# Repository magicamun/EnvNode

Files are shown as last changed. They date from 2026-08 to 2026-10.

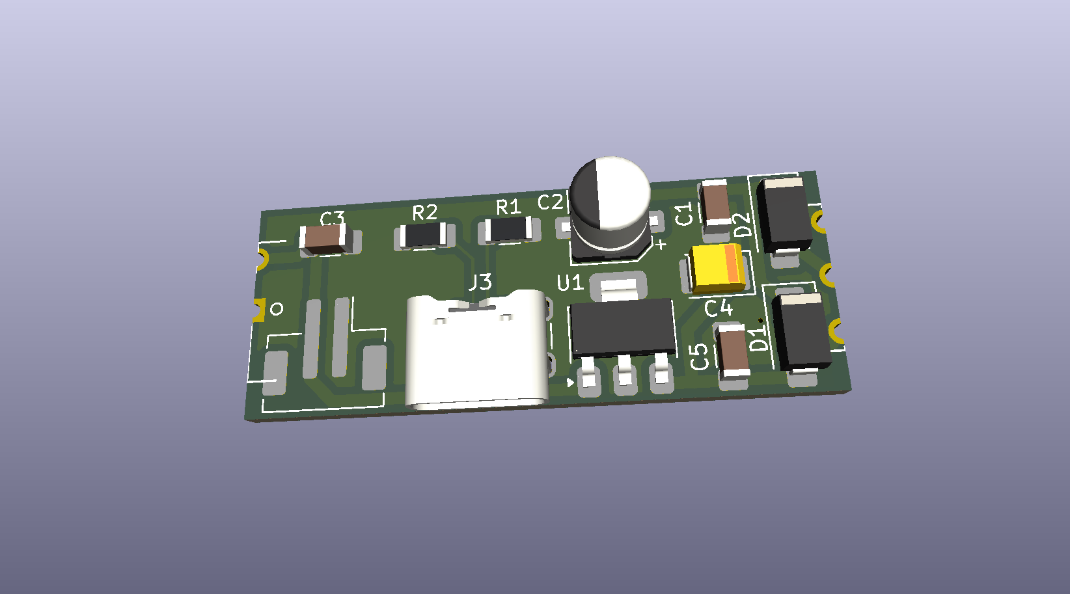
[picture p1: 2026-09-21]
hardware/kicad/DesignBlocks/ORing Power/Documentation/ORing_Power_3D.png

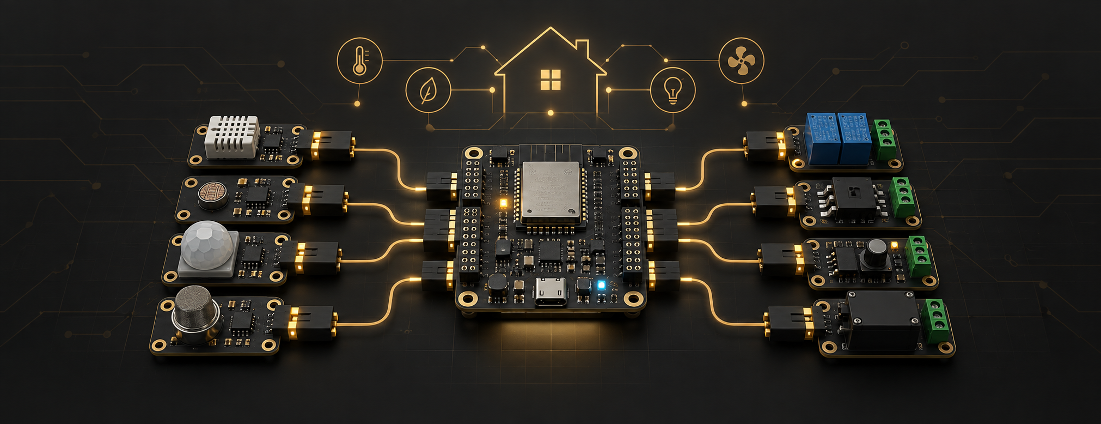
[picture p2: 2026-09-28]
images/branding/envnode-hero-modular-v1.png

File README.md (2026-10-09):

# EnvNode

EnvNode is an source-available ESP32-based embedded platform for reliable environmental measurements and seamless integration into modern home automation systems.

WeatherStation is the first reference application built on the reusable EnvNode platform.

The project intentionally separates **measurement** from **interpretation**.

The firmware is responsible for acquiring reliable physical Measurements and publishing them to external systems.

Higher-level concepts such as weather interpretation, historical aggregation, evapotranspiration (ETo), irrigation logic and visualization intentionally remain outside the firmware.

EnvNode is developed as a complete source-available product including:

- firmware
- hardware (KiCad)
- documentation
- development tooling

The goal is not to build another weather dashboard.

The goal is to build a reliable measurement platform.

---

# Vision

EnvNode provides an open, transparent and extensible weather sensor platform for Home Assistant and other home automation systems.

The ESP32 acts as a dedicated measurement node.

It acquires physical sensor data, performs only the hardware-related processing required to obtain reliable Measurements and publishes them via MQTT.

The firmware intentionally remains deterministic, maintainable and independent from weather-specific interpretation.

This allows higher software layers to evolve independently while keeping the embedded firmware simple and robust.

---

# Why another weather station?

The project originated from practical experience with an existing DIY weather station.

Although the hardware proved to be reliable, several software aspects became increasingly problematic:

- closed-source firmware
- undocumented algorithms
- incorrect sunshine duration calculation
- embedded rain aggregation
- limited extensibility
- unclear separation between measurement and interpretation

Rather than replacing individual algorithms, the firmware was redesigned from first principles around a small number of architectural rules.

---

# Core Philosophy

The EnvNode project follows one simple principle:

> Measure first.
>
> Interpret later.

The firmware exists to acquire reliable Measurements.

Interpretation belongs to external systems.

---

# Project Goals

- source-available firmware with a commercial exploitation reservation
- available hardware design sources (KiCad)
- MQTT-based integration
- browser-based configuration
- OTA firmware updates
- modular architecture
- high-quality Measurements
- deterministic firmware behaviour
- long-term maintainability
- simulation support
- comprehensive documentation
- hardware independence

---

# Design Principles

The project follows a small number of architectural principles.

### Measure, don't interpret

The firmware measures physical reality.

Interpretation belongs outside the Device.

---

### One technical responsibility per service

Each infrastructure service owns exactly one technical responsibility.

Examples include:

- Configuration
- WiFi
- Time
- MQTT

---

### Sensors produce Measurements

Sensors do not publish MQTT.

Sensors do not interpret weather.

Sensors produce Measurements.

### Controllers coordinate Actuators through capabilities

Controllers implement cooperative local behavior and address configured Actuators by `ActuatorId` and capability. They do not manipulate GPIO or use MQTT as an internal control path.

---

### Configuration has one authoritative owner

Configuration exists exactly once inside the runtime.

Every subsystem uses the same Configuration.

---

### Simulation is part of the architecture

Simulated and physical Sensors follow the same processing pipeline.

Replacing a simulated Sensor with a physical implementation must not require architectural changes.

---

### Observable behaviour

Whenever practical, internal decisions should be visible through:

- diagnostics
- logging
- MQTT status

The firmware should never behave like a black box.

---

### Deterministic firmware

The firmware intentionally avoids executing complex weather models.

Embedded software should remain predictable and responsive.

---

### Hardware independence

Application logic depends on abstract Sensor behaviour rather than concrete hardware implementations.

Replacing a Sensor should require only a new driver.

---

# Current Status

Implemented

- ESP32 PlatformIO project
- persistent configuration
- browser-based provisioning
- WiFi connectivity
- automatic WiFi reconnect
- setup access point
- configurable hostname
- SNTP time synchronization
- configurable timezone
- MQTT connectivity
- authenticated MQTT client
- factory reset and OTA firmware update
- typed Measurement pipeline and MQTT publication
- fixed Sensor slots, physical/simulated implementations and live runtime composition
- Sensor Home Assistant discovery
- EEPROM-backed Board Identity, boot-time profile resolution and development fallback
- Board Identity diagnostics and confirmed Web provisioning with readback verification
- independent Module Identity discovery for both slots, immutable module profiles and
  board/slot compatibility diagnostics without automatic driver activation
- fixed Actuator slots and unified hardware validation
- OnOff capability and GPIO On/Off Actuator
- Level capability and GPIO PWM Actuator
- live Actuator runtime rebuild
- Web and MQTT Actuator configuration/control
- fixed Controller slots and BlinkController
- ThresholdController with typed Measurement input, hysteresis and monotonic freshness
- cooperative Controller runtime and live rebuild
- Web and MQTT Controller configuration, status and Start/Stop
- persistent MQTT Blink/Threshold parameter commands and retained parameter state
- retained external Actuator and Controller descriptions
- exclusive enabled-Controller ownership of Actuator targets
- physically verified Sensor -> Measurement -> Controller -> Actuator operation

Current hardware-validation focus

- provision and boot from the Board Identity EEPROM on a physical Mainboard revision 0.3
- complete the Revision 0.3 article list and assembly data
- assemble and bring up the AnalogHydroPressure module, including its local 5 V to 24 V supply
- integrate and calibrate the ADS1115-based 4–20 mA pressure input on real hardware
- operate at least the Rain Detector heater path before releasing Revision 0.3 for production

Deliberately future

- additional Actuator capabilities beyond OnOff and Level, and additional typed Controller implementations
- multi-input, Boolean/contact and event-driven Controllers
- richer manual-versus-Controller arbitration
- Controller and generic Actuator Home Assistant discovery
- a dedicated provisioning station for preparing Mainboards, Modules, and other supported boards

---

# Documentation

Project documentation is intentionally separated by responsibility.

| Document | Purpose |
|---|---|
| README.md | Project overview |
| DomainModel.md | Functional domain concepts |
| TechnicalArchitecture.md | Technical architecture |
| ActuatorModel.md | Actuator capabilities and Controller interaction |
| MQTT.md | Current MQTT protocol boundaries and topics |
| Hardware.md | Hardware entry point, module templates, and implemented boards |
| ADRs | Architectural decisions |

---

# Non Goals

EnvNode intentionally does not:

- perform weather forecasting
- calculate evapotranspiration (ETo)
- calculate sunshine duration
- aggregate historical weather data
- store long-term measurements
- replace Home Assistant

These responsibilities belong to higher software layers.

---

# Project Status

The Sensor, Actuator and Controller architecture is implemented and physically verified. Current open work concerns further capabilities, Controller implementations and external self-description rather than replacing these runtime boundaries.

# License and permitted use

EnvNode-owned materials are provided under the [EnvNode Use and Redistribution
License, version 1.0](LICENSE). Private and internal business use, modifications,
free redistribution, and paid fabrication or maintenance for the user's own use
are permitted. Commercial product sales, licensing, rental, and standalone paid
software hosting require separate permission. Third-party materials retain their
respective licenses. This is a custom source-available license, not an
OSI-approved open-source license. The German license text is authoritative.

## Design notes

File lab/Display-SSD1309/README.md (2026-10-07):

# SSD1309 I2C Display Lab

Eigenständiger Hardwaretest für das vorhandene 2,42-Zoll-OLED (128 × 64,
Platinenaufdruck `2.42OLED-IIC VER:1.1`). Die gescannte 7-Bit-Adresse ist
`0x3C`. SSD1309 NONAME2 ist zunächst eine zu prüfende Controllerannahme.
Keine Abhängigkeit von der EnvNode-Firmware; keine NVS-Konfiguration.

## Anschluss

Lab-Vorgaben für einen klassischen ESP32 (`esp32dev`):

| Display | ESP32 | Kabelfarbe auf dem Foto |
| --- | --- | --- |
| GND | GND | Weiß |
| VDD | Versorgung gemäß Modul-Spezifikation | Gelb |
| SCL | GPIO 22 | Schwarz |
| SDA | GPIO 21 | Rot |

Pins, Adresse und Bustakt (100 kHz) stehen in `include/LabConfig.h`.
Die Versorgungsspannung ist durch das Foto nicht belegt. Am ESP32 müssen
SDA/SCL mit 3,3-V-Pegeln arbeiten; etwaige Modul-Pull-ups berücksichtigen.
Die Lab-Pins müssen auf dem Testaufbau frei sein.

## Testbild und Auswertung

Sechs feste Beispielzeilen, Font `u8g2_font_t0_11_tf`, Baselines bei
10, 20, 30, 40, 50 und 60 Pixeln. Datum und Messwerte sind Testtexte,
keine Uhr oder echten Messwerte. Rotation ist `U8G2_R0`.

Der Start prüft zunächst ein ACK an `0x3C`. Ohne ACK werden keine
Displaybefehle gesendet. Mit ACK wird die Seite einmal übertragen.
Ein ACK bestätigt lediglich einen Teilnehmer, nicht den Controllertyp oder
eine erfolgreiche Darstellung. U8g2 erhält die Adresse als `0x3C << 1`.
Im seriellen Monitor erscheinen die Pixelbreiten aller sechs Zeilen.

Prüfen: Sind alle sechs Zeilen vollständig, lesbar und richtig ausgerichtet?
Bleibt das Display trotz ACK leer oder zeigt es Müll, Controller/Variante
anhand Produktunterlagen prüfen. Ein erfolgreicher Build bestätigt die
Hardwareannahme nicht. Für 180° Rotation `U8G2_R0` durch `U8G2_R2` ersetzen.

## Build und Flash

PlatformIO: Espressif32 7.0.1, Arduino, U8g2 2.36.12.
Vom Repository-Root:

```sh
pio run -d lab/Display-SSD1309
pio device list
pio run -d lab/Display-SSD1309 -t upload --upload-port /dev/cu.usbserial-1
pio device monitor -p /dev/cu.usbserial-1 -b 115200 --filter direct
```

Falls nötig `~/.platformio/penv/bin/pio` verwenden und den Port ersetzen.
Flashen ersetzt die laufende Firmware des gewählten ESP32. Nach Öffnen des
Monitors ggf. Reset drücken. Der Nutzer hat den Lab-Test auf dem vorhandenen Modul erfolgreich geflasht und
die Darstellung bestätigt.

Referenz: [U8g2-Konstruktoren](https://github.com/olikraus/u8g2/wiki/u8g2setupcpp#ssd1309-128x64_noname2).

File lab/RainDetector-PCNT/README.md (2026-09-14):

# RainDetector PCNT Lab-Firmware

Eigenständiger PoC für den digitalen 3,3-V-Ausgang eines ICM7555.
Keine Abhängigkeit von `firmware/`, keine EnvNode-Sensorintegration, kein
MQTT, keine Wetterinterpretation, Kapazitätsberechnung oder Heater-Steuerung.

## Projekt und Toolchain

Die produktive PlatformIO-Konfiguration verwendet `esp32dev`, Arduino und eine
ungepinnte `espressif32`-Plattform. Dieses Lab-Projekt fixiert die bei der
Implementierung installierte Plattform auf **7.0.1**. Der geprüfte Build nutzt
Arduino-ESP32 **2.0.17** (Paket `3.20017.241212+sha.dcc1105b`) und dessen
ESP-IDF **4.4.7**. Es benötigt keine zusätzlichen Bibliotheken.

Verwendet wird die klassische API aus `driver/pcnt.h`, PCNT Unit 0 / Channel 0:
`pcnt_unit_config`, `pcnt_counter_clear`, `pcnt_counter_resume`,
`pcnt_counter_pause` und `pcnt_get_counter_value`.
Steigende Flanken inkrementieren; fallende Flanken werden ignoriert.
Filter und CPU-PCNT-Interrupts sind deaktiviert. Es gibt keine ISR,
kein `pulseIn()` und keine GPIO-Abfrageschleife.

Referenz: [Espressif PCNT API für ESP-IDF 4.4](https://docs.espressif.com/projects/esp-idf/en/v4.4/esp32/api-reference/peripherals/pcnt.html).

## Anschluss und Konfiguration

- ICM7555 `RAIN_FREQ` (digital, 3,3 V) an **GPIO 27** des klassischen ESP32.
- Gemeinsame Masse zwischen RainDetector und ESP32 herstellen.
- Keine 5-V-Signale einspeisen. GPIO 27 muss auf dem verwendeten Aufbau frei sein.
- Heater separat unbeschaltet bzw. hardwareseitig ausgeschaltet halten;
  diese Firmware initialisiert keinen Heater-Ausgang.
- GPIO, Messfenster und Baudrate stehen zentral in `include/LabConfig.h`.
  GPIO 27 ist eine Lab-Vorgabe, keine Zuordnung aus einem EnvNode-Boardprofil.
- Getestetes Build-Ziel ist `esp32dev`, nicht ESP32-C3/S3 oder andere Varianten.

## Messung und Grenzen

Der Zähler wird bei pausierter Messung gelöscht, dann gestartet und nach
nominell **250.000 µs** angehalten. Währenddessen gibt `delay(1)` CPU-Zeit frei;
PCNT zählt unabhängig weiter. Die Dauer wird über `esp_timer_get_time()` direkt
vor Resume und direkt nach Pause erfasst. Die Rechnung lautet:

`frequency_hz = pulse_count * 1000000.0 / (end_us - start_us)`

Das reale Fenster ist durch Task-Scheduling etwas länger als 250 ms und nicht
hardwaregenau getaktet. Die Zeitmessung umfasst zusätzlich den kleinen Aufwand
der Resume-/Pause-Aufrufe; sie ist eine Näherung der tatsächlichen Zählzeit.
Eine konkrete Dauer am Zielgerät wurde noch nicht gemessen. Drei Nachkommastellen
der Ausgabe sind keine Genauigkeitszusage: die Zählauflösung liegt bei etwa 4 Hz
pro Puls; hinzu kommen Gate-Timing- und ESP32-Taktfehler.

Serial-Ausgabe und Reset passieren zwischen den Fenstern. Es gibt daher eine
kurze Messpause; Zeitstempelabstände sind nicht gleich der Zählfensterdauer.
Die Firmware misst Fensterfrequenzen, keinen lückenlosen Gesamtpulszähler.

Der 16-Bit-PCNT setzt beim oberen Limit von 32767 Pulsen auf null zurück.
Um dann keine falsche niedrige Frequenz auszugeben, wird ausschließlich das
High-Limit-Ereignis aktiviert. Dessen gelatchtes Raw-Interrupt-Bit wird nach
Pause geprüft und vor jedem Fenster gelöscht (`PCNT.int_raw` / `PCNT.int_clr`,
klassische ESP32-Register). Dafür wird kein CPU-Interrupt aktiviert.
Ein Überlauf ergibt `nan` statt einer Frequenz; `pulse_count` ist dann nur der
Restzählerstand. Bei 250 ms liegt die Grenze ungefähr bei 131 kHz, bei längeren
Fenstern entsprechend niedriger. Für einige 10 kHz reicht der Zähler aus.

## Serial-Format

115200 Baud, 8N1. Einmalig nach Initialisierung:

```csv
timestamp_ms,pulse_count,frequency_hz
```

Danach eine Zeile je Fenster mit dezimalem Punkt und drei Nachkommastellen.
`timestamp_ms` bezeichnet das Fensterende in Millisekunden seit Boot.
Beispielwerte (keine reale Hardwaremessung):

```csv
1250,10000,40000.000
1505,0,0.000
1760,123,nan
```

Ohne Flanken ist das Ergebnis null; ein fehlendes Signal lässt sich daraus
nicht von einem stillstehenden Oszillator unterscheiden. Bei einem API-Fehler
erscheint `# error,<operation>,<ESP-Fehlername>` und die Messung stoppt bis Reset.
ESP32-ROM-Bootmeldungen können vor dem CSV-Header erscheinen. Für Auswertung
erst ab dem Header lesen und Fehlerzeilen bzw. `nan` behandeln.

## Build, Flash und Test

Vom Repository-Root aus (falls `pio` nicht im PATH liegt:
`~/.platformio/penv/bin/pio` verwenden):

```sh
pio run -d lab/RainDetector-PCNT
pio device list
pio run -d lab/RainDetector-PCNT -t upload --upload-port /dev/cu.usbserial-0001
pio device monitor -p /dev/cu.usbserial-0001 -b 115200 --filter direct
```

Den Beispielport durch den tatsächlichen ESP32-Port ersetzen. Flashen ersetzt
die aktuell auf diesem ESP32 laufende Firmware. Nach Öffnen des Monitors bei
Bedarf Reset drücken, um den CSV-Header zu erfassen.

Zunächst Signal und gemeinsame Masse verbinden, dann die Frequenz mit
Oszilloskop/Frequenzzähler vergleichen. Optional einen bekannten 3,3-V-Takt
einspeisen: 40 kHz sollten bei ungefähr 250 ms ungefähr 10000 Pulse ergeben,
unabhängig vom Tastverhältnis (innerhalb der PCNT-Eingangsgrenzen).
Mit auf GND gelegtem Eingang müssen null Pulse erscheinen. Optional mit
150 kHz testen: die Frequenz muss `nan` werden. Den ICM7555-Ausgang vor
Einspeisung eines externen Testtakts trennen.

Build und Quellcodeprüfung sind erfolgt; Flashen und Hardwaretests sind noch
nicht durchgeführt worden.

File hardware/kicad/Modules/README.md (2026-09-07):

# EnvNode Revision 0.3 Modules

This directory contains the current module templates and functional daughterboards for the EnvNode Revision 0.3 module interface. The electrical connector contract was introduced with Revision 0.2 and is retained by the current Revision 0.3 designs.

## Functional Modules

- [FullSize/AnalogHydroPressure](FullSize/AnalogHydroPressure/README.md): ADS1115-based 4–20 mA pressure input with a local 5 V to 24 V boost supply.
- [FullSize/DuoRelay](FullSize/DuoRelay/README.md): two independently controlled 5 V changeover relays.

## Starting Templates

| Size | Bottom-mounted connector |
| --- | --- |
| [FullSize/Empty-SMD](FullSize/Empty-SMD/README.md) | SMD |
| [FullSize/Empty-THT](FullSize/Empty-THT/README.md) | THT |
| [HalfSize/Empty-SMD](HalfSize/Empty-SMD/README.md) | SMD |
| [HalfSize/Empty-THT](HalfSize/Empty-THT/README.md) | THT |

New modules must follow the [module-interface hardware specification](../../../docs/EnvNode_Module_Interface_Hardware_Specification.md). Copy the appropriate template instead of modifying it in place, preserve the connector pin mapping and mechanical reference geometry, and rerun ERC and DRC after every functional or layout change.

## Release Status

Revision 0.3 is not yet released for production. Release requires a complete article list and assembly information, physical bring-up of the relevant boards, and successful operation of at least the Rain Detector heater path. A later provisioning station is intended to prepare Mainboards, Modules, and other supported boards with their identities and required initial data.

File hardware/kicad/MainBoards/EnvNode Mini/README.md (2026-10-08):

# EnvNode Mini

`EnvNode Mini` is the compact EnvNode mainboard with two module slots, ESP32 processing, dual I²C access, configurable I²C pull-ups, and two direct ADC/GPIO inputs. This directory contains the KiCad design for hardware Revision 0.8.

## Project Files

- `EnvNode Mini.kicad_pro`
- `EnvNode Mini.kicad_sch`
- `EnvNode Mini.kicad_pcb`
- `SlotA.kicad_sch`
- `SlotB.kicad_sch`
- `ESP32Core.kicad_sch`
- `PCB.kicad_sch`
- `Power.kicad_sch`
- `ADC.kicad_sch`
- `Documentation/EnvNode_Mini_Bestueckungs_und_Bringup_Rev0.8.pdf`

KiCad lock and local preference files are working files and must not be committed.

## Revision 0.8

Revision 0.8 adds two top-entry 4-pin JST-PH connectors. Connector `ADC1` exposes GPIO34 / ADC1_CH6 and connector `ADC2` exposes GPIO35 / ADC1_CH7. Their shared pin order is GND, `+5V`, signal, `+3V3_SYS`.

GPIO34 and GPIO35 are input-only ESP32 pins without internal pull-up or pull-down resistors. They are not 5 V tolerant. The `+5V` connector pin is available only as sensor power; any signal returned to connector pin 3 must remain inside the ESP32 3.3 V input range. Firmware must not configure these resources as outputs.

Final checks on 2026-09-29: ERC has zero findings. PCB DRC with zone refill has no active violations or unconnected pads, and schematic/PCB parity is clean. The report contains 18 documented exclusions for known courtyard and silkscreen interactions; none concerns copper clearance, connectivity, or the new ADC nets.

## Revision 0.7

Revision 0.7 corrects I2C0 on both module slots to pin 5 SDA and pin 6 SCL, matching the module-interface specification and daughterboards. The corrected MainBoard connector design block is incorporated. Connector and mounting-hole positions are unchanged. AUX_GPIO1 remains GPIO33 in Slot A and GPIO32 in Slot B.

Final checks on 2026-09-28: ERC has zero findings; PCB DRC with zone refill has no unconnected pads or schematic/PCB parity issues. Two active silkscreen-over-solder-mask warnings remain at U2 pads 3 and 5; sixteen other findings are excluded in the project. This is not a zero-warning manufacturing release.

## Revision 0.6

Revision 0.6 restructures the mainboard around reusable hierarchical design blocks. The 5 V input protection, regulator, and 3.3 V source ORing are provided by the castellated `ORing Power` module (`U2`) instead of being assembled directly on the mainboard. The ESP32 core contains the `24LC32` mainboard-identity EEPROM (`U1`) on `I2C0` at address `0x50` on the `+3V3_SYS` supply. C1 (100 nF) is connected between `+5V` and GND and decouples the 5 V supply. The identity EEPROM has no separate local decoupling capacitor; this arrangement is identical on EnvNode Mini and EnvNode Weather.

The two module slots continue to implement the shared EnvNode module interface. Net ties set Slot A `EEPROM_A0` to GND and Slot B `EEPROM_A0` to `+3V3_SYS`, assigning the optional module EEPROM addresses `0x52` and `0x53`. Each I²C bus is available on two top-entry, four-pin JST-SH connectors. Individually configurable 4.7 kΩ pull-ups remain normally disconnected through solder jumpers.

The mainboard itself no longer carries a USB or raw 5 V input connector. Power is connected to the fitted ORing Power module; its assembly and input-source rules apply to the complete unit. The module's `+3V3_EXT` interface pin is intentionally not connected on this mainboard revision.

## Module GPIO assignment

| Slot | Pin 9 / AUX_GPIO1 | Pin 10 / AUX_GPIO2 | Pin 14 / SPI_CS |
| --- | --- | --- | --- |
| A | GPIO33 (ADC1_CH5) | GPIO13 | GPIO5 |
| B | GPIO32 (ADC1_CH4) | GPIO14 | GPIO27 |

AUX_GPIO1 supports digital input, digital output/PWM, or analog input while Wi-Fi is active. AUX_GPIO2 supports digital input and output/PWM; its ADC2 function is not available during Wi-Fi operation. GPIO4 and GPIO16 are now unconnected. Firmware slot mappings must follow this assignment.

Revision 0.7 slot wiring is I2C0 SDA on pin 5 and SCL on pin 6, matching AnalogHydroPressure and SX1262-Remote.

## Validation

Run schematic ERC and PCB DRC after every schematic, footprint, routing, zone, or rule change. Revision 0.8 still requires physical bring-up and production validation; the KiCad consistency checks do not replace electrical, thermal, EMC, ESD, or manufacturing tests. The current assembly and bring-up procedure is in `Documentation/EnvNode_Mini_Bestueckungs_und_Bringup_Rev0.8.pdf`.

See the [hardware overview](../../../../docs/Hardware.md), [module-interface specification](../../../../docs/EnvNode_Module_Interface_Hardware_Specification.md), and [board identity record](../../../../docs/BoardIdentityRecord.md).

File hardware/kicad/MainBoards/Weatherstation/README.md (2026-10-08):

# EnvNode Weather

`EnvNode Weather` is the EnvNode mainboard for a fixed weather-station installation. It combines an ESP32-DevKitC, one EnvNode module slot, two externally accessible I2C buses, and dedicated GPIO/ADC sensor connectors. This directory contains the KiCad design for hardware Revision 0.2.

## Project Files

- `Weatherstation.kicad_pro`
- `Weatherstation.kicad_sch`
- `ESP32.kicad_sch`
- `gpio.kicad_sch`
- `PCB.kicad_sch`
- `Power.kicad_sch`
- `qwiic.kicad_sch`
- `SlotA.kicad_sch`
- `Documentation/EnvNode_Weather_Bestueckungs_und_Bringup_Rev0.2.pdf` - current assembly and bring-up guide

KiCad lock, backup, autosave, and local preference files are working files and must not be committed.

## Revision 0.2

Revision 0.2 corrects module-slot I2C0 to pin 5 SDA and pin 6 SCL in both schematic and PCB. This matches the module-interface specification, Mini Revision 0.7, AnalogHydroPressure, and SX1262-Remote. Component positions and rotations, including the module connector and mounting holes, are unchanged.

Final checks on 2026-09-28: schematic ERC has zero findings. PCB DRC with zone refill has zero unconnected pads, zero schematic/PCB parity issues, and no non-excluded violations. Three existing exclusions remain: two courtyard overlaps beneath the DevKit and one silkscreen-over-solder-mask warning at the power module.

## Revision 0.1

Revision 0.1 uses reusable hierarchical design blocks for the board geometry, ESP32 core, power carrier, and module slot. The 5 V input protection, regulator, and 3.3 V source ORing are provided by the castellated `ORing Power` module (`U1`). The ESP32 core contains the `24LC32` mainboard-identity EEPROM (`U2`) on `I2C0` at address `0x50`. C1 (100 nF) is connected between `+5V` and GND and decouples the 5 V supply. The identity EEPROM is supplied from `+3V3_SYS` and has no separate local decoupling capacitor; this arrangement is identical on EnvNode Mini and EnvNode Weather.

The module connector `J1` implements the shared EnvNode module interface. Connector pin 3 is tied to GND, assigning an optional module EEPROM in Slot A to address `0x52`.

Each I2C bus is available on four top-entry, four-pin JST-SH connectors. Individually configurable 4.7 kOhm pull-ups are normally disconnected through solder jumpers. Ten top-entry JST-PH connectors expose `ADC1` through `ADC4` and `GPIO14`, `GPIO16`, `GPIO17`, `GPIO27`, `GPIO32`, and `GPIO4`. Their common pin order is GND, `+5V`, signal, `+3V3_SYS`.

The board itself does not carry a USB or raw 5 V input connector. Power is connected to the fitted ORing Power module; its assembly and input-source rules apply to the complete unit. The module's `+3V3_EXT` interface pin is intentionally not connected on this mainboard revision.

The PCB outline and enclosure holes use the `BOX4U-5U310700` geometry. H1 and H2 are M2.5 module-support holes; H3 through H6 are the 4.5 mm enclosure mounting holes.

## Module GPIO assignment

Slot A uses GPIO33 (ADC1_CH5) on pin 9 / AUX_GPIO1 and GPIO13 on pin 10 / AUX_GPIO2. AUX_GPIO1 supports digital input, digital output/PWM, or analog input with Wi-Fi active. GPIO4 replaces GPIO33 on the separate JST-PH connector. GPIO32 remains on its separate connector; ADC1 through ADC4 remain GPIO34, GPIO35, GPIO36, and GPIO39. Firmware mappings must reflect the swap.

Revision 0.2 connects I2C0 SDA to pin 5 and SCL to pin 6. The earlier reversed assignment is corrected.

## Validation

Run schematic ERC, PCB DRC, and schematic-PCB parity checks after every schematic, footprint, routing, zone, or rule change. Revision 0.2 still requires physical bring-up and production validation; the KiCad consistency checks do not replace electrical, thermal, EMC, environmental, or manufacturing tests. The current procedure is in `Documentation/EnvNode_Weather_Bestueckungs_und_Bringup_Rev0.2.pdf` (5 October 2026). It includes the corrected I2C0 and GPIO assignments, passive continuity checks, the corrected C1 description, and SHA-256 fingerprints of the KiCad sources. The recorded ERC/DRC results are the historical checks of 28 September 2026, not a new validation run. The Revision 0.1 PDF remains as a historical reference.

See the [hardware overview](../../../../docs/Hardware.md), [module-interface specification](../../../../docs/EnvNode_Module_Interface_Hardware_Specification.md), [ORing Power documentation](../../DesignBlocks/ORing%20Power/README.md), and [board identity record](../../../../docs/BoardIdentityRecord.md).

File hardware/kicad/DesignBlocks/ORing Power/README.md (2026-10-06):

# ORing Power Module

The ORing Power module is a 39 mm x 15 mm castellated daughterboard for EnvNode mainboards. It combines the external 5 V input, the 3.3 V regulator, and the diode ORing between the regulator output and the ESP32 DevKit 3.3 V rail. Mainboards use the matching carrier footprint and no longer need to reproduce this circuit locally.

## Project and Library Items

- Editable KiCad project: `hardware/kicad/DesignBlocks/ORing Power/`
- Published design block: `hardware/kicad/Libraries/EnvNodeDesignBlocks.kicad_blocks/ORing Power.kicad_block/`
- Mainboard symbol: `EnvNode-Symbols:ORingPower_Module`
- Module footprint: `EnvNode-Footprints:ORingPower_Module_Castellated`
- Mainboard carrier footprint: `EnvNode-Footprints:ORingPower_Carrier`
- Assembly and bring-up guide: `Documentation/ORing_Power_Bestueckungs_und_Bringup_Rev0.1.pdf`

The symbol defaults to the carrier footprint. The ORing Power PCB itself overrides that assignment with the module-side castellated footprint.

## Electrical Function

The module accepts 5 V through either the two-pin JST-PH connector or the USB-C connector. These two 5 V inputs share the same `+5V` net and are not isolated from one another. Do not connect independent supplies to both connectors unless they are explicitly suitable for direct parallel operation.

The LM3940 generates `+3V3_EXT` from `+5V`. Two SS14 Schottky diodes combine `+3V3_EXT` and the mainboard-provided `+3V3_DEVKIT` rail into `+3V3_SYS`. The topology prevents either 3.3 V source from feeding back into the other through the ORing path.

The USB-C connector is the six-contact, power-only GCT `USB4125-GF-A-0190`. `CC1` and `CC2` each have their own 5.1 kΩ pull-down resistor to GND. The connector does not expose USB data signals and does not implement USB Power Delivery negotiation; it requests the standard USB-C 5 V source mode only.

## Castellated Interface

| Pin | Net | Module direction | Function |
| ---: | --- | --- | --- |
| 1 | `GND` | Common | Ground |
| 2 | `+5V` | Output to mainboard | Shared 5 V input rail |
| 3 | `+3V3_EXT` | Output to mainboard | LM3940 regulator output before ORing diode |
| 4 | `+3V3_DEVKIT` | Input from mainboard | ESP32 DevKit 3.3 V source before ORing diode |
| 5 | `+3V3_SYS` | Output to mainboard | ORed system 3.3 V rail |

Pin numbers, net names, pad positions, and module orientation are contractual. A carrier PCB must use the matching carrier footprint without moving individual pads.

## Mechanical Integration

The module is soldered directly onto the mainboard using the five castellated edge pads. The carrier footprint reserves the 39 mm x 15 mm module outline and provides matching mainboard pads. Before releasing a mainboard, verify:

- the module outline and nearby component courtyards do not overlap;
- the USB-C opening is reachable at the intended enclosure edge;
- sufficient solder fillet is accessible at every castellated pad;
- no mainboard copper, vias, or components occupy the reserved module area; and
- the assembly process supports castellated-hole soldering on the selected PCB finish and thickness.

The castellated-hole geometry must be confirmed with the PCB manufacturer before the first production order. Fabrication outputs must identify the edge-plated half holes correctly; ordinary routed holes without edge plating are not an equivalent substitute.

## Component Notes

| Reference | Function | Important assignment |
| --- | --- | --- |
| J3 | USB-C 5 V input | GCT `USB4125-GF-A-0190`; KiCad six-pin power-only footprint |
| R1, R2 | USB-C Rd | 5.1 kΩ each, one resistor per CC pin |
| J1 | Alternate 5 V input | JST `B2B-PH-SM4-TB`, two-pin, vertical SMD; KiCad footprint `JST_PH_B2B-PH-SM4-TB_1x02-1MP_P2.00mm_Vertical` |
| U1 | 3.3 V regulator | `LM3940IMP-3.3/NOPB`, SOT-223 |
| D1, D2 | 3.3 V source ORing | SS14, SMA |
| C1, C5 | Local bypass | 100 nF, 1206 |
| C2 | Regulator output capacitor | 10 µF electrolytic, `CP_Elec_5x5.4`; polarity required |
| C3 | 5 V input capacitor | 10 µF ceramic, 1206 |
| C4 | System rail bulk capacitor | 47 µF tantalum, EIA-3528-21; polarity required |

## Mainboard Use

1. Place `EnvNode-Symbols:ORingPower_Module` in the mainboard schematic.
2. Keep its default `EnvNode-Footprints:ORingPower_Carrier` footprint.
3. Connect all five named rails according to the interface table.
4. Update the PCB from the schematic and place the complete carrier footprint at the intended board edge.
5. Remove the former discrete ORing-power circuit and verify that no duplicate regulator, diode, USB-C, or input components remain.
6. Run ERC, PCB/schematic parity, DRC, and a visual 3D/mechanical review on the completed mainboard.

Do not place the module-side castellated footprint on the mainboard. Do not use the carrier footprint as the outline of a separately fabricated ORing Power PCB.

## Validation Status

Checked with KiCad 10 on 2026-09-21:

- schematic ERC: 0 errors, 0 warnings;
- PCB DRC: 0 violations and 0 unconnected items;
- all seven electrical nets have zero unrouted connections;
- USB VBUS, GND, shield, CC1, and CC2 map to the expected footprint pads;
- the GCT USB4125 footprint is aligned with the PCB edge; and
- the editable source and published library block are synchronized.

This validation covers design consistency, not physical manufacture. The first fabricated module still requires continuity, polarity, 5 V input, 3.3 V regulation, source handover, reverse-current, thermal, USB-C insertion, and castellated-solder-joint tests.

## Documentation verification — 2026-10-05

The Revision 0.1 assembly guide now carries current PCB, schematic, and parts-workbook hashes. The PCB has no formal title-block revision; 0.1 is the existing documentation designation. Compared with the previously documented PCB, only plot settings, an empty settings block, and serialization order changed; board geometry and circuitry are unchanged. The existing 3D reference view remains valid.

The guide previously swapped the diode references in its functional description and tests: D1 connects `+3V3_EXT` to `+3V3_SYS`, while D2 connects `+3V3_DEVKIT` to `+3V3_SYS`. These references are corrected. PCB pad nets were checked against an exported schematic netlist and matched. This documentation check did not repeat full ERC/DRC or physical testing.

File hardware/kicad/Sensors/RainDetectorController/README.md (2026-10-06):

# EnvNode RainDetector Controller — Revision 0.3

ICM7555 frequency measurement front end at 3.3 V and AO3400A low-side heater
switch. Timing resistors are 10 kohms and 100 kohms; C1 is the 100 nF supply
bypass. The 5 V heater path uses 0.8 mm tracks and must supply approximately
417 mA for RainDetectorHead revision 0.1, in addition to other system loads.

J1/J2 2x2 sockets are on B.Cu, facing the head; controller components are on F.Cu
for access from the enclosure interior. The board is 62.12 x 44.12 mm.
See `../RainDetectorHead/README.md` for the complete mating table.

J3: 1 GND, 2 +5V, 3 HEATER_EN, 4 +3V3.
J4: 1 GND, 2 +5V, 3 RAIN_FREQ, 4 +3V3.
The supply pins are shared. J3/J4 are currently marked DNP in the schematic
and generated BOM; retain or change this deliberately for the intended
connector/assembly option. Concrete connector part numbers and mating height
still need selection and verification.

`RainDetectorController.csv` is generated from the current schematic:

```sh
kicad-cli sch export bom --group-by Value,Footprint -o RainDetectorController.csv RainDetectorController.kicad_sch
```

Current assembly guide: `Documentation/RainDetectorController_Bestueckungs_und_Bringup_Rev0.3.pdf` (document date 2026-10-05).

Historical reference/bring-up PDFs remain in `../Raindetector/Documentation/`.
They are NOT revision 0.3 assembly guides. The old `../Raindetector/` project
remains as the previous prototype; local copied PDFs need not be duplicated
in version control.

## Validation

For each of the two projects, run from its directory:

```sh
kicad-cli sch erc -o /tmp/rain-erc.txt PROJECT.kicad_sch
kicad-cli pcb drc --schematic-parity --refill-zones -o /tmp/rain-drc.txt PROJECT.kicad_pcb
```

Replace PROJECT with RainDetectorController or RainDetectorHead. Checked with
KiCad 10.0.5. Standard project-disabled checks (such as missing courtyards)
remain as configured; these commands do not constitute fabrication approval.
The lab firmware in `lab/RainDetector-PCNT/` measures rising edges via ESP32
PCNT and reports raw frequency over Serial. No heater automation is included.

Final checks on 2026-09-14: both projects passed ERC and DRC with zero
errors/warnings, zero unconnected items and zero schematic parity issues.
The Head GND power flag and C1-only 0.10 mm clearance rule are included.

## Documentation verification — 2026-10-05

The current PCB outline is 62.12 x 44.12 mm and J1/J2 use 2x2 sockets. The BOM was regenerated to replace stale 1x4 entries. PCB pad nets and the exported schematic netlist match. On both current projects J2.1 is SENSE and J2.4 is HEATER-; verify mechanical contact alignment and mating height separately.

The historical 2026-09-14 ERC/DRC results predate the connector/outline changes committed on 2026-09-15 (0d3a50b). This documentation update does not repeat full ERC/DRC or physical testing. The PDF includes current source hashes, assembly orientation, connector tables, separate frequency/heater bring-up, and a measurement record.

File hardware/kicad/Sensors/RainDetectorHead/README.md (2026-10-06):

# EnvNode RainDetector Head — Revision 0.1

Passive capacitive sensor head with two soldermask-covered interdigitated
F.Cu electrodes and twenty 15-ohm 1206 heater resistors on B.Cu.
The five parallel strings of four resistors give 12 ohms, approximately
417 mA and 2.08 W at 5 V (0.104 W per resistor). Select resistors rated at
least 0.25 W and check their temperature derating.

The controller and head are separate fabrication projects with independent
revisions. This head is paired with RainDetectorController revision 0.3.
The old `../Raindetector/` project is the earlier Stall.biz adapter prototype.

## Interface

| Head contact | Function | Controller contact, nominal assembly |
|---|---|---|
| J1.1 | HEATER+ | J1.1 |
| J1.4 | GND / electrode 2 | J1.4 |
| J2.1 | SENSE / electrode 1 | J2.1 |
| J2.4 | HEATER- | J2.4 |
| J1/J2 pins 2 and 3 | Unconnected, mechanical support | Unconnected |

Both boards face B.Cu toward each other. The SMD header contact axes, not
its alternating solder-pad centers, determine the mating positions.
The current connectors are 2x2 SMD headers. The table lists electrical
assignments from the current PCB, not a mechanical mating qualification.
Verify contact alignment and orientation with the selected sockets before assembly.
Confirm the actual header/socket mating height from the selected parts.

## Sensor and fabrication

C1 represents manufactured copper, not a component to purchase or solder.
The project-local footprint table resolves the sensor footprint from
`../../Libraries/EnvNode-Footprints.pretty`.
The custom design rule permits 0.10 mm clearance only between objects of C1;
other copper keeps its normal clearance requirements.

The sensor pads have no F.Mask or F.Paste openings. The current two vias
are front-plugged and front-tented (Type IV-a intent), NOT filled and capped:
`capping` and `filling` are disabled. Confirm the plugging process and
water exclusion with the fabricator; mask tenting alone is not a seal guarantee.
Any change to Type VII needs explicit fabrication settings and ordering notes.
The nominal 37.25 mm sensor height excludes the connection lobes; including
those, the copper height is about 40.27 mm.

Four 3.2 mm non-plated mounting holes are provided. Confirm screw/washer
clearance, mounting insulation and assembled spacing before manufacture.

## Validation

See `../RainDetectorController/README.md` for the shared validation commands.
ERC/DRC are design checks, not hardware or environmental qualification.
The assembled coated head has not yet been manufactured or tested.

Documentation correction, 2026-10-05: J2.1 is SENSE and J2.4 is HEATER- in the current PCB; the previous table described the earlier connector arrangement. The current outline is 62.12 x 44.12 mm. Historical 2026-09-14 checks predate the connector/outline changes committed on 2026-09-15.

## Assembly guide — 2026-10-06

`Documentation/RainDetectorHead_Bestueckungs_und_Bringup_Rev0.1.pdf` documents the current 62.12 x 44.12 mm board, 2x2 SMD headers, heater assembly, controller contact mapping, fabrication requirements, and separate heater/sensor checks. It includes current source hashes and PCB views using the common ORing camera angles.

The exported schematic netlist and PCB pad nets match. The heater was verified as five parallel strings of four 15-ohm resistors (R1-R4, R5-R8, R9-R12, R13-R16, R17-R20). No new full ERC/DRC or physical testing was performed for this documentation update.

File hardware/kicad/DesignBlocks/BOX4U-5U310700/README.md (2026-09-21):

# BOX4U 5U310700 PCB template

KiCad board template for mounting a PCB in the base of the BOX4U 5U310700 enclosure.

The design block contains both the schematic representation and the PCB geometry. `H1` through `H4` are non-electrical mounting-hole symbols, excluded from BOM and position files, and linked to the matching project footprint.

## Geometry

- Board outline: 113 mm x 93 mm, corner radius 3 mm
- Mounting-hole pattern: 98 mm x 83.4 mm, centered on the board
- Mounting holes: four NPTH holes, diameter 4.5 mm
- Intended fastener: self-tapping screw into the enclosure's plastic bosses, not a metric through-bolt
- Keepout/courtyard: diameter 9 mm around every mounting hole
- Origin/reference center: board center at X=100 mm, Y=100 mm

The solid `Edge.Cuts` geometry defines the PCB. Dashed `Dwgs.User` geometry documents the enclosure reference outline and lid screw bosses from the manufacturer drawing; it is not part of the routed PCB outline.

Source drawing: `hardware/housings/5U310700.pdf` (BOX4U drawing 5U310700, ABS 310700 5U enclosure).

The 113 mm x 93 mm outline and the 98 mm x 83.4 mm mounting pattern agree with the initial EnvNode Weatherstation Rev. 0.1 layout. Before ordering PCBs, verify the outline, hole pattern, screw-head clearance, connector access, and assembly fit against a physical enclosure.

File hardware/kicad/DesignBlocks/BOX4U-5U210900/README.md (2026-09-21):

# BOX4U 5U210900 PCB template

KiCad board template for mounting a PCB in the base of the BOX4U 5U210900 enclosure.

The design block contains both the schematic representation and the PCB geometry. `H1` through `H4` are non-electrical mounting-hole symbols, excluded from BOM and position files, and linked to the matching project footprint.

## Geometry

- Board outline: 130 mm x 68 mm, corner radius 3 mm
- Mounting-hole pattern: 121.5 mm x 58 mm, centered on the board
- Mounting holes: four NPTH holes, diameter 4.5 mm
- Intended fastener: 4 mm self-tapping screw into the plastic bosses (not M4)
- Keepout/courtyard: diameter 9 mm around every mounting hole
- Origin/reference center: board center at X=100 mm, Y=100 mm

The solid `Edge.Cuts` geometry defines the PCB. Dashed `Dwgs.User` geometry documents the enclosure's inner wall and unused outer screw bosses from the manufacturer drawing; it is not part of the routed PCB outline.

Source drawing: `hardware/housings/5U210900.pdf` (BOX4U drawing 5U210900, PC 210900 5U enclosure).

Before ordering PCBs, verify the outline, hole pattern, screw-head clearance, and assembly fit against a physical enclosure.

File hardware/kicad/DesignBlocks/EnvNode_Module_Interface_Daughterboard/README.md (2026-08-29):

# Legacy EnvNode Daughterboard Module Interface Design Block

> **Obsolete Revision 0.1 reference:** This directory describes the former two-connector 2 x 4 interface, including a 24 V rail. It must not be used for new Revision 0.2 modules.
>
> Current module projects must use `EnvNode_Module_Connector_Daughterboard_SMD` or `EnvNode_Module_Connector_Daughterboard_THT` and the 2 x 7 pin assignment in `docs/EnvNode_Module_Interface_Hardware_Specification.md`.

## Purpose

`EnvNode_Module_Interface_Daughterboard` is the reference KiCad design block for the module side of the EnvNode expansion interface. It provides two electrically parallel 2 x 4 connectors for daughterboards that plug onto an EnvNode mainboard.

The design block defines the electrical pin assignment, connector geometry, bottom-mounted connector footprints, and the routed interconnect between both connectors. Module-specific circuitry is added outside this block.

## Source and Published Library Block

- Editable source project: `hardware/kicad/DesignBlocks/EnvNode_Module_Interface_Daughterboard/`
- Published design block: `hardware/kicad/Libraries/EnvNodeDesignBlocks.kicad_blocks/EnvNode_Module_Interface_Daughterboard.kicad_block/`
- Library identifier: `EnvNodeDesignBlocks:EnvNode_Module_Interface_Daughterboard`

The schematic and PCB portions are updated separately in KiCad. Changes to the source schematic must be saved to the linked design block from the Schematic Editor. Layout changes must be saved separately from the PCB Editor.

## Connector Assignment

J1 and J2 use the same pin assignment and are connected in parallel:

| Pin | Net | Function |
| ---: | --- | --- |
| 1 | `GND` | Common ground reference |
| 2 | `24V` | 24 V power rail |
| 3 | `3V3` | 3.3 V power rail |
| 4 | `5V` | 5 V power rail |
| 5 | `SDA` | System I2C data |
| 6 | `SCL` | System I2C clock |
| 7 | `GPIO1` | General-purpose signal |
| 8 | `GPIO2` | General-purpose signal |

Unused pins may remain unconnected in module-specific circuitry, but their assigned function must not be changed.

## Mechanical Definition

Both connectors use the custom footprint:

`EnvNode-Footprints:PinSocket_2x04_P2.54mm_Vertical_Bottom`

This footprint is intended for receptacles mounted on the bottom side of the daughterboard and preserves the standardized pin numbering in the assembled stack.

The connector reference positions in the published block are:

| Connector | X | Y | Rotation |
| --- | ---: | ---: | ---: |
| J1 | 150.57 mm | 62.17 mm | 180 degrees |
| J2 | 125.17 mm | 62.17 mm | 180 degrees |

The absolute coordinates are an implementation detail. The normative relationship is:

- horizontal spacing: 25.40 mm;
- vertical offset: 0.00 mm; and
- identical orientation.

Moving or rotating the complete design block is permitted. Changing the relative connector geometry is not.

## Routing Baseline

The published PCB block uses the following track widths:

| Nets | Track width |
| --- | ---: |
| `24V`, `5V`, `3V3` | 0.40 mm |
| `SDA`, `SCL`, `GPIO1`, `GPIO2` | 0.20 mm |

`GND` is intended to be connected by a copper zone on the completed module PCB. The track widths describe the reusable connector interconnect and are not a declaration of the permitted interface current. Current limits remain dependent on connector ratings, copper thickness, thermal conditions, and the completed module design.

## Use in a Module

1. Place the schematic portion of the design block in the module schematic.
2. Update the PCB from the schematic with symbol grouping enabled where appropriate.
3. Apply or place the linked PCB layout once.
4. Add the module outline, GND zone, mounting features, and module-specific circuitry.
5. Do not place a second overlapping copy of the PCB block. Exact same-net overlaps may not be reported by DRC.
6. Run ERC and DRC on the completed module project.

## Validated Library State

The published library block was checked on 2026-08-26 with KiCad 10:

- both schematic symbols use the Bottom footprint assignment;
- J1 and J2 have identical pin-to-net mappings;
- connector spacing is 25.40 mm with no vertical offset;
- all 30 routed segments are unique;
- power and signal routing uses the widths listed above; and
- schematic ERC reports no errors or warnings.

Validation of a complete module remains mandatory because the library PCB fragment does not include the module outline, module-specific circuitry, or the final copper zones.

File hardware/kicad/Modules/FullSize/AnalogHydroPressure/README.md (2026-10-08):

# EnvNode AnalogHydroPressure

`AnalogHydroPressure` is a FullSize daughterboard for a two-wire 4–20 mA hydrostatic pressure probe. The current hardware is Revision 0.5, succeeding the legacy `AnalogInput` module.

## Project Files

- `AnalogHydroPressure.kicad_pro`
- `AnalogHydroPressure.kicad_sch`
- `AnalogHydroPressure.kicad_pcb`
- `Analog.kicad_sch` — analog input and ADS1115
- `24VBoost.kicad_sch` — local probe-supply generation
- `Documentation/AnalogHydroPressure_Bestueckungs_und_Bringup_Rev0.5.pdf` — assembly, configuration, and bring-up guide

## Functional Structure

The module has two hierarchical circuit sections:

- The analog section converts the probe loop current across a 150 ohm, 0.1% burden resistor, filters and clamps the signal, and digitizes it with an `ADS1115IDGS` on the I2C bus selected by JP5 (SDA) and JP6 (SCL).
- The boost section uses an `LT8330S6` to generate the local 24 V probe rail from the module interface's `+5V` supply.

The ADS1115 address is selected with one of four solder jumpers for addresses `0x48` through `0x4B`. Exactly one address jumper must be closed before operation.

JP5 (SDA) and JP6 (SCL) select the ADS1115 bus. Bridge pins 1-2 on both for I2C0, or pins 2-3 on both for I2C1. Both jumpers must select the same bus. Without both bridges the ADS1115 is disconnected from the bus. Never bridge all three pins or mix the bus selections. These jumpers do not select the 5 V supply. The optional identity EEPROM remains on I2C0.

## Local Libraries

The LT8330 symbol is stored in:

`hardware/kicad/Libraries/EnvNode-Symbols.kicad_sym`

The C&K switch footprint is stored in:

`hardware/kicad/Libraries/EnvNode-Footprints.pretty/SW_Slide_CK_OS202011MS2QS1.kicad_mod`

The project-level `sym-lib-table` maps the symbol library. The footprint library name must resolve as `EnvNode-Footprints` in KiCad.

## Bring-up Priorities

1. Populate and inspect the 5 V input and LT8330 boost section.
2. Power it from a current-limited 5 V supply before connecting a probe.
3. Verify startup, switching waveform, output voltage, ripple, and component temperature under the intended load.
4. Verify that exactly one ADS1115 address jumper is closed and that the ADC is detected on the I2C bus selected by JP5 (SDA) and JP6 (SCL).
5. Apply known loop currents and verify approximately 0.6 V at 4 mA and 3.0 V at 20 mA across the nominal 150 ohm burden.
6. Calibrate the complete measurement path with the intended pressure probe.

## Validation and Release Status

Revision 0.4 uses the B260S1F-7 boost diode, selectable ADS1115 address jumpers, and an optional DNP measurement header for GND, `+24V`, `LOOP_RETURN`, and `AIN0`. The bottom-side identification EEPROM and its decoupling capacitor remain DNP in the current kit.

At the historical design checkpoint on 2026-09-28, schematic ERC and PCB DRC completed without errors or violations, schematic/PCB parity was clean, and the layout received a visual plausibility review. These checks do not replace physical power-supply bring-up, thermal and EMC verification, probe calibration, or production testing.

The Revision 0.5 assembly/bring-up guide documents AUX_GPIO2 / connector pin 10 for boost enable, including continuity checks, startup sequencing, updated PCB views, and source hashes. Revision 0.4 remains available as a historical guide; its article list predates the enable reassignment. Physical boost-converter validation, thermal and EMC verification, probe calibration, and production testing remain required before production release.

## Connector review — 2026-09-28

The module uses J1 pin 5 for I2C0 SDA and pin 6 for I2C0 SCL. Mini Revision 0.7 and WeatherStation Revision 0.2 both match this assignment in schematic and PCB; the earlier mainboard I2C0 mismatch is resolved for these revisions. I2C1 uses pin 7 SDA and pin 8 SCL and can be selected for the ADS1115 through JP5/JP6.

Revision 0.5 moves LT8330 EN/UVLO and its R7 pull-down to J1 pin 10 / AUX_GPIO2 in both schematic and PCB. J1 pin 9 / AUX_GPIO1 is now unused and available for a future conditioned SCT013 analog signal; no SCT013 circuit is implemented yet. Firmware must use AUX_GPIO2 for boost enable: GPIO13 on Mini Slot A and WeatherStation Slot A, GPIO14 on Mini Slot B. Firmware was not modified as part of this hardware revision.

The Revision 0.5 review on 2026-09-28, with zone refill, found no PCB DRC violations, unconnected pads, or schematic/PCB parity issues. Schematic ERC reports zero errors and ten warnings (unused labelled signals and duplicate local/global label names). The separate connector comparison confirms the corrected I2C0 assignment on Mini Revision 0.7 and WeatherStation Revision 0.2.

## Documentation verification — 2026-10-05

The Revision 0.5 guide was checked against an exported schematic netlist and PCB pad nets. J1.10, U4.4 (EN/UVLO), and R7.1 share AUX_GPIO2; J1.9 remains separate. The PCB views use the common ORing camera angles with preserved proportions. No new full ERC/DRC run or physical validation was performed during this documentation update.

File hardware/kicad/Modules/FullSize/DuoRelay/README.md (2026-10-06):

# EnvNode DuoRelay

`DuoRelay` is a FullSize THT daughterboard for the EnvNode Revision 0.3 module interface. It provides two independently controlled 5 V electromechanical changeover relays.

## Project Files

- `DuoRelay.kicad_pro`
- `DuoRelay.kicad_sch`
- `DuoRelay.kicad_pcb`
- `Documentation/DuoRelay_Bestueckungs_und_Bringup_Rev0.3.pdf` — current assembly and bring-up guide; Revision 0.2 remains historical.

## Interface Use

| Connector pin | Net | DuoRelay use |
| ---: | --- | --- |
| 1 | `GND` | Control-side ground |
| 2 | `+3V3_SYS` | Identification EEPROM supply and fixed `A1` level |
| 3 | `EEPROM_A0` | Slot-defined identification EEPROM address bit |
| 4 | `+5V` | Relay-coil supply |
| 5–6 | `I2C0` | Optional identification EEPROM |
| 7–8 | `I2C1` | Not used |
| 9 | `AUX_GPIO1` | Relay channel 1 control |
| 10 | `AUX_GPIO2` | Relay channel 2 control |
| 11–14 | SPI | Not used |

Each channel uses a BC817 low-side driver with a 1 kΩ base resistor, a 100 kΩ pull-down for a defined off state, and a 1N4148W flyback diode. An LED with a 1.5 kΩ series resistor is connected from `+5V` to each transistor collector and lights while the corresponding relay is driven. The indication confirms the electrical drive state, not the mechanical position of the relay contacts. The relays are Finder `34.51.7.005.0010` parts with 5 V coils.

## Module Identification

The board provides an optional `24LC32` (U2, SOIC-8; kit part ENP-00102 / `24LC32A-I/SN`) module-identification EEPROM and a local 100 nF decoupling capacitor on the bottom side. The EEPROM follows the EnvNode discovery convention:

- SDA and SCL use `I2C0`;
- `A1` is tied to `+3V3_SYS`;
- `A0` uses connector pin 3 / `EEPROM_A0`;
- Slot A therefore selects `0x52`; and
- Slot B selects `0x53`.

The EEPROM is not required for the relay hardware to operate, but fitting and provisioning it is good practice. Firmware discovers the reserved module EEPROM addresses independently for both slots, resolves supported records through the module-profile registry, and reports board/slot compatibility diagnostically. Discovery does not yet create a DuoRelay-specific driver or UI controls automatically. Without a valid identity, firmware treats the relay GPIOs as ordinary configurable `AUX_GPIO` ports and must not automatically start a DuoRelay-specific driver.

## Mechanical Geometry

- PCB: 38.00 mm × 64.00 mm
- Connector: bottom-mounted 2 × 7 THT header
- Connector axis: centered across the board and 6.35 mm from the top edge
- Support holes: 2.7 mm for M2.5 hardware, on the centerline at 27.00 mm and 59.00 mm from the top edge

## Relay Contact Region

The relay-contact nets are routed on F.Cu with 1.0 mm tracks. The design keeps at least 8 mm between the 250 VAC contact region and all SELV copper on both layers, including GND zones, vias, pads, and traces.

The spacing and relay ratings do not by themselves certify the finished product for mains use. Terminal ratings, enclosure, touch protection, fusing, load type, pollution degree, material group, overvoltage category, manufacturing tolerances, and the applicable product standard must be assessed for the final application.

## Validation

Revision 0.3 aligns the bottom-side identification EEPROM, its decoupling capacitor, vias, and connector routing with the FullSize THT module template.

At the time of the Revision 0.2 port:

- schematic ERC reports no errors; its nine warnings comprise six intentionally unused connector nets and three same-name local/global label warnings for `+3V3_SYS`, `I2C0_SDA`, and `I2C0_SCL`;
- PCB DRC reports no violations, unconnected pads, or footprint errors; and
- connector placement, board outline, support-hole positions, power routing, relay drivers, status LEDs, and contact separation were checked against the source design.

ERC and DRC must be repeated after every schematic, footprint, routing, zone, or rule change.

## Documentation verification — 2026-10-05

The Revision 0.3 guide updates the former U1 / SOT-23-6 EEPROM to U2 / SOIC-8 and retains the schematic DNP status for U2 and C1. All common component-pin nets in the exported schematic netlist and PCB were compared and matched, including relay contacts and EEPROM address wiring. Current PCB renders use the common ORing viewing angles. No new full ERC/DRC run or physical validation was performed; the historical Revision 0.2 validation above is not a release check for Revision 0.3.

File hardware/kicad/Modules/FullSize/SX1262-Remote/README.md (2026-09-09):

# EnvNode FullSize SX1262 Remote Radio Module

This KiCad 10 project implements a Revision 0.3 EnvNode FullSize radio daughterboard using the complete EBYTE E22-900M22S module. The E22 contains a Semtech SX1262 transceiver and supports the 868 MHz and 915 MHz ISM bands. The regional frequency and radio parameters are selected in firmware.

The board uses the 38 mm × 64 mm FullSize outline, bottom-mounted 2 × 7 THT module connector, two M2.5 support holes and the standard module-identification EEPROM circuit.

## Host interface

The E22 is connected to the EnvNode host as follows:

| E22 signal | EnvNode signal | Function |
| --- | --- | --- |
| MOSI | SPI_MOSI | SPI data from host |
| MISO | SPI_MISO | SPI data to host |
| SCK | SPI_SCK | SPI clock |
| NSS | SPI_CS | Active-low SPI chip select |
| DIO1 | AUX_GPIO1 | Configurable radio interrupt |
| BUSY | AUX_GPIO2 | Radio busy indication |
| NRST | PCA9536 IO0 | Active-low hardware reset |

The PCA9536 GPIO expander is connected to I2C0. I2C1 remains unused by the radio circuitry. NRST and SPI_CS each have an external 10 kΩ pull-up to +3V3_SYS.

## RF-switch control

E22 DIO2 is connected directly to TXEN and must be enabled as the SX1262 RF-switch control output in firmware (`SetDIO2AsRfSwitchCtrl`). A BC847 NPN inverter generates the complementary RXEN signal:

- DIO2/TXEN high: TXEN high, RXEN low, transmit path enabled.
- DIO2/TXEN low: TXEN low, RXEN high, receive path enabled.

The inverter uses a 1 kΩ base resistor and a 10 kΩ RXEN pull-up. This hardware interlock avoids timing-dependent RF-switch control through an I2C GPIO expander.

## Power supply

The E22 and PCA9536 operate from +3V3_SYS. Place the 100 nF ceramic bypass capacitors close to their supply pins. The E22 additionally uses a local 22 µF ceramic bulk capacitor to support its approximately 120–140 mA transmit-current peaks.

## Antenna options

Use exactly one antenna connection:

1. Connect a suitable 868/915 MHz antenna or coaxial pigtail to the IPEX/U.FL-compatible socket on the E22. In this configuration E22 pin 21 (ANT) remains deliberately unconnected.
2. Connect a quarter-wave wire monopole to E22 pin 21. For 868 MHz, start with approximately 86 mm of straight insulated wire measured from the feed point. The carrier ground plane acts as the counterpoise. Keep the wire away from the PCB, batteries, cables and metal parts, and do not use the E22 IPEX socket simultaneously.

A wire antenna is installation-dependent and should be verified in the final enclosure. For production hardware, RF impedance and radiated performance should be measured and the antenna length or matching adjusted as required.

## Design notes

- Supply and logic levels are 3.3 V; do not apply 5 V to the E22.
- Connect every E22 GND pad to a low-impedance ground plane.
- Keep the radio and antenna away from switching regulators, fast clocks and high-current traces.
- Keep SPI traces short and route any connection from ANT pin 21 as a controlled 50 Ω RF path.
- Run KiCad ERC after schematic changes and DRC after PCB changes.

See the [module-interface hardware specification](../../../../../docs/EnvNode_Module_Interface_Hardware_Specification.md) for the authoritative EnvNode connector and mechanical requirements.

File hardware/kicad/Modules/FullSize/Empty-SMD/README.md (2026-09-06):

# EnvNode FullSize SMD Module Template

This KiCad project is the 38 mm × 64 mm starting point for a Revision 0.3 FullSize daughterboard with a bottom-mounted SMD module connector.

Copy the complete directory when starting a module. Do not add application circuitry to the template itself. Preserve the 2 × 7 connector mapping, connector axis 6.35 mm from the top edge, 2.7 mm M2.5 support holes at 27 mm and 59 mm, and the reference module-identification EEPROM circuit.

See the [module-interface hardware specification](../../../../../docs/EnvNode_Module_Interface_Hardware_Specification.md) and rerun ERC and DRC on every derived board.

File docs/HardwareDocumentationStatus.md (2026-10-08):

# Hardware documentation status

Audit completed 6 October 2026. This inventory covers assembly, bring-up and
jumper PDFs for implemented boards. Library copies, connector/design blocks,
mechanical templates and Empty module templates are not separate missing
assembly manuals. Archived Revision-0.1 boards remain historical designs.

## Current guides

| Board | Current PCB revision | PDF status |
| --- | --- | --- |
| EnvNode Mini | 0.8 | Rev. 0.8 available; palette and PCB views checked |
| Weatherstation | 0.2 | New Rev. 0.2 guide; connector mappings and C1 supply corrected |
| AnalogHydroPressure | 0.5 | New Rev. 0.5 guide; AUX_GPIO2 boost enable and startup checks |
| DuoRelay | 0.3 | New Rev. 0.3 guide; U2 / SOIC-8 EEPROM and assembly details |
| ORing Power | No formal PCB title-block revision | Existing Rev. 0.1 documentation refreshed; current source hashes and corrected D1/D2 assignment |
| I2C Carrier HalfSize | 0.1 | Rev. 0.1 jumper guide available; palette and PCB view checked; no source hash in guide |
| RainDetectorController | 0.3 | New Rev. 0.3 guide; current 2x2 sockets, dimensions, interfaces and bring-up |
| RainDetectorHead | 0.1 | New Rev. 0.1 guide; heater network, 2x2 headers, fabrication and test requirements |
| Legacy Raindetector | 0.2 | Matching Rev. 0.2 guide available; separate from the Controller/Head projects |

New guides are in each board's `Documentation/` directory. Older PDFs remain
historical and retain their own source revisions. The new guides contain source
hashes; ORing retains its reference rendering because the source differences do
not change geometry or circuitry. See [visual style](HardwareDocumentationStyle.md)
for the palette and camera settings.

## Missing guides

| Board | PCB title-block revision | Remaining work before/documented in a new PDF |
| --- | --- | --- |
| SCT013Head | 0.1 | Create guide from current sources; reconcile R1 BOM mismatch and ADC/ADC1 reference findings in REVIEW.md |
| SX1262-Remote | 0.1 | Create guide; clarify whether README's Revision 0.3 names the interface or board revision |
| SolarRadiation | 0.1 | Create guide from an agreed hardware snapshot; local PCB/project edits are outside this documentation commit |
| RemoteNode | Not specified | Establish revision and documented scope, then create guide |

No PDF is generated for these boards without selecting it with the user.

## Verification limits and outstanding hardware work

- PDF pages were rendered and visually inspected. Recent guides were checked
  against exported schematic netlists and PCB pad nets; that is not a full
  schematic/PCB parity or design-rule check.
- No new complete ERC/DRC or physical hardware testing was performed for this
  documentation work. Historical check dates are labeled as such.
- RainDetector's 14 September ERC/DRC results predate the 15 September connector
  and outline changes. Revalidate both projects before manufacture.
- RainDetector connector mating height, real heater behavior, coating and via
  water exclusion still need qualification. The Controller CSV was regenerated
  because it still listed the previous 1x4 sockets.
- On both EnvNode Mini and Weatherstation, C1 (100 nF) decouples +5V to GND.
  The identity EEPROM is supplied from +3V3_SYS without a separate local
  decoupling capacitor. This is the same arrangement on both mainboards.
- SCT013Head REVIEW.md lists an R1 article-list mismatch and reference/DRC
  findings; inspect the current sources before carrying any historical finding
  into a new guide.
- Assembly-guide availability does not imply production approval.

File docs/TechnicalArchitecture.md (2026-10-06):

# Technical Architecture

## Purpose

This document defines the technical architecture of EnvNode.

It describes how the EnvNode domain model is realized on the embedded platform and how the different technical layers interact.

The domain model itself is defined separately in `DomainModel.md`.

This document intentionally focuses on technical responsibilities such as:

- runtime
- hardware abstraction
- connectivity
- communication
- persistence
- time synchronization
- configuration
- web access
- firmware updates
- diagnostics

The goal is to keep the technical architecture modular, maintainable and largely independent from individual sensor implementations.

Hardware may evolve over time without requiring architectural changes to higher software layers.

The EnvNode firmware intentionally limits itself to acquiring and publishing measurements.

Interpretation of weather data belongs to external systems such as Home Assistant or other automation platforms.

Examples include:

- daily rainfall
- sunshine duration
- evapotranspiration
- historical statistics
- weather interpretation

The fundamental architectural principle therefore remains:

> Measure, don't interpret.

---

# Architectural Layers

EnvNode is divided into four technical layers:

1. Application Layer
2. Communication Layer
3. Connectivity and Infrastructure Layer
4. Hardware Layer

Conceptually:

    +--------------------------------------------------+
    |                Application Layer                 |
    |--------------------------------------------------|
    | Device orchestration                             |
    | Sensor coordination                              |
    | Measurement coordination                         |
    | Configuration usage                              |
    | Diagnostics                                      |
    | Local hardware control                           |
    +-------------------------+------------------------+
                              |
                              v
    +--------------------------------------------------+
    |              Communication Layer                 |
    |--------------------------------------------------|
    | MQTT                                             |
    | HTTP / Web Interface                             |
    | OTA                                              |
    +-------------------------+------------------------+
                              |
                              v
    +--------------------------------------------------+
    |       Connectivity and Infrastructure Layer      |
    |--------------------------------------------------|
    | Configuration                                    |
    | WiFi                                             |
    | Time / NTP                                       |
    | Logging                                          |
    | Persistent Storage                               |
    +-------------------------+------------------------+
                              |
                              v
    +--------------------------------------------------+
    |                  Hardware Layer                  |
    |--------------------------------------------------|
    | GPIO                                             |
    | I2C                                              |
    | ADC                                              |
    | OneWire                                          |
    | PWM                                              |
    | ESP32 hardware                                   |
    +--------------------------------------------------+

Dependencies always point downward.

Higher layers may depend on lower layers.

Lower layers must never depend on application-specific logic.

Each layer owns one clearly defined technical responsibility.

Communication protocols use infrastructure.

Application logic uses services.

Services use hardware abstractions.

Hardware remains unaware of application behaviour.

---

# Application Layer

The Application Layer coordinates the EnvNode as a whole.

It connects the domain model to the technical infrastructure services.

Typical responsibilities include:

- initializing the device
- loading configuration
- initializing infrastructure services
- coordinating sensors
- coordinating actuators
- coordinating Measurements
- exposing diagnostics
- coordinating communication services
- managing lifecycle state

The Application Layer intentionally contains very little implementation logic.

Its primary responsibility is orchestration.

Concrete implementations remain inside dedicated services.

Examples include:

- ConfigurationService
- WiFiService
- TimeService
- MqttService
- WebService

Future examples include:

- SensorManager
- MeasurementPublisher

Compiled Sensor capabilities are described by `SensorImplementationRegistry`. Persistent
`SensorSlotConfiguration` objects define the desired runtime composition, including stable
Slot identity, enablement, name, implementation, schedule and typed hardware assignment.
`ConfigurationService` owns their defaults, validation and NVS persistence.

At boot, `SensorFactory` constructs enabled, non-None runtime Sensors from the validated
Slot configuration using statically bounded placement storage. Disabled and None Slots
remain configurable but create no runtime Sensor. `BoardCapabilities` validates approved
GPIO resources, and enabled physical GPIO Slots may not share one exclusive GPIO.

The active typed `BoardProfile` is the single immutable description of physical board
resources. `BoardCapabilities` derives its lookup and compatibility validation from that
profile; it does not own a second pin map. The profile is selected once during boot by the
`BoardIdentityResolver` and remains frozen for that boot. A valid, supported EEPROM identity
selects the matching profile. If the identity record is absent, unreadable, blank, malformed,
or fails its integrity check, an explicitly configured build-time development fallback may
be used. A valid but unsupported identity does not fall back and prevents normal runtime
operation. Firmware Build Identity and physical Board Identity remain separate models.

The current `EnvNode Mainboard` profile is hardware revision 0.3. It exposes I2C0 on
SDA GPIO21 / SCL GPIO22 and I2C1 on SDA GPIO25 / SCL GPIO26. Generic digital resources are
GPIO4, GPIO13, GPIO14, GPIO15, GPIO16, GPIO17, GPIO18, GPIO19, GPIO23, GPIO32 and GPIO33.
GPIO32 and GPIO33 additionally support analog input; GPIO34, GPIO35, GPIO36 and GPIO39 are
analog-input-only EnvNode resources. I²C pins are described only by the bus definitions and
are therefore never offered as generic GPIO resources.

Future EnvNode 868 and EnvNode Nano builds can provide different immutable profiles without
changing hardware consumers, regardless of whether a profile originates from EEPROM identity
or the explicit development fallback. Module identification scans the two reserved `I2C0`
addresses independently. A registry resolves valid identity records to declarative module
profiles, and compatibility validation compares their connector-resource requirements with
the selected board profile's slot mapping. This stage is diagnostic only: driver creation,
live profile replacement, and SPI module definitions remain outside the current architecture.

`I2CBusManager` owns initialization and access to the physical `TwoWire` instances described
by the active profile. Its diagnostic scan probes only normal usable 7-bit addresses
for acknowledgement on already-initialized buses. Startup scans all board buses once after
bus initialization and module discovery, before sensor runtime starts. Scan failures are
reported without stopping startup. The manager caches the latest result per bus in RAM.
The Web Diagnostics page displays these results and SDA/SCL metadata from `BoardProfile`;
opening or reloading the page does not initiate another scan. A manual scan refreshes all
board buses. Known EEPROM addresses are annotated using the resolved board identity and
module discovery results. The cache is non-persistent and scanning does not rebuild or
pause Sensor runtime composition. Sensor servicing and
Web request handling are serialized by the cooperative application loop, so their I²C
transactions cannot overlap in the current execution model.

Sensor administration is available through the Web Sensors page. A successful edit stores
the desired Slot configuration and requests `RestartSensorManager`; it does not activate the
change automatically. The explicit **Apply Sensor Changes** action asks RuntimeManager to
rebuild the complete composition while WiFi, MQTT, time and Web services remain active.

SensorRuntime stages the desired composition in a second statically bounded SensorFactory.
After successful construction it clears SensorManager, registers and begins the new Sensors,
then destroys the previous instances. If registration fails, the still-alive previous
composition is restored. RuntimeManager clears `RestartSensorManager` only after a successful
rebuild and never downgrades a stronger pending action. The Device is not rebooted.

The Application Layer must not contain:

- hardware driver logic
- MQTT protocol implementation
- HTTP implementation
- NTP implementation
- persistent storage implementation
- ESP32-specific API calls

Application logic therefore remains largely independent from hardware details and communication protocols.

This separation keeps the firmware modular while allowing infrastructure components to evolve independently.

## Domain runtime compositions

EnvNode deliberately has three separate runtime models. They share slot, registry, factory and lifecycle patterns, but not domain behavior.

```mermaid
flowchart LR
    SC[SensorSlotConfiguration] --> SR[SensorRuntime]
    SR --> SM[SensorManager]
    SM --> IS[ISensor]
    IS --> M[Measurement]
    M --> MP[MeasurementPublisher]

    AC[ActuatorSlotConfiguration] --> AR[ActuatorRuntime]
    AR --> IO[IOnOffActuator]
    IO --> GA[GpioOnOffActuator]
    GA --> GPIO[GPIO]

    CC[ControllerSlotConfiguration] --> CR[ControllerRuntime]
    CR --> BC[BlinkController]
    CR --> TC[ThresholdController]
    SM --> MSC[MeasurementSnapshotCache]
    MSC --> MR[IMeasurementResolver]
    MR --> TC
    BC --> RES[IOnOffActuatorResolver]
    TC --> RES
    RES --> AR
```

### Sensor runtime

`SensorImplementationRegistry` describes compiled Sensor implementations, supported Measurements, scheduling defaults and hardware requirements. Persistent fixed `SensorSlotConfiguration`s select reusable implementations, names, schedules and hardware assignments.

`SensorFactory` constructs enabled instances. `SensorRuntime` manages composition replacement, while `SensorManager` owns acquisition scheduling, Measurement acceptance and delivery to `MeasurementSnapshotCache` and `MeasurementPublisher`. Sensor configuration can be applied through the implemented Sensor rebuild path without restarting the ESP32.

### Actuator runtime

`ActuatorImplementationRegistry` describes reusable implementations, capabilities and required hardware capabilities. Persistent fixed `ActuatorSlotConfiguration`s provide stable `ActuatorId`, enablement, name, implementation and the sole hardware assignment.

`ActuatorFactory` constructs deterministic in-place instances. `ActuatorRuntime` owns their
lifecycle and exposes capability lookup by `ActuatorId`. `gpio_on_off` exposes
`IOnOffActuator`; `gpio_pwm` exposes `ILevelActuator` and implements normalized 0–100 Level
using ESP32 LEDC. Level centrally satisfies OnOff with Off=0 and On=100. Callers never
manipulate GPIO, LEDC channels or PWM duty directly.

Live rebuild stages a new composition, safely shuts down the previous outputs Off where possible, and replaces the active instances without a Device restart.

### Controller runtime

`ControllerImplementationRegistry` describes reusable Controller implementations and required Actuator capabilities. Fixed `ControllerSlotConfiguration`s provide stable `ControllerId`, enablement, name, implementation and typed implementation configuration.

`ControllerFactory` constructs `IController` instances. `ControllerRuntime` owns composition, cooperative servicing, diagnostics and transient Start/Stop operations. Enabled Controllers start automatically when a composition is initialized or rebuilt; manually stopped state is not persisted across rebuild.

Blink uses `ActuatorId` and `IOnOffActuatorResolver` to obtain the current capability from `ActuatorRuntime`. It never retains a concrete Actuator pointer across an Actuator rebuild. It uses monotonic, non-blocking timing and has no Web, MQTT, GPIO, wall-clock or NTP dependency.

Threshold identifies exactly one input stream with `MeasurementSourceReference` (`SensorId + MeasurementType`). It obtains copied `MeasurementSnapshot`s from `IMeasurementResolver` and retains no Sensor or cache pointer. Its compatible inputs are metadata-classified `FloatingPoint` + `State` Measurements. `acceptedMonotonicMs` supplies freshness and `revision` supplies accepted-change identity; wall-clock Measurement timestamp remains diagnostic/external time.

Threshold begins with decision `Unknown`. Values at or above `onThreshold` decide On, values at or below `offThreshold` decide Off, and in-band values retain the previous decision. First input in-band remains Unknown. Missing, invalid or stale input makes no new decision and does not force Off. Good, Estimated and Degraded quality labels do not independently reject otherwise usable input.

Controller validation checks configured references, enablement and advertised types/capabilities. An enabled Threshold source Sensor must advertise the selected compatible Measurement; Blink and Threshold targets must advertise `OnOff`. Reverse validation prevents referenced Sensors or Actuators becoming incompatible. One configured enabled Controller may claim each target across all implementations. Runtime STOP does not release this configured ownership. Runtime availability remains separate and may temporarily fail despite valid configuration.

### Hardware occupancy

Sensors and Actuators share one authoritative hardware occupancy validation pass across enabled slots. Board capability validation remains a separate concern.

- exclusive GPIO collisions are rejected across Sensor/Sensor, Sensor/Actuator and Actuator/Actuator assignments
- identical I2C bus/address claims conflict where applicable
- different addresses may share an I2C bus
- disabled slots do not claim hardware
- Controllers own no `HardwareResourceAssignment`

Web option filtering assists the user but does not replace ConfigurationService validation.

### Runtime apply effects

Configuration changes request the narrowest implemented lifecycle action:

```text
Sensor change     -> RestartSensorManager     -> Sensor runtime rebuild
Actuator change   -> RestartActuatorRuntime   -> ActuatorRuntime rebuild
Controller change -> RestartControllerRuntime -> ControllerRuntime rebuild
```

These apply paths keep WiFi, MQTT, Web and unrelated domain runtimes operating. They do not promise a generic hot-swap mechanism for arbitrary subsystems.

---

# Communication Layer

The Communication Layer exposes EnvNode functionality to external systems.

Communication protocols remain independent from the transport mechanisms underneath them.

The initial communication mechanisms are:

- MQTT
- HTTP
- OTA

Communication components never own configuration or measurements.

Instead, they consume domain objects and infrastructure services.

The Communication Layer therefore remains responsible for representation and transport rather than business logic.

---

## MQTT

MQTT is the primary integration protocol.

MQTT operates on top of network connectivity provided by the Connectivity Layer.

Conceptually:

    Canonical Measurement
        |
        v
    MeasurementPublisher
        |
        | presentation conversion
        | serialization
        v
    MQTT representation
        |
        v
    MqttService
        |
        v
    WiFi
        |
        v
    Network

MQTT is responsible for:

- publishing Measurements
- publishing device state
- publishing diagnostics
- publishing availability
- receiving explicitly supported configuration commands

MQTT is not responsible for:

- acquiring Measurements
- interpreting weather data
- converting hardware representations
- converting physical units
- maintaining WiFi connectivity
- synchronizing system time
- storing persistent configuration
- storing long-term data

MqttService owns broker connectivity and transport only.

Inbound protocol adapters share the single MqttService callback through `MqttMessageRouter`. The router only multiplexes transport messages; it is not a domain command bus or event bus.

Translation of domain Measurements into MQTT topics and payloads belongs to MeasurementPublisher.

The initial MeasurementPublisher publishes every accepted Measurement without buffering, suppression or aggregation.

### Measurement Snapshot Diagnostics

`MeasurementSnapshotCache` is a passive observer at SensorManager's accepted-Measurement
boundary. It uses fixed bounded storage and retains only the latest completed canonical
Measurement, monotonic acceptance time and revision for each SensorId and MeasurementType.
`IMeasurementResolver` is the narrow read-only Controller-facing boundary and returns copied
snapshots. Web diagnostics also receive read-only access and apply Presentation Unit conversion
only while rendering.

The cache does not publish MQTT, own Sensor runtime, aggregate values, persist data or
influence Measurement acceptance and delivery. It is not history storage or an event bus. It
is cleared with the active Sensor runtime composition, so Controllers cannot continue using
pre-rebuild snapshots and a replacement Sensor must emit a new Measurement. A ControllerRuntime
rebuild is not inherently required when the same SensorId continues providing the referenced
MeasurementType. MeasurementPublisher remains the authoritative Measurement publisher and the
only downstream publishing sink.

Topics use:

    envnode/<deviceName>/sensor/<sensorId>/<measurementType>

with deterministic topic-safe device-name normalization, decimal SensorId serialization and stable lowercase MeasurementType names. Sensor names and implementation types are metadata and never form part of the external address.

Payloads use JSON with the Measurement timestamp formatted from its assigned epoch as local ISO-8601 including the UTC offset.

MeasurementPublisher is responsible for making the externally presented unit of every numeric Measurement unambiguous.

According to ADR-0005, canonical domain values may be converted into the configured Presentation Unit before serialization.

Examples include:

    canonical Temperature in °C
            |
            v
    configured Presentation Unit
            |
            +----> °C
            +----> °F

and:

    canonical AtmosphericPressure in Pa
            |
            v
    configured Presentation Unit
            |
            +----> Pa
            +----> hPa
            +----> kPa
            +----> inHg

Unit conversion changes representation only.

It never changes the physical meaning, timestamp, validity, quality, source or provenance of a Measurement.

Boolean Measurements and value-free event Measurements do not acquire artificial units.

Invalid Measurements never fabricate a value.

This separation intentionally decouples:

- measurement acquisition
- canonical domain representation
- presentation
- transport

Loss of MQTT connectivity must never stop:

- sensor acquisition
- local hardware control
- web administration
- diagnostics

MQTT shall continue reconnecting in the background while WiFi connectivity is available.

MQTT connectivity may become available before valid system time exists.

However, publication of timestamped Measurements should only begin after TimeService reports successful synchronization.

### Actuator and Controller MQTT adapters

Actuator runtime commands resolve `ActuatorId` through `ActuatorRuntime` and use `IOnOffActuator`. `ActuatorStatePublisher` observes actual state independently of whether the latest command came from Web, MQTT or a Controller.

Controller MQTT topics use the normalized root and Device name:

```text
envnode/<device>/controller/<slot>/status
envnode/<device>/controller/<slot>/cmd
envnode/<device>/controller/<slot>/parameter/<parameter>
envnode/<device>/controller/<slot>/cmd/parameter/<parameter>
```

Their semantics are deliberately distinct:

- `status` is retained implementation-specific runtime truth.
- `cmd` accepts transient `START` or `STOP`; these do not change persistent `enabled`.
- `parameter/<parameter>` is authoritative retained persisted parameter state published by EnvNode.
- `cmd/parameter/<parameter>` is an external request to mutate persistent configuration.

Blink status fields are `running`, `phase`, `target_available` and `last_result`. Threshold status fields are `running`, `source_available`, `measurement_valid`, `stale`, `decision`, `target_available`, `output_pending` and `last_result`. Threshold decision strings are `unknown`, `on` and `off`. Latest Measurement value is intentionally not duplicated; Sensor MQTT remains authoritative Measurement telemetry.

Blink parameters are `on_duration_ms` and `off_duration_ms`. Threshold parameters are `on_threshold`, `off_threshold` and `max_measurement_age_ms`. Parameter commands follow:

```text
MQTT cmd/parameter
 -> ControllerMqttAdapter
 -> candidate ControllerSlotConfiguration
 -> IConfigurationService validation and persistence
 -> RestartControllerRuntime
 -> ControllerRuntime rebuild
 -> retained parameter state publication
```

An unchanged requested value is a no-op and does not persist or rebuild. EnvNode never subscribes to authoritative `parameter/...` state topics. State and command topics are separated specifically to prevent retained publications from feeding back into configuration mutation.

The same persisted Controller configuration is rendered by WebService. Conversely, Web-originated parameter changes are observed and published by `ControllerStatePublisher`.

Threshold source identity is intentionally not split into scalar MQTT mutation parameters. `MeasurementSourceReference` remains an atomic structural configuration selected through the complete configuration/Web path.

Controller and generic Actuator Home Assistant discovery are not implemented. Existing Home Assistant discovery describes Sensors only.

`MqttDescriptionPublisher` exposes retained schema-1 Actuator and Controller descriptions through a
separate configured-truth path:

```text
Configuration + implementation registries
 -> pure ExternalDescriptionBuilder
 -> MqttDescriptionPublisher
 -> retained per-slot description topic
```

It fingerprints description-relevant persisted fields, publishes changes without waiting for a
runtime rebuild, clears `None` slots and forces complete fixed-slot reconciliation after reconnect.
It has no Actuator, Controller or Sensor runtime dependency. Runtime-only state continues to use
the existing status publishers and cannot trigger description publication.

### Home Assistant MQTT Discovery

`HomeAssistantDiscoveryPublisher` is a representation-only component separate from Sensors,
MeasurementPublisher and MqttService. It publishes one retained MQTT Device Discovery document
to:

    homeassistant/device/<stable-device-id>/config

The stable Device identifier is derived from the ESP32 eFuse MAC and is independent from the
editable Device name. Entity unique IDs combine that Device identifier, SensorId and
MeasurementType, preserving identity across Sensor renames and implementation replacement.

Discovery inspects active SensorManager metadata and points entities directly at the existing
ADR-0010 state topics. Numeric payloads use `value_json.value`. Units are derived from the same
Presentation configuration and UnitConverter symbols used by MeasurementPublisher. Discovery
is republished only after MQTT connection, active composition changes, Device-name changes or
Presentation Unit changes. The retained discovery policy is independent from Measurements,
which remain non-retained.

RainGaugeTip is adapted to an MQTT Event entity through a constant event JSON value template;
the physical Measurement payload remains unchanged and non-retained. RainfallIncrement is
exposed conservatively as a generic millimetre sensor without cumulative precipitation device
or state classes because each message represents one increment rather than a total. No rainfall
aggregation is performed. Per-Sensor availability and Home Assistant birth subscriptions are
deferred because no corresponding authoritative runtime model is currently present.

---

## HTTP / Web Interface

HTTP provides local device administration and diagnostics.

The web interface is primarily intended for:

- initial device provisioning
- device configuration
- WiFi configuration
- MQTT configuration
- time and NTP configuration
- device status
- diagnostics
- calibration parameters
- restart
- factory reset
- firmware update

The web interface is intentionally **not** a weather dashboard.

Historical visualization, charting and weather interpretation belong to external systems.

HTTP operates on top of the existing WiFi connectivity.

The Web Interface does not own configuration.

Instead it retrieves and modifies configuration exclusively through ConfigurationService.

This ensures that ConfigurationService remains the single owner of persistent configuration.

WebService also exposes runtime operations through domain runtime boundaries:

```text
Web Actuator command -> ActuatorId -> ActuatorRuntime -> IOnOffActuator
Web Controller command -> ControllerId -> ControllerRuntime Start/Stop
Web Controller edit -> IConfigurationService -> runtime effect -> ControllerRuntime rebuild
```

Controller Slot editing exposes common enabled, name and implementation fields. Blink adds target OnOff Actuator and On/Off durations. Threshold adds source Sensor, Measurement, target OnOff Actuator, On/Off thresholds and maximum Measurement age. Threshold Measurement choices come only from the selected configured Sensor implementation and are filtered to `FloatingPoint` + `State`; targets are filtered by `OnOff` capability and claims by other enabled Controllers. These filters improve presentation, while ConfigurationService remains authoritative.

WebService does not construct Actuators or Controllers, manipulate GPIO, or call concrete `BlinkController`, `ThresholdController` or `GpioOnOffActuator` objects.

---

## Configuration Changes

Configuration changes are submitted through HTTP POST requests.

The expected lifecycle is:

    Browser
       |
       v
    Web Interface
       |
       v
    ConfigurationService
       |
       +--> Validate
       |
       +--> Persist
       |
       +--> Update Runtime Configuration
       |
       v
    Restart if required

Validation always occurs before persistence.

Runtime configuration is updated only after successful persistence.

---

## Password Handling

Passwords are treated as sensitive configuration.

Therefore:

- passwords are never rendered back into the Web Interface
- passwords are never written to normal log output
- browser autofill must not silently overwrite stored credentials
- password changes require explicit user interaction

These rules apply equally to:

- WiFi credentials
- MQTT credentials

---

## Factory Reset

The Web Interface provides an explicit reset-to-defaults function.

Reset clears the complete EnvNode configuration namespace in persistent storage.

Conceptually:

    Reset Request
         |
         v
    Clear Preferences Namespace
         |
         v
    Restart
         |
         v
    Default Configuration
         |
         v
    Setup Access Point

The complete namespace is removed rather than individual keys.

This automatically includes future configuration parameters without requiring changes to the reset implementation.

---

# OTA Firmware Updates

Firmware updates are implemented as a staged lifecycle.

OTA is treated as a communication capability, but firmware activation remains a runtime lifecycle decision owned by RuntimeManager.

The OTA architecture intentionally separates:

- firmware transfer
- firmware validation
- firmware activation
- device restart

The OTA process therefore follows:

    Browser
       |
       v
    WebService
       |
       v
    OTAService
       |
       v
    Firmware staging
       |
       v
    RuntimeManager
       |
       v
    Explicit restart
       |
       v
    New firmware activation

## OTAService

OTAService owns firmware update handling.

Responsibilities include:

- receiving firmware upload data
- writing firmware data to the OTA partition
- tracking upload progress
- validating update completion
- reporting OTA state
- requesting device restart after successful staging

OTAService does not own:

- device restart execution
- configuration
- MQTT
- sensor acquisition
- firmware lifecycle decisions

OTAService must never directly call:

    ESP.restart()

The single device restart boundary remains inside RuntimeManager.

---

## OTA Lifecycle

A firmware update follows these states:

    Idle

      |
      v

    Uploading

      |
      v

    Verifying

      |
      v

    Firmware Staged

      |
      v

    Restart Required

      |
      v

    Running New Firmware

A successful upload does not immediately restart the device.

After successful staging:

    OTAService
        |
        v
    RuntimeManager.request(RestartDevice)

The restart remains pending until explicitly activated.

This prevents:

- unexpected device restarts
- interrupted configuration workflows
- loss of diagnostic information
- hidden lifecycle side effects

---

## Explicit Activation

Firmware activation requires an explicit restart action.

The restart flow is:

    User Request
          |
          v
    RuntimeManager
          |
          v
    performPendingRestart()
          |
          v
    ESP.restart()

There is exactly one executable restart boundary in the firmware.

All components requiring a device restart request the action through RuntimeManager.

No communication service, configuration service or Web handler may directly restart the device.

---

## Failed Updates

The currently running firmware remains active if:

- upload is interrupted
- the firmware image is invalid
- flash writing fails
- OTA finalization fails

Failed updates do not trigger a restart.

The device continues normal operation using the previously installed firmware.

---

## Web Interface Integration

The Firmware page provides:

- current firmware version
- OTA state
- upload functionality
- restart-required status

The Web Interface acts only as an adapter between the user interface and OTAService.

It does not contain firmware update logic.

After a successful upload the user receives:

    Firmware uploaded successfully.

    Firmware is staged.

    Device restart is required to activate the update.

The user may then explicitly activate the update.

---

## Runtime Integration

OTA integrates with the existing runtime lifecycle model.

The relationship is:

    Configuration Changes
              |
              v
        RuntimeManager

    OTA Update
              |
              v
        RuntimeManager

    Factory Reset
              |
              v
        RuntimeManager

RuntimeManager remains the single owner of lifecycle actions.

OTA therefore does not introduce a separate restart mechanism.

---

## Memory and Reliability

Firmware upload data is processed incrementally.

The complete firmware image is never loaded into RAM.

This ensures:

- bounded memory usage
- predictable runtime behaviour
- continued operation on memory-constrained hardware

OTA upload is isolated from sensor acquisition and measurement processing as far as technically possible.

A failed OTA operation must not compromise the running application.

---

## Development Workflow

The development workflow is:

Build firmware:

    PlatformIO Build

Generated firmware:

    .pio/build/<environment>/firmware.bin

The generated binary can be uploaded through the EnvNode Web Interface.

The OTA process then performs:

    firmware.bin
          |
          v
    Upload
          |
          v
    Stage
          |
          v
    Restart Required
          |
          v
    Activate

OTA updates are therefore independent from USB flashing.

USB flashing remains the recovery mechanism.

---

## Design Rules

The OTA implementation follows these rules:

- OTA transfers firmware; it does not own lifecycle decisions.
- Successful uploads do not automatically restart the device.
- RuntimeManager owns restart decisions.
- There is exactly one executable ESP.restart() boundary.
- Failed updates leave the running firmware untouched.
- OTA must not introduce dependencies into Sensors, Measurements or MQTT.

---

# Connectivity and Infrastructure Layer

The Connectivity and Infrastructure Layer provides reusable technical services required by both the Application Layer and the Communication Layer.

Infrastructure services currently include:

- Configuration
- WiFi
- Time synchronization
- Logging
- Persistent Storage

Current implementations include:

- ConfigurationService
- WiFiService
- TimeService

Future infrastructure services may include:

- OTAService
- BoardService

Each infrastructure service owns exactly one technical responsibility.

Infrastructure services intentionally avoid application-specific behaviour.

This allows application logic to evolve independently from platform implementation details.

---

# WiFi

WiFi provides network transport.

WiFi is not an application protocol.

It provides connectivity for:

- MQTT
- HTTP
- OTA
- NTP

Conceptually:

    MQTT -----+
              |
    HTTP -----+----> WiFi ----> Network
              |
    OTA ------+
              |
    NTP ------+

WiFi is responsible for:

- connecting to the configured network
- monitoring connection state
- reconnecting after temporary connection loss
- exposing network diagnostics
- providing initial provisioning through a setup access point
- providing the configured hostname

WiFi is not responsible for:

- MQTT
- HTTP
- persistent configuration
- time synchronization
- application logic

Configuration is obtained from ConfigurationService.

WiFiService never owns configuration itself.

---

# WiFi Provisioning

The setup access point is a provisioning and startup recovery mechanism.

It is intentionally **not** a fallback mode for temporary infrastructure failures.

Startup behaviour is:

    Boot
      |
      v
    Load Configuration
      |
      +---- missing / invalid ------> Setup Access Point
      |
      +---- valid
              |
              v
         Connect to WiFi
              |
              +---- success -------> Normal Operation
              |
              +---- startup timeout -> Setup Access Point

Once the device has successfully entered normal operation, temporary WiFi outages must never activate the setup access point.

Normal runtime behaviour is therefore:

    WiFi lost
        |
        v
    Continue local operation
        |
        v
    Retry WiFi connection
        |
        +---- success ------> Connected
        |
        +---- failure ------> Retry indefinitely

There is intentionally no transition from:

    Reconnecting

to

    Setup Access Point

Likewise, MQTT availability has no influence on provisioning behaviour.

An unavailable MQTT broker causes only MQTT reconnect attempts.

The setup access point therefore remains exclusively a provisioning and startup recovery mechanism.

---

# Persistent Storage

Persistent storage is used exclusively for device configuration and long-lived device settings.

The initial implementation uses the ESP32 Preferences API backed by the ESP32 Non-Volatile Storage (NVS).

Persistent configuration includes or is expected to include:

- device identity
- WiFi configuration
- MQTT configuration
- time configuration
- calibration values
- sensor settings
- actuator settings
- simulation settings
- Presentation Unit configuration

Presentation Unit configuration is stored globally per MeasurementType.

Examples include:

    Temperature -> Celsius

    AtmosphericPressure -> hectopascal

Presentation configuration contains typed unit selections rather than arbitrary unit strings.

Sensor Slot persistence uses stable implementation identifiers and raw typed resource values,
never user-facing implementation labels. Factory reset clears the same authoritative
ConfigurationService namespace and therefore restores the development Slot defaults:
three simulated Sensors and the AM2302 on GPIO27.

It affects external representation only.

It does not modify canonical Measurement values or Sensor behaviour.

Persistent storage is intentionally **not** used for:

- historical weather Measurements
- event history
- daily rainfall
- sunshine duration
- long-term logging
- time-series data

Historical data belongs outside the embedded device.

The EnvNode firmware is designed to measure and publish data, not to archive it.

---
# Configuration Ownership

Configuration has exactly one authoritative runtime representation.

ConfigurationService owns this representation.

All technical components obtain configuration through ConfigurationService.

Conceptually:

    Persistent Storage
           |
           v
    ConfigurationService
           |
           v
      Configuration
           |
       +---+---+--------+--------+-----------+----------------------+
       |       |        |        |           |                      |
       v       v        v        v           v                      v
     WiFi    MQTT     Time    Sensors       Web          MeasurementPublisher

No other subsystem owns persistent configuration.

Configuration changes are always performed through strongly typed ConfigurationService methods.

Examples include:

    setDeviceName(...)
    setWifiSSID(...)
    setWifiPassword(...)
    setMqttServer(...)
    setMqttPort(...)
    setMqttUsername(...)
    setMqttPassword(...)
    setTimezone(...)
    setPresentationUnit(...)

The exact typed API for Presentation Units is defined by the implementation, but arbitrary free-form unit strings are not used.

A generic key/value configuration interface is intentionally avoided.

This provides:

- compile-time safety
- explicit validation
- self-documenting interfaces
- controlled configuration evolution

Presentation Unit configuration is global per MeasurementType.

MeasurementPublisher consumes this configuration but never owns or persists it.

Changing a Presentation Unit affects future external representation only.

It does not require Sensor reinitialization and does not modify canonical Measurements.

---

# Configuration Lifecycle

The expected configuration lifecycle is:

    Boot
      |
      v
    Initialize Defaults
      |
      v
    Load Persistent Values
      |
      v
    Validate Configuration
      |
      v
    Create Runtime Configuration
      |
      v
    Start Infrastructure Services

Missing configuration values are considered normal.

Defaults remain active whenever no persisted value exists.

Configuration changes follow the sequence:

    Configuration Request
           |
           v
       Validate
           |
           v
       Persist
           |
           v
    Update Runtime Configuration

Runtime configuration is updated only after successful persistence.

This prevents divergence between runtime configuration and persistent storage.

---

## Reset to Defaults

Factory reset clears the complete EnvNode Preferences namespace.

Conceptually:

    Reset
       |
       v
    Clear Namespace
       |
       v
    Restart
       |
       v
    Default Configuration

The implementation intentionally removes the complete namespace rather than individual keys.

Future configuration fields therefore become part of the reset process automatically.

---

# Time

Time synchronization is provided by TimeService.

The current implementation uses SNTP (Network Time Protocol).

TimeService configures SNTP through the thread-safe ESP-IDF SNTP APIs. The configured POSIX timezone is applied separately to the system time library.

Time is considered infrastructure.

Application logic should never directly configure or manipulate the system clock.

Possible future synchronization sources include:

- RTC
- GPS
- DCF77

without changing higher application layers.

---

## Internal Time Representation

The authoritative runtime representation is Unix Epoch (`time_t`).

Using epoch time provides:

- unambiguous timestamps
- simple comparisons
- compact storage
- independence from local timezones

Internal timing for hardware behaviour continues to use monotonic timers rather than wall-clock time.

This avoids problems caused by:

- daylight-saving transitions
- NTP corrections
- manual clock changes
- leap adjustments

---

## Published Time Representation

Human-facing and externally published timestamps use local ISO-8601 representation including the UTC offset.

Example:

    2026-08-07T05:34:50+02:00

UTC representation remains available when required.

Example:

    2026-08-07T03:34:50Z

Local timestamps without timezone information must not be published.

The configured timezone automatically handles daylight-saving transitions.

---

## Time Synchronization

Time synchronization starts after WiFi connectivity becomes available.

Conceptually:

    WiFi Connected
          |
          v
    Start SNTP
          |
          v
    Synchronization
          |
          +---- success ------> Synchronized
          |
          +---- timeout ------> Retry Later

Synchronization is non-blocking.

The firmware continues operating while synchronization is pending.

SNTP is initialized once after WiFi becomes available. Subsequent request retries are handled by the SNTP subsystem without periodically reinitializing it.

MQTT connectivity may already exist before synchronization has completed.

Measurement publication, however, should begin only after valid synchronized time is available.

---
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

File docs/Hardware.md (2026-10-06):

# EnvNode Hardware Documentation

This page is the entry point for the EnvNode hardware documentation and KiCad reference designs.

## Specifications and Guidelines

- [EnvNode Module Interface – Hardware Specification](EnvNode_Module_Interface_Hardware_Specification.md) defines the shared electrical and mechanical expansion-module interface.
- [Hardware Design Guidelines](hardware_guidelines.md) contains general design rules used across EnvNode hardware.

## KiCad Reference Designs

- `hardware/kicad/DesignBlocks/EnvNode_Module_Connector_MainBoard/` contains the mainboard-side 2 x 7 connector block.
- `hardware/kicad/DesignBlocks/EnvNode_Module_Connector_Daughterboard_SMD/` contains the bottom-mounted SMD module connector block.
- `hardware/kicad/DesignBlocks/EnvNode_Module_Connector_Daughterboard_THT/` contains the bottom-mounted THT module connector block.
- [`hardware/kicad/DesignBlocks/ORing Power/`](../hardware/kicad/DesignBlocks/ORing%20Power/README.md) contains the castellated 5 V input, 3.3 V regulator, and dual-source 3.3 V ORing module together with its mainboard integration contract.

## Mainboard Implementation

[`hardware/kicad/MainBoards/EnvNode Mini/`](../hardware/kicad/MainBoards/EnvNode%20Mini/README.md) is at Revision 0.8 and implements two module slots. It exposes two top-entry 4-pin JST-SH connectors for each of `I2C0` and `I2C1`, using the pin order GND, `+3V3_SYS`, SDA, SCL. Each bus has one 4.7 kΩ pull-up pair that can be connected to `+3V3_SYS` through individual, normally open solder jumpers. Two additional top-entry JST-PH connectors expose the input-only GPIO34 / ADC1_CH6 and GPIO35 / ADC1_CH7 signals together with GND, `+5V`, and `+3V3_SYS`. The mainboard identity is stored in a `24LC32` EEPROM on `I2C0` at address `0x50`. Input protection, 5 V conversion, and 3.3 V source ORing are supplied by the castellated [`ORing Power`](../hardware/kicad/DesignBlocks/ORing%20Power/README.md) module.
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

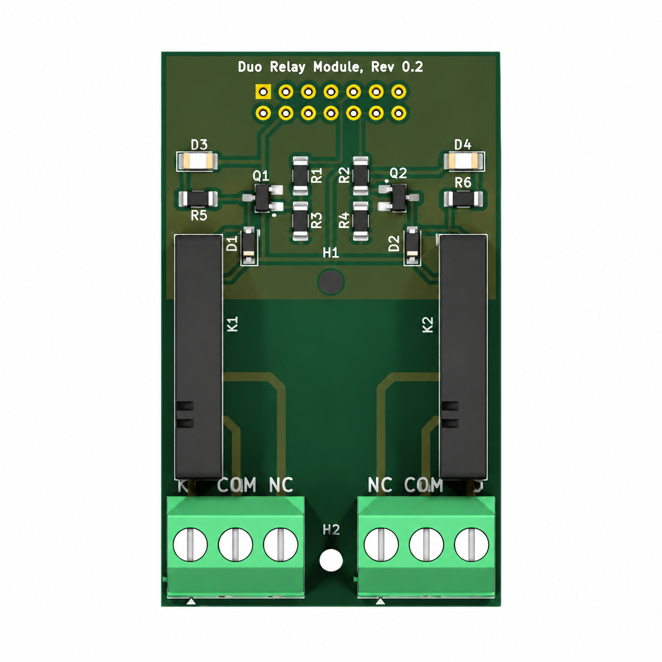
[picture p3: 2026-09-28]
images/branding/duorelay-product-render-provisional-v1.png

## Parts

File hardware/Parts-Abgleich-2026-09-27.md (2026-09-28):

# Bauteilabgleich und Verbrauch – 27.09.2026

Auftrag vom 22.09.2026, am 27.09.2026 abgeschlossen. Verbrauch anhand der vor der Umstellung gespeicherten Kits gebucht. Zwei EnvNode Mini Rev. 0.3 (ein funktionaler Aufbau, ein Ausschuss), jeweils ohne USB-C-Buchse, mit EEPROM und 5,1-kΩ-Widerständen; ein DuoRelay mit EEPROM, dessen 100-nF-Kondensator und Schraubklemmen; ein zusätzlicher zerstörter EEPROM; ein alter RainDetector. Mechanische Gehäuseanschlüsse wurden durch „bestückt“ nicht als verbraucht interpretiert.

## Verbrauchsbuchung

Negative Werte sind ausdrücklich genehmigte Bestandsdifferenzen. Keine nicht belegten Wareneingänge oder Umbuchungen auf Ersatzartikel vorgenommen. Bereits bestellte Mengen bleiben unverändert.

| Part | Bauteil | Vorher | Verbrauch | Danach |
|---|---|---:|---:|---:|
| ENP-00006 | 100 nF Keramik SMD | 50 | 10 | 40 |
| ENP-00007 | 10 uF Keramik SMD | 10 | 2 | 8 |
| ENP-00008 | 47 uF 10V Tantal | 14 | 2 | 12 |
| ENP-00056 | Elektrolytkondensator 10 µF SMD | 10 | 2 | 8 |
| ENP-00055 | Schottky-Diode SS14, SMA | 20 | 4 | 16 |
| ENP-00012 | JST - Stiftleiste, gerade, 1x2-polig - PH | 6 | 2 | 4 |
| ENP-00054 | Buchsenleiste 2x7, 2,54 mm, vertikal | 0 | 4 | -4 |
| ENP-00026 | JST-SH Stiftleiste, 4-polig, horizontal | 0 | 4 | -4 |
| ENP-00005 | 4.7 kOhm 1% SMD 1206 | 62 | 8 | 54 |
| ENP-00010 | ESP32-DevKitC | 3 | 2 | 1 |
| ENP-00102 | I²C-EEPROM 32 Kbit, SOIC-8 | 10 | 4 | 6 |
| ENP-00009 | LDO 3.3V SOT-223 | 3 | 2 | 1 |
| ENP-00103 | EnvNode Mini PCB Rev 0.3 | 0 | 2 | -2 |
| ENP-00090 | SMD-Widerstand 5,1 kOhm, 5 %, 1206 | 0 | 4 | -4 |
| ENP-00033 | Schnelle Schaltdiode 1N4148W | 50 | 2 | 48 |
| ENP-00064 | LED SMD 1206, rot | 20 | 2 | 18 |
| ENP-00059 | Stiftleiste 2x7, 2,54 mm, vertikal, Bottom-Mount | 8 | 1 | 7 |
| ENP-00034 | Schraubklemme 1x3, horizontal | 0 | 2 | -2 |
| ENP-00023 | Steck-Printrelais, 1 CO, 6 A, 5 V DC sensitiv | 4 | 2 | 2 |
| ENP-00035 | NPN-Transistor BC817 | 50 | 2 | 48 |
| ENP-00036 | Widerstand 1 kΩ SMD | 20 | 2 | 18 |
| ENP-00016 | SMD-Widerstand, 1206, 100 kOhm, 250 mW, 0,1% | 14 | 4 | 10 |
| ENP-00065 | Widerstand 1,5 kΩ SMD | 0 | 2 | -2 |
| ENP-00104 | DuoRelay FullSize PCB Rev 0.3 | 0 | 1 | -1 |
| ENP-00019 | Stiftleiste, 8-polig, Raster 2,54mm | 0 | 2 | -2 |
| ENP-00003 | PinSocket 1x4, 2.54 mm | 4 | 2 | 2 |
| ENP-00013 | MOSFET, N-Ch 30V 5,7A 0,018R, SOT-23 | 5 | 1 | 4 |
| ENP-00017 | SMD-Widerstand, 1206, 100 Ohm, 250 mW, 5% | 50 | 1 | 49 |
| ENP-00018 | SMD-Widerstand, 1206, 10 kOhm, 250 mW, 0,1% | 9 | 1 | 8 |
| ENP-00020 | Timer-IC, Typ 555, SO-8 | 3 | 1 | 2 |
| ENP-00053 | RainDetector PCB | 5 | 1 | 4 |

## Planung

| Kit | Revision | Menge |
|---|---|---:|
| EnvNode Mini | 0.6 | 2 |
| Weatherstation | 0.1 | 2 |
| ORing Power | 0.1 | 5 insgesamt |
| RainDetectorHead | 0.1 | 3 |
| RainDetectorController | 0.3 | 2 |
| AnalogHydroPressure | 0.4 | 2 |

Die fünf ORing-Module enthalten vier Module für die Mainboards und ein Reservemodul. Unterbaugruppen stehen in der BOM, werden aber ausschließlich über ihr eigenes Kit in der Bestellliste gezählt. AnalogHydroPressure wird erst nach Eingang der Rev.-0.4-PCBs aufgebaut. Seine bisherigen DNP-Positionen bleiben DNP.

Die sechs angekündigten PCB-Fertigungslose zu jeweils fünf Stück wurden nicht zusätzlich als Wareneingang oder Bestellung gebucht. Vorhandene PCB-Einträge bleiben erhalten. ENP-00121 (Weatherstation) enthält noch kopierte Mini-Daten bei Revision, Footprint/Pfad, MPN und Notizen; diese sind beim eigenen PCB-Nachtrag zu korrigieren. PCB-Zeilen werden als „PCB-Nachtrag“ gekennzeichnet und nicht erneut als Kaufvorschlag ausgegeben.

## Bauteile und Quellen

- Vertikaler JST-SH: ENP-00122, JST BM04B-SRSS-TB, DigiKey 455-BM04B-SRSS-TBCT-ND. Vier pro Mini und acht pro Weatherstation, insgesamt 24. Horizontaler ENP-00026 bleibt ein separater Artikel. [JST-Datenblatt](https://www.jst.com/wp-content/uploads/2021/01/eSH.pdf), [DigiKey](https://www.digikey.de/de/products/detail/jst-sales-america-inc/BM04B-SRSS-TB/926696).
- USB-C ORing: ENP-00117, GCT USB4125-GF-A-0190. Mouser-Artikelnummer korrigiert auf 640-USB4125-GF-A-190. Fünf benötigt. [Mouser](https://www.mouser.de/de/ProductDetail/GCT/USB4125-GF-A-0190), [GCT-Zeichnung](https://gct.co/files/drawings/usb4125.pdf).
- ORing JST-PH SMD: ENP-00119. Herstellerbezeichnung B2B-PH-SM4-TBT, Reichelt-Artikel JST PH2P SM4. KiCad-Footprintname bleibt B2B-PH-SM4-TB. [JST](https://jst.de/produkt/3424/692450-00), [Reichelt](https://www.reichelt.de/de/de/shop/produkt/jst_-_stiftleiste_rm_2_mm_1x2_polig_gerade_-_ph-190546).
- Lieferantendaten wurden am 22.09.2026 recherchiert. Preise sind keine aktuellen Angebote. Offene Preise bleiben leer und werden in der Bestellliste ausgewiesen.

## Vorläufige Fehlteile

Berechnet mit erfasstem Bestand, unveränderten offenen Bestellungen und bereits freigegebenen Alternativen. Negative Bestandsdifferenzen erhöhen den Vorschlag; tatsächliche Wareneingänge und verbaute Ersatzartikel vor Kauf klären. Manuelle Bestellmengen wurden erhalten und keine Bestellung ausgelöst.

| Part | Bauteil | Lieferant | Artikelnummer | Bedarf | Bestellvorschlag |
|---|---|---|---|---:|---:|
| ENP-00009 | LDO 3.3V SOT-223 | Reichelt | LM 3940 IMP-3 | 5 | 6 |
| ENP-00010 | ESP32-DevKitC | Noch festlegen | offen | 4 | 3 |
| ENP-00027 | 16-Bit ADC mit I²C | DigiKey | 296-24934-1-ND | 2 | 2 |
| ENP-00054 | Buchsenleiste 2x7, 2,54 mm, vertikal | Reichelt | MPE 094-2-014 | 6 | 8 |
| ENP-00106 | Schottky-Diode B260S1F-7 | Reichelt | B260S1F-7 | 2 | 2 |
| ENP-00080 | WEIPU SP13 Gehäusebuchse, 2-polig | Noch festlegen | offen | 2 | 2 |
| ENP-00081 | WEIPU SP13 Kabelstecker, 2-polig | Noch festlegen | offen | 2 | 2 |
| ENP-00084 | WEIPU SP13 Gehäusebuchse, 4-polig | Noch festlegen | offen | 2 | 2 |
| ENP-00085 | WEIPU SP13 Kabelstecker, 4-polig | Noch festlegen | offen | 2 | 2 |
| ENP-00111 | SMD-Stiftleiste 2x10, Zuschnitt auf 2x2 | Reichelt | SL 2X10G SMD2,54 | 3 | 3 |
| ENP-00115 | SMD-Heizwiderstand 15 Ohm, 1 %, 1206 | Reichelt | WAL WR12X15R0FTL | 60 | 60 |
| ENP-00116 | Buchsenleiste 2x2, 2,54 mm, THT | Reichelt | BKL 10120957 | 4 | 4 |
| ENP-00117 | USB-C-Buchse, 6-polig, Power-only, Top-Mount | Mouser | 640-USB4125-GF-A-190 | 5 | 5 |
| ENP-00119 | JST-PH Stiftleiste, 2-polig, vertikal, SMD | Reichelt | JST PH2P SM4 | 5 | 5 |
| ENP-00122 | JST-SH Stiftleiste, 4-polig, vertikal | DigiKey | 455-BM04B-SRSS-TBCT-ND | 24 | 24 |
| ENP-00110 | SMD-Widerstand 5,1 kOhm, 1 %, 1206 | DigiKey | 541-5.10KFCT-ND | 10 | 8 |
| ENP-00025 | JST-PH Stiftleiste, 4-polig, vertikal | Reichelt | JST PH4P ST | 20 | 20 |

## Prüfung

BOMs von Mini und Weatherstation mit aktuellen KiCad-Exporten abgeglichen. Bedarf unabhängig aus BOM-Mengen und Planstückzahlen nachgerechnet. EEPROM-Verbrauch sowie JST-SH-, USB-C-, Regler- und Heizwiderstandsbedarf geprüft. Formeln und exportierte Datei auf Fehler geprüft.

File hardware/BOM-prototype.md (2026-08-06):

# Prototype BOM

## Ordered

- ESP32 DevKit

## To order

- ADS1115 Breakout
- BMP390 Breakout
- SHT41 Breakout
- DS18B20 Probe

## Pending decision

- Solar Cell
- Shunt

## Later (PCB)

- AO3400A
- BMP390 IC
- ADS1115 IC
- passive components

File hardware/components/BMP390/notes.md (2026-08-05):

# BMP390

## Purpose

Digital barometric pressure and temperature sensor.

Used to measure:

- atmospheric pressure
- sensor temperature

Communication:

- I²C

SPI support is intentionally not used.

---

# Documents

Datasheet

BMP390 Datasheet Revision x.x

Reference Design

Bosch Typical Application Circuit

Breakout

<Hersteller>

---

# Electrical Connections

## Power

VDD

3.3 V

VDDIO

3.3 V

Both supply pins require local decoupling capacitors.

### Decoupling

100 nF

between VDD and GND

100 nF

between VDDIO and GND

---

# Interface

Interface

I²C

SPI intentionally disabled.

---

## SDA

Connected to common I²C bus.

---

## SCL

Connected to common I²C bus.

---

## CSB

Connected permanently to 3.3 V.

Reason:

Only I²C operation is required.

No runtime interface switching is needed.

---

## SDO

Connected to GND.

Resulting I²C address:

0x76

Only one BMP390 is expected on the bus.

Address selection jumper not required.

---

## INT

Not connected.

Reason:

Polling is sufficient for the intended measurement interval.

A test pad may optionally be provided.

---

# Shared Components

The following components are intentionally shared by the complete I²C bus.

Not per sensor.

- SDA pull-up
- SCL pull-up

Reason:

There shall only be one pull-up pair on the complete bus.

---

# Components required on PCB

BMP390

2 × 100 nF

---

# Components intentionally omitted

No voltage regulator

No level shifter

No address jumper

No SPI header

No interrupt header

---

# KiCad Status

Not yet implemented.

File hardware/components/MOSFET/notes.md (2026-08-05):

# AO3400A

Purpose

Logic level N-channel MOSFET.

Used for

- Rain heater

Package

SOT-23

Reasons for selection

- fully enhanced at 3.3 V gate drive
- very low RDS(on)
- inexpensive
- widely available
- easy to solder

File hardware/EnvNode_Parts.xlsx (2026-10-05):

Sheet: Parts
Part_ID | Category | Description | Value_Rating | Package_Footprint | Manufacturer | MPN | Found_In | KiCad_References | Source | Review_Status | Notes | Duplicate_Check_Key
ENP-00001 | Kabelsatz | Set, SET JST-PH 4-polig 2.00mm vertikaler PCB-Stecker, Buchse THT | JST-PH, 4-polig, Set, Kabellänge 4cm |  | JST |  | EnvNode | GPIO's | BOM_Mainboard.xlsx | OK | GPIO-Anschlüsse; exakte Herstellerartikelnummer vor Bestellung gegen Footprint und Orientierung prüfen Set-Inhalt gegenüber dem separat aus KiCad abgeleiteten PCB-Header prüfen. | SET, SET JST-PH 4-POLIG 2.00MM VERTIKALER PCB-STECKER, BUCHSE THT| | SET, SET JST-PH 4-POLIG 2.00MM VERTIKALER PCB-STECKER, BUCHSE THT
ENP-00002 | Kabelsatz | Qwiic/JST-SH, 4-poliges Pigtail JST | JST-SH/Qwiic, 4-polig |  | JST |  | EnvNode | I2CA0 1-3 I2C1 1-3 | BOM_Mainboard.xlsx | OK | Qwiic-Konvention: GND=schwarz, 3V3=rot, SDA=blau, SCL=gelb; Kabelbelegung vor Anschluss prüfen Pigtail ist ein Beschaffungsartikel und nicht der PCB-Steckverbinder. | QWIIC/JST-SH, 4-POLIGES PIGTAIL JST| | QWIIC/JST-SH, 4-POLIGES PIGTAIL JST
ENP-00003 | Steckverbinder | PinSocket 1x4, 2.54 mm | 1x4, 2,54 mm | PinSocket_1x04_P2.54mm_Vertical | BKL | 10120946 | EnvNode; RainDetector | EnvNode I2C0_4,I2C1_4; RainDetector J3,J4 | BOM_Mainboard.xlsx | OK | Für interne Qwiic-Breakouts; Bauhöhe und Ausführung passend zur Mechanik wählen | 10120946 | 10120946
ENP-00004 | Steckverbinder | PinSocket 1x20, 2.54mm, cut to 19 Pins | 1x20, 2,54 mm, trennbar |  | fischer Elektronik | BL1.20 G | EnvNode | ESP32 | BOM_Mainboard.xlsx | OK | Für ESP32-DevKitC mit 38 Pins; alternativ eine geeignete 38-Pin-ESP32-Fassung verwenden | BL1.20 G | BL1.20 G
ENP-00005 | Widerstand | 4.7 kOhm 1% SMD 1206 | 4,7 kΩ, 1 %, 250 mW | Resistor_SMD:R_1206_3216Metric_Pad1.30x1.75mm_HandSolder | Vishay | CRCW12064K70FKEA | EnvNode; EnvNodeMini Rev 0.2; AnalogInput Rev 0.1; AnalogHydroPressure; Aktuell 29.09.2026: EnvNode Mini Bausatz Rev 0.8; EnvNode Weatherstation Bausatz Rev 0.2 | ENK-00001 R1,R2,R3,R4; ENK-00008 R1,R2,R3,R4 | BOM_Mainboard.xlsx | OK | I2C-Pull-ups für die beiden I2C-Busse | CRCW12064K70FKEA | CRCW12064K70FKEA
ENP-00006 | Kondensator | 100 nF Keramik SMD | 100 nF, 10 %, X7R, 100 V | Capacitor_SMD:C_1206_3216Metric_Pad1.33x1.80mm_HandSolder | KEMET | C1206F104K1RACTU | EnvNode; EnvNodeMini Rev 0.2; AnalogHydroPressure; RainDetector; SolarRadiation; Empty FullSize/HalfSize SMD/THT; DuoRelay Rev 0.2; RainDetectorController Rev 0.3; ORing Power Rev 0.1; Aktuell 29.09.2026: EnvNode Mini Bausatz Rev 0.8; DuoRelay FullSize Bausatz Rev 0.3; RainDetectorController Rev 0.3; ORing Power Modul Rev 0.1; EnvNode Weatherstation Bausatz Rev 0.2; SolarRadiation Rev 0.1 | ENK-00001 C1; ENK-00002 C1 (DNP); ENK-00006 C1; ENK-00007 C1,C5; ENK-00008 C1; ENK-00009 C2 | BOM_Mainboard.xlsx | OK | Spannungsfestigkeit, Dielektrikum und Bauform vor Bestellung gegen Schaltplan und Footprint prüfen; C1 ist in allen vier aktuellen Empty-Schemata derzeit DNP; C1 ist im aktuellen DuoRelay-Schema derzeit DNP | C1206F104K1RACTU | C1206F104K1RACTU
ENP-00007 | Kondensator | 10 uF Keramik SMD | 10 µF, 25 V, X7R | Capacitor_SMD:C_1206_3216Metric_Pad1.33x1.80mm_HandSolder | Kyocera AVX | 12063C106KAT2A | EnvNode; EnvNodeMini Rev 0.2; ORing Power Rev 0.1; Aktuell 29.09.2026: ORing Power Modul Rev 0.1; SCT013Head Rev 0.1 | ENK-00007 C3; ENK-00010 C2 | BOM_Mainboard.xlsx | OK | Spannungsfestigkeit, Dielektrikum und Bauform vor Bestellung gegen Schaltplan und Footprint prüfen | 12063C106KAT2A | 12063C106KAT2A
ENP-00008 | Kondensator | 47 uF 10V Tantal | 47 µF, 10 V | Capacitor_Tantalum_SMD:CP_EIA-3528-21_Kemet-B | Kyocera AVX | TAJB476K010RNJ | EnvNode; EnvNodeMini Rev 0.2; ORing Power Rev 0.1; Aktuell 29.09.2026: ORing Power Modul Rev 0.1 | ENK-00007 C4 | BOM_Mainboard.xlsx | OK | Polarisiert; Bauform B | TAJB476K010RNJ | TAJB476K010RNJ
ENP-00009 | Spannungsregler | LDO 3.3V SOT-223 | 3,3 V, 1 A | Package_TO_SOT_SMD:SOT-223-3_TabPin2 | Texas Instruments | LM3940IMP-3.3/NOPB | EnvNode; EnvNodeMini Rev 0.2; ORing Power Rev 0.1; Aktuell 29.09.2026: ORing Power Modul Rev 0.1 | ENK-00007 U1 | BOM_Mainboard.xlsx | OK | Footprint und thermische Auslegung vor Bestückung prüfen | LM3940IMP-3.3/NOPB | LM3940IMP-3.3/NOPB
ENP-00010 | Entwicklungsmodul | ESP32-DevKitC | 38 Pin | PCM_Espressif:ESP32-DevKitC | Espressif Systems |  | EnvNode; EnvNodeMini Rev 0.2; Aktuell 29.09.2026: EnvNode Mini Bausatz Rev 0.8; EnvNode Weatherstation Bausatz Rev 0.2 | ENK-00001 U3; ENK-00008 U3 | BOM_Mainboard.xlsx | OK | Exakte Modulvariante und Pinout vor Bestückung prüfen Hersteller/MPN aus verschobenen Altdaten korrigiert; genaue DevKitC-Variante fehlt. Nutzer 29.09.2026: ESP32-Variante ausdrücklich offen lassen. Lieferant/MPN nicht freigegeben. | ESP32-DEVKITC|PCM_ESPRESSIF:ESP32-DEVKITC | ESP32-DEVKITC|PCM_ESPRESSIF:ESP32-DEVKITC
ENP-00011 | PCB | EnvNode Mainboard Rev 0.1 | Revision 0.1 |  | JLCPCB |  | EnvNode |  | BOM_Mainboard.xlsx | OK | Unbestückte Leiterplatte; SMD-Lötjumper sind PCB-Strukturen und keine Kaufteile Historische PCB-Revision; aktueller KiCad-Stand ist Revision 0.2. | ENVNODE MAINBOARD REV 0.1| | ENVNODE MAINBOARD REV 0.1
ENP-00012 | Steckverbinder | JST - Stiftleiste, gerade, 1x2-polig - PH | JST-PH, 2-polig, 2,00 mm | Connector_JST:JST_PH_B2B-PH-K_1x02_P2.00mm_Vertical | JST | B2B-PH-K-S | EnvNode; Mini bis Rev 0.3; AnalogHydroPressure Rev 0.4 | Legacy Mini J1; AnalogHydroPressure J3 | BOM_Mainboard.xlsx | OK |  | B2B-PH-K-S | B2B-PH-K-S
ENP-00013 | MOSFET | MOSFET, N-Ch 30V 5,7A 0,018R, SOT-23 | N-Kanal, 30 V, 5,7 A | Package_TO_SOT_SMD:SOT-23 | Alpha&Omega Semiconductor | AO3400A | RainDetector; RainDetectorController Rev 0.3; Aktuell 29.09.2026: RainDetectorController Rev 0.3 | ENK-00006 Q1 | BOM_Mainboard.xlsx | OK |  | AO3400A | AO3400A
ENP-00014 | Sensormodul | Arduino - Temperatur- & Feuchtigkeitssensor, SHTC3 | SHTC3 Breakout |  | Soldered | 333032 | Sensor |  | BOM_Mainboard.xlsx | OK |  | 333032 | 333032
ENP-00015 | Entwicklungsmodul | Entwicklerboards - ADC, 4 Kanal, 16-Bit, ADS1115 | ADS1115 Breakout, 4 Kanal, 16 Bit |  | Soldered | 333095 | A/D Wandler |  | BOM_Mainboard.xlsx | OK |  | 333095 | 333095
ENP-00016 | Widerstand | SMD-Widerstand, 1206, 100 kOhm, 250 mW, 0,1% | 100 kΩ, 0,1 %, 250 mW | Resistor_SMD:R_1206_3216Metric_Pad1.30x1.75mm_HandSolder | Panasonic | ERA8AEB104V | RainDetector; DuoRelay; AnalogHydroPressure; RainDetectorController Rev 0.3; Aktuell 29.09.2026: DuoRelay FullSize Bausatz Rev 0.3; RainDetectorController Rev 0.3 | ENK-00002 R3,R4; ENK-00006 R2,R4 | BOM_Mainboard.xlsx | OK | Lieferanten-Bestellnummer in der Altdatei enthält vermischte Angaben. | ERA8AEB104V | ERA8AEB104V
ENP-00017 | Widerstand | SMD-Widerstand, 1206, 100 Ohm, 250 mW, 5% | 100 Ω, 5 %, 250 mW | Resistor_SMD:R_1206_3216Metric_Pad1.30x1.75mm_HandSolder | YAGEO | RC1206JR-07100RL | RainDetector; SolarRadiation; RainDetectorController Rev 0.3; Aktuell 29.09.2026: RainDetectorController Rev 0.3; SolarRadiation Rev 0.1 | ENK-00006 R1; ENK-00009 R2 | BOM_Mainboard.xlsx | OK |  | RC1206JR-07100RL | RC1206JR-07100RL
ENP-00018 | Widerstand | SMD-Widerstand, 1206, 10 kOhm, 250 mW, 0,1% | 10 kΩ, 0,1 %, 250 mW | Resistor_SMD:R_1206_3216Metric_Pad1.30x1.75mm_HandSolder | Panasonic | ERA8AEB103V | RainDetector; RainDetectorController Rev 0.3; Aktuell 29.09.2026: RainDetectorController Rev 0.3; SCT013Head Rev 0.1 | ENK-00006 R3; ENK-00010 R2,R3 | BOM_Mainboard.xlsx | OK | Offensichtlich zusammengesetzte MPN aus Altdaten normalisiert. | ERA8AEB103V | ERA8AEB103V
ENP-00019 | Steckverbinder | Stiftleiste, 8-polig, Raster 2,54mm | 1x8, 2,54 mm | Connector_PinHeader_2.54mm:PinHeader_1x08_P2.54mm_Vertical | BKL Electronic | 10120505 | RainDetector | J1,J2 | BOM_Mainboard.xlsx | OK |  | 10120505 | 10120505
ENP-00020 | IC | Timer-IC, Typ 555, SO-8 | CMOS 555 | Package_SO:SOIC-8_3.9x4.9mm_P1.27mm | Renesas | ICM7555IBAZ | RainDetector; RainDetectorController Rev 0.3; Aktuell 29.09.2026: RainDetectorController Rev 0.3 | ENK-00006 U1 | BOM_Mainboard.xlsx | OK |  | ICM7555IBAZ | ICM7555IBAZ
ENP-00021 | Steckverbinder | PinSocket 1x8, 2,54mm SMD | 1x8, 2,54 mm, SMD |  | fischer Elektronik | BL 3 8 G | Stall.biz/Weatherman-Detektorplatine | Mechanischer Gegenstecker zu RainDetector J1/J2; nicht im RainDetector-KiCad geführt | BOM_Mainboard.xlsx; Nutzerklärung 2026-09-01 | OK | 1×8-SMD-Buchsenleiste sitzt physisch auf der Stall.biz/Weatherman-Detektorplatine. Auf der RainDetector-Platine werden für J1/J2 die 1×8-THT-Stiftleisten ENP-00019 bestückt. | BL 3 8 G | BL 3 8 G
ENP-00022 | Widerstand | SMD-Widerstand, 1206, 47 Ohm, 250 mW, 5% (https://www.reichelt.de/de/de/shop/produkt/smd-widerstand_1206_47_ohm_250_mw_5_-250359) | 47 Ω | Resistor_SMD:R_1206_3216Metric_Pad1.30x1.75mm_HandSolder | RND components | RND 1551206S4J0470T5E | Detector |  | BOM_Mainboard.xlsx | OK |  | RND 1551206S4J0470T5E | RND 1551206S4J0470T5E
ENP-00023 | Relais | Steck-Printrelais, 1 CO, 6 A, 5 V DC sensitiv | 5 V, 1 Wechsler, 6 A | Relay_THT:Relay_SPDT_Finder_34.51_Vertical | finder | 34.51.7.005.0010 | DuoRelay; Aktuell 29.09.2026: DuoRelay FullSize Bausatz Rev 0.3 | ENK-00002 K1,K2 | BOM_Mainboard.xlsx | OK |  | 34.51.7.005.0010 | 34.51.7.005.0010
ENP-00024 | IC | I²C-EEPROM 2 Kbit mit vorprogrammierter EUI-64 und zwei Adresspins | 2 Kbit, I²C, EUI-64, A0/A1, 1,7–5,5 V | Package_TO_SOT_SMD:SOT-23-6 | Microchip Technology | 24AA025E64T-I/OT | EnvNode; EnvNodeMini Rev 0.2; Empty FullSize/HalfSize SMD/THT; DuoRelay; AnalogHydroPressure | EnvNode U3; EnvNodeMini Rev 0.2 U2; Empty-Boards U1; DuoRelay U1; AnalogHydroPressure U1 | KiCad; Microchip datasheet DS20002124G; DigiKey Produktseite, abgerufen 2026-09-02 | OK | Gemeinsamer Identifikations-EEPROM für alle Boards. Frühere Lieferantendaten gehörten zur falschen SPI-Version 25AA02E64T-I/OT und wurden entfernt; Bezugsquelle, Bestellnummer und Preis neu ergänzen. Auf Modulboards derzeit DNP.; In allen vier aktuellen Empty-Schemata derzeit DNP; A1 liegt an +3V3_SYS, A0 wird über J1 herausgeführt; U1 ist in den aktuellen DuoRelay- und AnalogHydroPressure-Schemata derzeit DNP Bezug als Cut Tape bei DigiKey; keine parametrischen Ersatztypen ohne vorprogrammierte EUI-64 verwenden. | 24AA025E64T-I/OT | 24AA025E64T-I/OT
ENP-00025 | Steckverbinder | JST-PH Stiftleiste, 4-polig, vertikal | 4-polig, 2,00 mm | Connector_JST:JST_PH_B4B-PH-K_1x04_P2.00mm_Vertical | JST | B4B-PH-K-S | EnvNode; Weatherstation Rev 0.1; Aktuell 29.09.2026: EnvNode Mini Bausatz Rev 0.8; EnvNode Weatherstation Bausatz Rev 0.2 | ENK-00001 ADC1,ADC2; ENK-00008 ADC1,ADC2,ADC3,ADC4,GPIO4,GPIO14,GPIO16,GPIO17,GPIO27,GPIO32 | KiCad | OK | Mögliche Überschneidung mit dem vorhandenen JST-PH-Set prüfen. | B4B-PH-K-S | B4B-PH-K-S
ENP-00026 | Steckverbinder | JST-SH Stiftleiste, 4-polig, horizontal | 4-polig, 1,00 mm | Connector_JST:JST_SH_SM04B-SRSS-TB_1x04-1MP_P1.00mm_Horizontal | JST | SM04B-SRSS-TB | EnvNode; EnvNodeMini Rev 0.2; SolarRadiation; Aktuell 29.09.2026: SolarRadiation Rev 0.1 | ENK-00009 I2C1 | KiCad; DigiKey Produktseite, abgerufen 2026-09-08 | OK | Exakter JST-SH-Header SM04B-SRSS-TB für den vorhandenen 4-poligen 1,00-mm-SMD-Rechtwinkel-Footprint; als DigiKey-Gurtabschnitt beschaffbar. Nicht mit dem Qwiic-Pigtail zusammenführen. | SM04B-SRSS-TB | SM04B-SRSS-TB
ENP-00027 | IC | 16-Bit ADC mit I²C | ADS1115IDGS | Package_SO:TSSOP-10_3x3mm_P0.5mm | Texas Instruments | ADS1115IDGS | AnalogInput; SolarRadiation; AnalogHydroPressure; Aktuell 29.09.2026: SolarRadiation Rev 0.1 | ENK-00009 U1 | KiCad | OK | Nicht mit dem vorhandenen ADS1115-Entwicklungsboard zusammenführen. | ADS1115IDGS | ADS1115IDGS
ENP-00028 | Kondensator | Keramikkondensator 1 µF SMD | 1 µF | Capacitor_SMD:C_1206_3216Metric_Pad1.33x1.80mm_HandSolder | Kyocera | 12065C105JAT2A | AnalogInput; AnalogHydroPressure | C1; AnalogHydroPressure C4,C7 | KiCad | OK |  | 12065C105JAT2A | 12065C105JAT2A
ENP-00029 | Diode | Dual-Schottky-Diode BAT54S | BAT54S | Package_TO_SOT_SMD:SOT-23 | Diotec | BAT54S | AnalogInput; AnalogHydroPressure | D1; AnalogHydroPressure D1 | KiCad | OK | Aktuelles AnalogHydroPressure verwendet SOT-23 und stimmt damit mit dem Artikel-Footprint überein; Gehäuse der bestellten Variante dennoch prüfen. | BAT54S | BAT54S
ENP-00030 | Steckverbinder | Buchsenleiste 2x4, vertikal | 2x4, 2,54 mm | PinSocket_2x04_P2.54mm_Vertical / EnvNode Bottom-Variante |  |  | Legacy Rev 0.1: EnvNodeMini; AnalogInput; DuoRelay | AnalogInput J1,J2; DuoRelay J1,J2; EnvNodeMini J1,J2,J4,J5 | KiCad | Prüfen | Legacy-Artikel für die Modulsteckverbindung Rev 0.1; nicht für die aktuellen 2x7-Steckplätze verwenden. Legacy: eindeutige Ausführung fehlt; keine spekulative Hersteller- oder Lieferantenzuordnung. | BUCHSENLEISTE 2X4, VERTIKAL|PINSOCKET_2X04_P2.54MM_VERTICAL / ENVNODE BOTTOM-VARIANTE | BUCHSENLEISTE 2X4, VERTIKAL|PINSOCKET_2X04_P2.54MM_VERTICAL / ENVNODE BOTTOM-VARIANTE
ENP-00031 | Steckverbinder | Buchsenleiste 1x2, vertikal | 1x2, 2,54 mm | Connector_PinSocket_2.54mm:PinSocket_1x02_P2.54mm_Vertical |  |  | AnalogInput; AnalogHydroPressure | J3; AnalogHydroPressure J3 | KiCad | Legacy |  | BUCHSENLEISTE 1X2, VERTIKAL|CONNECTOR_PINSOCKET_2.54MM:PINSOCKET_1X02_P2.54MM_VERTICAL | BUCHSENLEISTE 1X2, VERTIKAL|CONNECTOR_PINSOCKET_2.54MM:PINSOCKET_1X02_P2.54MM_VERTICAL
ENP-00032 | Widerstand | Widerstand, Metallschicht, 150 Ohm, 0207, 250 mW, 0,1% | 150 Ω, 0,1 %, ≤25 ppm/K, >0,125 W | Resistor_THT:R_Axial_DIN0207_L6.3mm_D2.5mm_P7.62mm_Horizontal | TE Connectivity Passive Product | YR1B150RCC | AnalogInput; AnalogHydroPressure | R1; AnalogHydroPressure R3 | KiCad; DigiKey, abgerufen 2026-09-07 | OK | 150 Ω, ±0,1 %, 0,25 W, Metallfilm, axial; Gehäuselänge 6,3 mm und vorhandener PCB-Lochabstand 7,62 mm bestätigt passend. | YR1B150RCC | YR1B150RCC
ENP-00033 | Diode | Schnelle Schaltdiode 1N4148W | 1N4148W | Diode_SMD:D_SOD-123 | Diotec | 1N4148W | DuoRelay; Aktuell 29.09.2026: DuoRelay FullSize Bausatz Rev 0.3 | ENK-00002 D1,D2 | KiCad | OK |  | 1N4148W | 1N4148W
ENP-00034 | Steckverbinder | Schraubklemme 1x3, horizontal | 3-polig, 5,08 mm | TerminalBlock_Phoenix:TerminalBlock_Phoenix_MKDS-3-3-5.08_1x03_P5.08mm_Horizontal | Metz Connect | 31101103 | DuoRelay; Aktuell 29.09.2026: DuoRelay FullSize Bausatz Rev 0.3 | ENK-00002 J3,J4 | KiCad | OK | Exakte Hersteller-MPN ergänzen. | Anschlussklemme, 3-pol, Ø 2 mm, RM 5,08 | 31101103
ENP-00035 | Transistor | NPN-Transistor BC817 | BC817 | Package_TO_SOT_SMD:SOT-23_Handsoldering | Diotec | BC817 | DuoRelay; Aktuell 29.09.2026: DuoRelay FullSize Bausatz Rev 0.3 | ENK-00002 Q1,Q2 | KiCad | OK |  | BC817 | BC817
ENP-00036 | Widerstand | Widerstand 1 kΩ SMD | 1 kΩ | Resistor_SMD:R_1206_3216Metric_Pad1.30x1.75mm_HandSolder | Vishay | CRCW12061K00FKEA | DuoRelay; Aktuell 29.09.2026: DuoRelay FullSize Bausatz Rev 0.3; SCT013Head Rev 0.1 | ENK-00002 R1,R2; ENK-00010 R1 | KiCad | OK |  | CRCW12061K00FKEA | CRCW12061K00FKEA
ENP-00037 | Kondensator | Elektrolytkondensator 47 µF radial | 47 µF, 50 V | Capacitor_SMD:CP_Elec_6.3x7.7 | Europe ChemiCon | HHXC500ARA470MHA0G | EnvNodeMini Rev 0.1 | EnvNodeMini Rev 0.1 C1 | KiCad | OK |  | HHXC500ARA470MHA0G | HHXC500ARA470MHA0G
ENP-00038 | Diode | Schottky-Diode STPS3L60S | B360B-13-F | Diode_SMD:D_SMB_Handsoldering | Diodes | STPS3L60S | EnvNodeMini Rev 0.1 | EnvNodeMini Rev 0.1 D1 | KiCad | OK |  | STPS3L60S | STPS3L60S
ENP-00039 | Schutzdiode | TVS-Diode SMBJ24A | 24 V | Diode_SMD:D_SMB_Handsoldering | Littelfuse | SMBJ24A | EnvNodeMini Rev 0.1 | EnvNodeMini Rev 0.1 D2 | KiCad | OK |  | SMBJ24A | SMBJ24A
ENP-00040 | Sicherung | Sicherung 2 A | 2 A | Fuse:Fuse_Littelfuse-NANO2-451_453 | Littelfuse |  | EnvNodeMini Rev 0.1 | EnvNodeMini Rev 0.1 F1 | KiCad | Legacy | Exakte Serie/MPN und Auslösecharakteristik ergänzen. Legacy: eindeutige Ausführung fehlt; keine spekulative Hersteller- oder Lieferantenzuordnung. | SICHERUNG 2 A|FUSE:FUSE_LITTELFUSE-NANO2-451_453 | SICHERUNG 2 A|FUSE:FUSE_LITTELFUSE-NANO2-451_453
ENP-00041 | Steckverbinder | Schraubklemme 1x2, horizontal | 2-polig, 5,00 mm | TerminalBlock_RND:TerminalBlock_RND_205-00001_1x02_P5.00mm_Horizontal | RND | 205-00001 | EnvNodeMini Rev 0.1 | EnvNodeMini Rev 0.1 J3 | KiCad | Legacy |  | 205-00001 | 205-00001
ENP-00042 | DC/DC-Wandler | Schaltreglermodul 5 V | TSR 1-2450 | Converter_DCDC:Converter_DCDC_TRACO_TSR-1_THT | Traco Power | TSR 1-2450 | EnvNodeMini Rev 0.1 | EnvNodeMini Rev 0.1 U3 | KiCad | OK |  | TSR 1-2450 | TSR 1-2450
ENP-00043 | DC/DC-Wandler | Schaltreglermodul 3,3 V | TSR 1-2433 | Converter_DCDC:Converter_DCDC_TRACO_TSR-1_THT | Traco Power | TSR 1-2433 | EnvNodeMini Rev 0.1 | EnvNodeMini Rev 0.1 U4 | KiCad | OK | KiCad-Library-ID basiert auf TSR_1-2450; Wert und tatsächliches Teil prüfen. | TSR 1-2433 | TSR 1-2433
ENP-00044 | Kondensator | Keramikkondensator 10 nF SMD | 10 nF | Capacitor_SMD:C_1206_3216Metric_Pad1.33x1.80mm_HandSolder | Kyocera | 12061C103JAT2A | SolarRadiation; Aktuell 29.09.2026: SolarRadiation Rev 0.1; SCT013Head Rev 0.1 | ENK-00009 C1; ENK-00010 C1 | KiCad | OK |  | 12061C103JAT2A | 12061C103JAT2A
ENP-00045 | Widerstand | Widerstand, Metallschicht, 2 Ohm, 0207, 600 mW, 1 % | 2 Ω, 1 %, 600 mW | Resistor_THT:R_Axial_DIN0207_L6.3mm_D2.5mm_P7.62mm_Horizontal | Yageo | MF0207FTE52-2R | SolarRadiation; Aktuell 29.09.2026: SolarRadiation Rev 0.1 | ENK-00009 R1 | KiCad | OK | Toleranz auf 1 % korrigiert: vorhandene MPN MF0207FTE52-2R und Reichelt METALL 2,00. Frühere Angabe 0,1 % war widersprüchlich. | MF0207FTE52-2R | MF0207FTE52-2R
ENP-00046 | Solarzelle | Solarzelle KXOB25-14X1TF-TR | KXOB25-14X1TF-TR | EnvNode-Footprints:KXOB25-14X1F | ANYSOLAR Ltd | KXOB25-14X1TF-TR | SolarRadiation; Aktuell 29.09.2026: SolarRadiation Rev 0.1 | ENK-00009 SC1 | KiCad; ANYSOLAR; DigiKey-Bestellung 101459961, 2026-09-07 | OK | Dünne 1,2-mm-Variante; elektrisch und hinsichtlich Kontaktflächen kompatibel zur zuvor vorgesehenen KXOB25-14X1F-TB. | KXOB25-14X1TF-TR | KXOB25-14X1TF-TR
ENP-00047 | Sensor-IC | Temperatursensor TMP100 | TMP100 | Package_TO_SOT_SMD:SOT-23-6 | Texas Instruments | TMP100NA/3K | SolarRadiation; Aktuell 29.09.2026: SolarRadiation Rev 0.1 | ENK-00009 U2 | KiCad | OK | Bestellbare SOT-23-6-Variante: DigiKey Gurtabschnitt 296-26833-1-ND. | TMP100NA/3K | TMP100NA/3K
ENP-00048 | PCB | EnvNode Mainboard PCB | Revision 0.2 | PCB: EnvNode.kicad_pcb | JLCPCB |  | EnvNode |  | KiCad | Legacy | Aktueller KiCad-Stand; Fertiger und konkrete Fertigungsvariante festlegen. | ENVNODE MAINBOARD PCB|PCB: ENVNODE.KICAD_PCB | ENVNODE MAINBOARD PCB|PCB: ENVNODE.KICAD_PCB
ENP-00049 | PCB | EnvNode Mini PCB | Revision 0.1 | PCB: EnvNodeMini.kicad_pcb | JLCPCB |  | EnvNodeMini Rev 0.1 |  | KiCad | Legacy | Legacy-Leiterplatte Revision 0.1; für Revision 0.2 existiert ein eigener Artikel. | ENVNODE MINI PCB|PCB: ENVNODEMINI.KICAD_PCB | ENVNODE MINI PCB|PCB: ENVNODEMINI.KICAD_PCB
ENP-00050 | PCB | AnalogInput HalfSize PCB | Revision 0.1 | PCB: AnalogInput.kicad_pcb | JLCPCB |  | AnalogInput |  | KiCad | Legacy | Fertiger und konkrete Fertigungsvariante festlegen. | ANALOGINPUT HALFSIZE PCB|PCB: ANALOGINPUT.KICAD_PCB | ANALOGINPUT HALFSIZE PCB|PCB: ANALOGINPUT.KICAD_PCB
ENP-00051 | PCB | DuoRelay FullSize PCB Rev 0.1 | Revision 0.1 | PCB: DuoRelay.kicad_pcb | JLCPCB |  | DuoRelay Rev 0.1 |  | KiCad | Legacy | Legacy-Leiterplatte Revision 0.1; der aktuelle KiCad-Stand ist Revision 0.2 und besitzt einen eigenen Artikel. | DUORELAY FULLSIZE PCB REV 0.1|PCB: DUORELAY.KICAD_PCB | DUORELAY FULLSIZE PCB REV 0.1|PCB: DUORELAY.KICAD_PCB
ENP-00052 | PCB | SolarRadiation PCB | Revision 0.1 | PCB: Sensors/SolarRadiation/SolarRadiation.kicad_pcb | JLCPCB |  | SolarRadiation; Aktuell 29.09.2026: SolarRadiation Rev 0.1 | ENK-00009 PCB | KiCad | OK | Fertiger gemäß EnvNode-PCB-Praxis JLCPCB vorgesehen. Angebot, Auftragsnummer und Stückpreis offen. | SOLARRADIATION PCB|PCB: SOLARRADIATION.KICAD_PCB | SOLARRADIATION PCB|PCB: SENSORS/SOLARRADIATION/SOLARRADIATION.KICAD_PCB
ENP-00053 | PCB | RainDetector PCB | Revision 1.0 | PCB: Raindetector.kicad_pcb | JLCPCB |  | RainDetector |  | KiCad | OK | Fertiger und konkrete Fertigungsvariante festlegen. | RAINDETECTOR PCB|PCB: RAINDETECTOR.KICAD_PCB | RAINDETECTOR PCB|PCB: RAINDETECTOR.KICAD_PCB
ENP-00054 | Steckverbinder | Buchsenleiste 2x7, 2,54 mm, vertikal | 2x7, 2,54 mm, THT, vertikal, vergoldet, Bauhöhe 8,5 mm | Connector_PinSocket_2.54mm:PinSocket_2x07_P2.54mm_Vertical | BINDER MPE GMBH | 094-2-014-0-NFX-YS0 | EnvNodeMini Rev 0.2; Aktuell 29.09.2026: EnvNode Mini Bausatz Rev 0.8; EnvNode Weatherstation Bausatz Rev 0.2 | ENK-00001 J1,J2; ENK-00008 J1 | KiCad; Reichelt Produktseite, abgerufen 2026-09-08 | OK | Reichelt MPE 094-2-014: Dual-Buchsenleiste, 14 Kontakte, 2,54 mm, THT, gerade, 3 A/250 V und 8,5 mm Bauhöhe. Footprint-kompatible Beschaffungsalternative zur Würth 61301421821 mit 8,4 mm Bauhöhe. | 094-2-014-0-NFX-YS0
ENP-00055 | Diode | Schottky-Diode SS14, SMA | SS14, 1 A, 40 V, UF max. 0,5 V, IFSM 40 A | Diode_SMD:D_SMA | Vishay | SS14-E3/61T | EnvNodeMini Rev 0.2; ORing Power Rev 0.1; Aktuell 29.09.2026: ORing Power Modul Rev 0.1 | ENK-00007 D1,D2 | KiCad; Vishay; Reichelt, abgerufen 2026-09-01 | OK | Vishay Schottky-Gleichrichter im DO-214AC-/SMA-Gehäuse, 40 V Sperrspannung, 1 A Dauerstrom, 40 A Stoßstrom und Temperaturbereich −65 bis +150 °C. D1 entkoppelt +3V3_EXT, D2 entkoppelt +3V3_DEVKIT; beide speisen mit der Kathode +3V3_SYS. Zwei Stück je EnvNode Mini Rev 0.2. | SS14-E3/61T
ENP-00056 | Kondensator | Elektrolytkondensator 10 µF SMD | 10 µF, ±20 %, 25 V, 85 °C, 2000 h | Capacitor_SMD:CP_Elec_5x5.4 | Panasonic | EEE1EA100SR | EnvNodeMini Rev 0.2; ORing Power Rev 0.1; Aktuell 29.09.2026: ORing Power Modul Rev 0.1 | ENK-00007 C2 | KiCad; Panasonic; Reichelt, abgerufen 2026-09-01 | OK | Panasonic SMD-Aluminium-Elektrolytkondensator, 10 µF ±20 %, 25 V, 85 °C, 2000 h. Abmessungen Ø 5,0 × 5,4 mm passen exakt zum zugewiesenen KiCad-Footprint. C6 liegt zwischen +3V3_SYS und GND; 25 V bieten deutliche Spannungsreserve. Polarität beachten. | EEE1EA100SR
ENP-00057 | PCB | EnvNode Mini PCB Rev 0.2 | Revision 0.2 | PCB: MainBoards/EnvNode Mini/EnvNode Mini.kicad_pcb | JLCPCB |  | EnvNodeMini Rev 0.2 |  | KiCad | OK | Aktueller KiCad-Stand; Fertiger und konkrete Fertigungsvariante festlegen. | ENVNODE MINI PCB REV 0.2|PCB: MAINBOARDS/ENVNODE MINI/ENVNODE MINI.KICAD_PCB
ENP-00058 | Steckverbinder | Stiftleiste 2x7, 2,54 mm, SMD | 2x7, 2,54 mm, SMD, vertikal, vergoldet, 6,0 mm Stecklänge | EnvNode-Footprints:J_Wurth_WR-PHD_61031421121 | Würth Elektronik | 61031421121 | Empty FullSize/HalfSize SMD | J1 | KiCad; Würth Datenblatt; DigiKey, abgerufen 2026-09-01 | OK | Würth WR-PHD SMD-Stiftleiste, 14 Kontakte, 2,54 mm, vergoldet, 3 A/250 V. Exakter Artikel für den Projekt-Footprint J_Wurth_WR-PHD_61031421121. Einzelpreis Gurtabschnitt, Stand 2026-09-01; Preis und Verfügbarkeit vor Bestellung prüfen. | 61031421121
ENP-00059 | Steckverbinder | Stiftleiste 2x7, 2,54 mm, vertikal, Bottom-Mount | 2x7, 2,54 mm, THT, vertikal, vergoldet, 6,1 mm Stecklänge, 3,0 mm Lötstift | EnvNode-Footprints:PinHeader_2x07_P2.54mm_Vertical_Bottom | ECON Connect | SL14G2 | Empty FullSize/HalfSize THT; DuoRelay Rev 0.2; AnalogHydroPressure; Aktuell 29.09.2026: DuoRelay FullSize Bausatz Rev 0.3 | ENK-00002 J1 | KiCad; ECON Connect Datenblatt; Reichelt, abgerufen 2026-09-01 | OK | Standard-THT-Stiftleiste mit 11,6 mm Gesamtlänge, vergoldeten Kontakten und 3 A Nennstrom. Die Bestückung von der Modulunterseite und die dafür passende Pinorientierung werden durch den Projekt-Footprint PinHeader_2x07_P2.54mm_Vertical_Bottom festgelegt. Einzelpreis inkl. MwSt., Stand 2026-09-01; Preis und Verfügbarkeit vor Bestellung prüfen. | STIFTLEISTE 2X7 2,54 MM THT BOTTOM|ENVNODE-FOOTPRINTS:PINHEADER_2X07_P2.54MM_VERTICAL_BOTTOM
ENP-00060 | PCB | Empty FullSize SMD PCB | Revision offen | PCB: Modules/FullSize/Empty-SMD/Empty-SMD.kicad_pcb | JLCPCB |  | Empty FullSize SMD |  | KiCad | OK | Aktueller KiCad-Stand; Revision, Fertiger und konkrete Fertigungsvariante festlegen. | EMPTY FULLSIZE SMD PCB|PCB: MODULES/FULLSIZE/EMPTY-SMD/EMPTY-SMD.KICAD_PCB
ENP-00061 | PCB | Empty FullSize THT PCB | Revision offen | PCB: Modules/FullSize/Empty-THT/Empty-THT.kicad_pcb | JLCPCB |  | Empty FullSize THT |  | KiCad | OK | Aktueller KiCad-Stand; Revision, Fertiger und konkrete Fertigungsvariante festlegen. | EMPTY FULLSIZE THT PCB|PCB: MODULES/FULLSIZE/EMPTY-THT/EMPTY-THT.KICAD_PCB
ENP-00062 | PCB | Empty HalfSize SMD PCB | Revision offen | PCB: Modules/HalfSize/Empty-SMD/Empty-SMD.kicad_pcb | JLCPCB |  | Empty HalfSize SMD |  | KiCad | OK | Aktueller KiCad-Stand; Revision, Fertiger und konkrete Fertigungsvariante festlegen. | EMPTY HALFSIZE SMD PCB|PCB: MODULES/HALFSIZE/EMPTY-SMD/EMPTY-SMD.KICAD_PCB
ENP-00063 | PCB | Empty HalfSize THT PCB | Revision offen | PCB: Modules/HalfSize/Empty-THT/Empty-THT.kicad_pcb | JLCPCB |  | Empty HalfSize THT |  | KiCad | OK | Aktueller KiCad-Stand; Revision, Fertiger und konkrete Fertigungsvariante festlegen. | EMPTY HALFSIZE THT PCB|PCB: MODULES/HALFSIZE/EMPTY-THT/EMPTY-THT.KICAD_PCB
ENP-00064 | LED | LED SMD 1206, rot | Hyperrot, 645 nm, 250 mcd, 140°, Vf 2,0–2,5 V, IF max. 30 mA | LED_SMD:LED_1206_3216Metric_Pad1.42x1.75mm_HandSolder | Kingbright | KP-3216SURC | DuoRelay Rev 0.2; Aktuell 29.09.2026: DuoRelay FullSize Bausatz Rev 0.3 | ENK-00002 D3,D4 | KiCad; Kingbright; Reichelt, abgerufen 2026-09-01 | OK | Kingbright SMD-LED im 1206-/3216-Gehäuse, hyperrot, 250 mcd, 140° Abstrahlwinkel, Bauhöhe 1,1 mm. Im DuoRelay liegen D3/D4 über je 1,5 kΩ an +5 V; bei etwa 2 V Vorwärtsspannung fließen rund 2 mA. | KP-3216SURC
ENP-00065 | Widerstand | Widerstand 1,5 kΩ SMD | 1,5 kΩ, 1 %, 0,25 W, 1206 | Resistor_SMD:R_1206_3216Metric_Pad1.30x1.75mm_HandSolder | Vishay | CRCW12061K50FKEA | DuoRelay Rev 0.2; Aktuell 29.09.2026: DuoRelay FullSize Bausatz Rev 0.3 | ENK-00002 R5,R6 | KiCad; Reichelt, abgerufen 2026-09-01 | OK | Exakt passend als Vorwiderstand der Relais-LEDs. Einzelpreis, Stand 2026-09-01; Preis und Verfügbarkeit vor Bestellung prüfen. | 1,5 KOHM|RESISTOR_SMD:R_1206_3216METRIC_PAD1.30X1.75MM_HANDSOLDER
ENP-00066 | PCB | DuoRelay FullSize PCB Rev 0.2 | Revision 0.2 | PCB: Modules/FullSize/DuoRelay/DuoRelay.kicad_pcb | JLCPCB |  | DuoRelay Rev 0.2 |  | KiCad | OK | Aktueller KiCad-Stand; Fertiger und konkrete Fertigungsvariante festlegen. | DUORELAY FULLSIZE PCB REV 0.2|PCB: MODULES/FULLSIZE/DUORELAY/DUORELAY.KICAD_PCB
ENP-00067 | Kondensator | Keramikkondensator 4,7 µF SMD | 4,7 µF, 25 V, X7R, ±10 %, 1206 | Capacitor_SMD:C_1206_3216Metric_Pad1.33x1.80mm_HandSolder | Samsung Electro-Mechanics | CL31B475KAHNNNE | AnalogHydroPressure | C6 | KiCad; Reichelt, abgerufen 2026-09-01 | OK | 25-V-Ausführung übertrifft die geforderten mindestens 10 V. Einzelpreis, Stand 2026-09-01; Preis und Verfügbarkeit vor Bestellung prüfen. | 4,7 UF 10 V|CAPACITOR_SMD:C_1206_3216METRIC_PAD1.33X1.80MM_HANDSOLDER
ENP-00068 | Kondensator | Keramikkondensator 4,7 µF SMD | 4,7 µF, 50 V, X7R, ±10 %, 1210 | Capacitor_SMD:C_1210_3225Metric_Pad1.33x2.70mm_HandSolder | Samsung Electro-Mechanics | CL32B475KBJVPNE | AnalogHydroPressure | C9 | KiCad; Reichelt, abgerufen 2026-09-01 | OK | Passende 50-V-/1210-Ausführung für den Ausgang des 24-V-Boosters. Einzelpreis, Stand 2026-09-01; Preis und Verfügbarkeit vor Bestellung prüfen. | 4,7 UF 50 V|CAPACITOR_SMD:C_1210_3225METRIC_PAD1.33X2.70MM_HANDSOLDER
ENP-00069 | Diode | Schottky-Diode SMD | Typ und elektrische Daten offen | Diode_SMD:D_SOD-323F |  |  | AnalogHydroPressure Rev 0.2–0.3 | D3 | KiCad | Legacy | Historischer, elektrisch nicht ausreichend spezifizierter SOD-323F-Artikel. In AnalogHydroPressure Rev. 0.4 durch ENP-00106 ersetzt. Legacy: eindeutige Ausführung fehlt; keine spekulative Hersteller- oder Lieferantenzuordnung. | SCHOTTKY|DIODE_SMD:D_SOD-323F
ENP-00070 | Induktivität | Leistungsinduktivität 0,68 µH | 0,68 µH, 11,7 A, DCR 9,2 mΩ, WE-MAPI 4020HT | Inductor_SMD:L_Wuerth_MAPI-3012 | Würth Elektronik | 744383560068HT | AnalogHydroPressure | L1 | KiCad; Würth; DigiKey-Bestellung 101459961, 2026-09-07 | OK | Bestellte HT-Ausführung: 680 nH, 11,7 A, DCR 9,2 mΩ. Ersetzt die zuvor vorgesehene 744383560068. | 0,68 UH|INDUCTOR_SMD:L_WUERTH_MAPI-3012
ENP-00071 | Widerstand | Widerstand 1 MΩ SMD | 1 MΩ, 1 %, 0,25 W, 1206 | Resistor_SMD:R_1206_3216Metric_Pad1.30x1.75mm_HandSolder | Vishay | CRCW12061M00FKEA | AnalogHydroPressure | R5 | KiCad; Reichelt, abgerufen 2026-09-01 | OK | Elektrisch und mechanisch passend. Einzelpreis, Stand 2026-09-01; Preis und Verfügbarkeit vor Bestellung prüfen. | 1 MOHM 1%|RESISTOR_SMD:R_1206_3216METRIC_PAD1.30X1.75MM_HANDSOLDER
ENP-00072 | Widerstand | Widerstand 71,5 kΩ SMD | 71,5 kΩ, 1 %, 0,25 W, 1206 | Resistor_SMD:R_1206_3216Metric_Pad1.30x1.75mm_HandSolder | Yageo | RC1206FR-0771K5L | AnalogHydroPressure | R6 | KiCad; DigiKey, abgerufen 2026-09-01 | OK | Exakter Wert für den Feedback-Widerstand; DigiKey-Bestellnummer auf der Produktseite vor Bestellung ergänzen. Einzelpreis, Stand 2026-09-01; Preis und Verfügbarkeit vor Bestellung prüfen. | 71,5 KOHM 1%|RESISTOR_SMD:R_1206_3216METRIC_PAD1.30X1.75MM_HANDSOLDER
ENP-00073 | Widerstand | Widerstand 220 kΩ SMD | 220 kΩ, 1 %, 0,25 W, 1206 | Resistor_SMD:R_1206_3216Metric_Pad1.30x1.75mm_HandSolder | Vishay Dale | RCV1206220KFKEA | AnalogHydroPressure | R8 | KiCad; DigiKey, abgerufen 2026-09-07 | OK | 220 kΩ, ±1 %, 0,25 W, 1206; DigiKey-Gurtabschnitt. Ersetzt die zuvor bei TME vorgesehene Walsin-Ausführung. | RCV1206220KFKEA
ENP-00074 | Schalter | Schiebeschalter DPDT | DPDT | EnvNode-Footprints:SW_Slide_CK_OS202011MS2QS1 | C&K | OS202011MS2QS1 | AnalogHydroPressure Rev 0.2–0.3 | SW1 | KiCad; C&K Datenblatt; Mouser, abgerufen 2026-09-01 | OK | Historischer DPDT-Schiebeschalter. In AnalogHydroPressure Rev. 0.4 entfallen; die I²C-Buswahl erfolgt über Lötjumper. | OS202011MS2QS1
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

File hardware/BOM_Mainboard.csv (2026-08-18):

Position+A1:D13 | Board | Qty | References | Category | Description | Manufacturer | MPN | Supplier | Supplier_PN | URL | Unit_Price | Total | Quantity Ordered | Notes | VE
1 | EnvNode | 15 |  | Cable Assembly | Set, SET JST-PH 4-polig 2.00mm vertikaler PCB-Stecker, Buchse THT | JST |  | eBay |  | https://www.ebay.de/itm/175537690511?_skw=jst+ph+set&itmmeta=01M0AMR98NFGJV2FS30RR17BQ3 | 1,53 Û | 22,95 Û | 12 | GPIO-AnschlŸsse; exakte Herstellerartikelnummer vor Bestellung gegen Footprint und Orientierung prŸfen | 10
4 | EnvNode | 6 |  | Cable Assembly Set | Qwiic/JST-SH, 4-poliges Pigtail JST | JST |  | eBay |  | https://www.ebay.de/itm/173373182853?var=472082388514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 | 0,67 Û | 4,01 Û | 20 | Qwiic-Konvention: GND=schwarz, 3V3=rot, SDA=blau, SCL=gelb; Kabelbelegung vor Anschluss prŸfen | 10
5 | EnvNode | 2 |  | Socket | PinSocket 1x4, 2.54 mm | fischer Elektronik | 10120946 | reichelt | BKL 10120946 | https://www.reichelt.de/de/de/shop/produkt/buchsenleiste_2_54mm_1x4_gerade-266671 | 0,81 Û | 1,62 Û | 10 | FŸr interne Qwiic-Breakouts; Bauhšhe und AusfŸhrung passend zur Mechanik wŠhlen | 0
6 | EnvNode | 2 |  | Socket | PinSocket 1x19, 2.54mm | fischer Elektronik | BL1.20 G | reichelt | ÊFIS BL1 20 G | https://www.reichelt.de/de/de/shop/produkt/buchsenleiste_2_54mm_1x20_trennbar_vergoldet-283787 | 2,55 Û | 5,10 Û | 5 | FŸr ESP32-DevKitC mit 38 Pins; alternativ eine geeignete 38-Pin-ESP32-Fassung verwenden
7 | EnvNode | 4 | R1 R2 R3 R4 | Resistor | 4.7 kOhm 1% SMD 1206 | Vishay | CRCW12064K70FKEA | reichelt | VIS CRCW12064K7 | https://www.reichelt.de/de/de/shop/produkt/smd-widerstand_1206_4_7_kohm_250_mw_1_-238119 | 0,15 Û | 0,60 Û | 12 | I2C-Pull-ups fŸr die beiden I2C-Busse | 0
8 | EnvNode | 2 |  | Capacitor | 100 nF Keramik SMD | Kyocera | C1206F104K1RACTU | reichelt | KEM X7R1206A100N | https://www.reichelt.de/de/de/shop/produkt/vielschicht_kerko_1206_100_nf_10_x7r_100_v_125_c-207151 | 0,24 Û | 0,48 Û | 10 | Spannungsfestigkeit, Dielektrikum und Bauform vor Bestellung gegen Schaltplan und Footprint prŸfen | 10
9 | EnvNode | 1 |  | Capacitor | 10 uF Keramik SMD | Kyocera AVX | 12063C106KAT2A | reichelt | 12063C106KAT2A | https://www.reichelt.de/de/de/shop/produkt/mlcc_1206_10_f_25_v_-10_x7r-409262 | 0,11 Û | 0,11 Û | 10 | Spannungsfestigkeit, Dielektrikum und Bauform vor Bestellung gegen Schaltplan und Footprint prŸfen | 10
10 | EnvNode | 1 |  | Capacitor | 47 uF 10V Tantal | Kyocera AVX | TAJB476K010RNJ | reichelt | TAJ 3528 47/10 | https://www.reichelt.de/de/de/shop/produkt/smd-tantal_kondensator_47_f_10_v-167014 | 0,29 Û | 0,29 Û | 3 | Polarisiert; Bauform B | 0
11 | EnvNode | 1 |  | Voltage Regulator | LDO 3.3V SOT-223 | Texas Instruments | LM3940IMP-3.3/NOPB | reichelt | ÊLM 3940 IMP-3 | https://www.reichelt.de/de/de/shop/produkt/ldo-spannungsregler_fix_3_3_vout_1_a_sot-223-109407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 | 1,00 Û | 1,00 Û | 1 | Footprint und thermische Auslegung vor BestŸckung prŸfen | 3
12 | EnvNode | 1 |  | Development Board | ESP32-DevKitC | 38 Pin | Espressif Systems |  |  |  | 5,00 Û | 5,00 Û | 5 | Exakte Modulvariante und Pinout vor BestŸckung prŸfen | 3
13 | EnvNode | 1 |  | PCB | EnvNode Mainboard Rev 0.1 | JLCPCB |  | JLCPCB |  |  |  | - Û |  | UnbestŸckte Leiterplatte; SMD-Lštjumper sind PCB-Strukturen und keine Kaufteile
14 | Raindetector | 1 |  | AO3400A | MOSFET, N-Ch 30V 5,7A 0,018R, SOT-23 | Alpha&Omega Semiconductor | AO3400A | reichelt | AO3400A | https://www.reichelt.de/de/de/shop/produkt/mosfet_n-ch_30v_5_7a_0_018r_sot-23-166490 | 0,18 Û | 0,18 Û | 5
16 | Sensor | 1 |  | Sensor | Arduino - Temperatur- & Feuchtigkeitssensor, SHTC3 | Soldered | 333032 | reichelt | DEBO SENS SHTC3 | https://www.reichelt.de/de/de/shop/produkt/arduino_-_temperatur-_feuchtigkeitssensor_shtc3-375947 | 5,30 Û | 5,30 Û | 1
17 | A/D Wandler | 1 |  | Wandler | Entwicklerboards - ADC, 4 Kanal, 16-Bit, ADS1115 | Soldered | 333095 | reichelt | DEBO ADC 16BIT | https://www.reichelt.de/de/de/shop/produkt/entwicklerboards_-_adc_4_kanal_16-bit_ads1115-372499?search=ADS1115 | 8,85 Û | 8,85 Û | 1
18 | Raindetector | 2 |  | Resistor | SMD-Widerstand, 1206, 100 kOhm, 250 mW, 0,1% | Panasonic | ÊERA8AEB104V | reichelt | VISPAN ERA8AEB104V CRCW1206100 | https://www.reichelt.de/de/de/shop/produkt/smd-widerstand_1206_100_kohm_250_mw_0_1_-238081 | 0,83 Û | 1,66 Û | 10
19 | Raindetector | 1 |  | Resistor | SMD-Widerstand, 1206, 100 Ohm, 250 mW, 5% | YAGEO | RC1206JR-07100RL | reichelt | SMD 1/4W 100 | https://www.reichelt.de/de/de/shop/produkt/smd-widerstand_1206_100_ohm_250_mw_5_-18242 | 0,06 Û | 0,06 Û | 50
20 | Raindetector | 1 |  | Resistor | SMD-Widerstand, 1206, 10 kOhm, 250 mW, 0,1% | Panasonic | ÊPAN ERA8ERA8AEB103VAEB103V | reichelt | PAN ERA8AEB103V | https://www.reichelt.de/de/de/shop/produkt/smd-widerstand_1206_10_kohm_250_mw_0_1_-238080 | 0,75 Û | 0,75 Û
21 | Raindetector | 1 |  | Capacitor | 100 nF Keramik SMD | Kyocera | C1206F104K1RACTU | reichelt | KEM X7R1206A100N | https://www.reichelt.de/de/de/shop/produkt/vielschicht_kerko_1206_100_nf_10_x7r_100_v_125_c-207151 | 0,24 Û | 0,24 Û |  | Spannungsfestigkeit, Dielektrikum und Bauform vor Bestellung gegen Schaltplan und Footprint prŸfen
22 | Raindetector | 2 |  | Header | Stiftleiste, 8-polig, Raster 2,54mm | BKL Electronic | 10120505 | reichelt | BKL 10120505 | https://www.reichelt.de/de/de/shop/produkt/stiftleiste_8-polig_raster_2_54mm-235656 | 0,31 Û | 0,62 Û | 20
23 | Raindetector | 1 |  | Timer-IC | Timer-IC, Typ 555, SO-8 | Renesas | ICM7555IBAZ | reichelt | ICM 7555 IBAZ | https://www.reichelt.de/de/de/shop/produkt/timer-ic_typ_555_so-8-188889 | 1,10 Û | 1,10 Û
24 | Detector | 2 |  | Socket | PinSocket 1x8, 2,54mm SMD | fischer Elektronik | BL 3 8 G | reichelt | FIS BL 3 8G | https://www.reichelt.de/de/de/shop/produkt/buchsenleiste_1-reihig_1_x_8_-_2_54_mm-407106 | 1,70 Û | 3,40 Û | 2
25 | Detector | 12 |  | Resistor | Widerstand 47Ohm |  |  |  |  |  |  | - Û | 12

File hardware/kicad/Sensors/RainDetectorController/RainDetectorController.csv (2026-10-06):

Refs | Value | Footprint | Qty | DNP
C1 | 100nF | Capacitor_SMD:C_1206_3216Metric_Pad1.33x1.80mm_HandSolder | 1
J1,J2 | Conn_02x02_Odd_Even | Connector_PinSocket_2.54mm:PinSocket_2x02_P2.54mm_Vertical | 2
J3 | HEATER_CTRL | Connector_PinHeader_2.54mm:PinHeader_1x04_P2.54mm_Vertical | 1 | DNP
J4 | RAIN_SIGNAL | Connector_PinHeader_2.54mm:PinHeader_1x04_P2.54mm_Vertical | 1 | DNP
Q1 | AO3400A | Package_TO_SOT_SMD:SOT-23 | 1
R1 | 100Ohm | Resistor_SMD:R_1206_3216Metric_Pad1.30x1.75mm_HandSolder | 1
R2,R4 | 100kOhm | Resistor_SMD:R_1206_3216Metric_Pad1.30x1.75mm_HandSolder | 2
R3 | 10kOhm | Resistor_SMD:R_1206_3216Metric_Pad1.30x1.75mm_HandSolder | 1
U1 | ICM7555xB | Package_SO:SOIC-8_3.9x4.9mm_P1.27mm | 1

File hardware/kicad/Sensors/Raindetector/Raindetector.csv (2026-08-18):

Reference | Qty | Value | DNP | Exclude from BOM | Exclude from Board | Exclude from Simulation | Exclude from Position Files | Footprint | Datasheet
C1 | 1 | 100nF |  |  |  |  | ${EXCLUDE_FROM_POS_FILES} | Capacitor_SMD:C_1206_3216Metric_Pad1.33x1.80mm_HandSolder
J1 | 1 | DetektorLeft |  |  |  |  | ${EXCLUDE_FROM_POS_FILES} | Connector_PinHeader_2.54mm:PinHeader_1x08_P2.54mm_Vertical
J2 | 1 | DetektorRight |  |  |  |  | ${EXCLUDE_FROM_POS_FILES} | Connector_PinHeader_2.54mm:PinHeader_1x08_P2.54mm_Vertical
J3 | 1 | HEATER_CTRL |  |  |  |  | ${EXCLUDE_FROM_POS_FILES} | Connector_PinSocket_2.54mm:PinSocket_1x04_P2.54mm_Vertical
J4 | 1 | RAIN_SIGNAL |  |  |  |  | ${EXCLUDE_FROM_POS_FILES} | Connector_PinSocket_2.54mm:PinSocket_1x04_P2.54mm_Vertical
Q1 | 1 | A03400A |  |  |  |  | ${EXCLUDE_FROM_POS_FILES} | Package_TO_SOT_SMD:SOT-23
R1 | 1 | 100Ohm |  |  |  |  | ${EXCLUDE_FROM_POS_FILES} | Resistor_SMD:R_1206_3216Metric_Pad1.30x1.75mm_HandSolder
R2,R4 | 2 | 100kOhm |  |  |  |  | ${EXCLUDE_FROM_POS_FILES} | Resistor_SMD:R_1206_3216Metric_Pad1.30x1.75mm_HandSolder
R3 | 1 | 10kOhm |  |  |  |  | ${EXCLUDE_FROM_POS_FILES} | Resistor_SMD:R_1206_3216Metric_Pad1.30x1.75mm_HandSolder
U1 | 1 | ICM7555xB |  |  |  |  | ${EXCLUDE_FROM_POS_FILES} | Package_SO:SOIC-8_3.9x4.9mm_P1.27mm | http://www.intersil.com/content/dam/Intersil/documents/icm7/icm7555-56.pdf

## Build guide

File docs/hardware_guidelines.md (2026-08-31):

# Hardware Design Guidelines

## General

- Hierarchical sheets are used to separate functional blocks.
- Hierarchical pins define explicit interfaces between parent and child sheets.
- Global labels are reserved for intentionally project-wide nets; local labels remain sheet-scoped.
- One functional responsibility per sheet.

## Power

- External supply is 5 V.
- Logic supply is 3.3 V.
- Every IC shall have a local 100 nF decoupling capacitor.

## I²C

- Exactly one effective pull-up resistor pair shall exist per physical I²C bus.
- Pull-ups are nominally 4.7 kΩ unless the electrical bus analysis requires another value.
- Pull-up ownership and placement shall be defined by the system design; modules shall not add pull-ups unless the module interface explicitly permits it.
- Shared bus architecture.

## Analog

- ADS1115 is the common analog front-end.
- Sensor circuits shall not connect directly to the ESP32 ADC.

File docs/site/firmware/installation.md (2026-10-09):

# Firmware bauen und aufspielen

Das reguläre Build-Ziel ist ein klassischer ESP32 mit dem PlatformIO-Environment
`esp32dev`. Andere ESP32-Varianten dürfen nicht ungeprüft mit diesem Image verwendet werden.

## Voraussetzungen

- EnvNode-Repository und PlatformIO, etwa über die PlatformIO-Erweiterung in VS Code.
- Passendes ESP32-DevKit und ein USB-Datenkabel.
- Zum angeschlossenen Mainboard passende Board Identity beziehungsweise Boardkonfiguration.

USB-C am ORing-Power-Modul liefert ausschließlich Strom. Zum Programmieren den
USB-Anschluss des ESP32-DevKit verwenden.

## Build

Im Repository unter `firmware/`:

```sh
pio run -e esp32dev
```

Das Anwendungsimage entsteht unter:

```text
firmware/.pio/build/esp32dev/firmware.bin
```

Das Image ist für Web-OTA geeignet. Beim ersten USB-Flash übernimmt PlatformIO
auch die weiteren erforderlichen Flashbestandteile; nicht nur ein OTA-Image
an eine beliebige Flashadresse schreiben.

## USB-Flash

Den tatsächlich angeschlossenen Port ermitteln und einsetzen:

```sh
pio device list
pio run -e esp32dev -t upload --upload-port <PORT>
pio device monitor -p <PORT> -b 115200
```

`<PORT>` durch den angezeigten Gerätenamen ersetzen. Lokal eingetragene Ports
in `platformio.ini` sind rechnerabhängig und kein allgemeiner Standard.

## Nach dem Start

Ohne eingerichtetes WLAN startet die Firmware einen Setup-Access-Point mit dem
Namen `<Hostname>-Setup`. Verbinde dich damit und öffne die Weboberfläche unter
der Geräte-IP, die über die serielle Diagnose ermittelt werden kann.
Nach der Netzwerkeinrichtung wird die zugewiesene WLAN-IP verwendet.

[Weiter zur Einrichtung](configuration.md)

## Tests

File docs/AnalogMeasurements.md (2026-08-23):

# Analog Measurements in EnvNode

## Status and Purpose

This document describes the planned architecture for analog measurements in EnvNode. It records the responsibility boundaries, data flow, and deliberately limited scope of the first implementation.

The first real-world use case is a hydrostatic cistern probe with a 4–20 mA output. Its current signal is converted to a voltage and read by an ADC. The architecture must solve this case cleanly while allowing the ADC to be replaced and individual components to be reused later.

The C++ structures shown here are pseudocode. Names and details may be adapted to existing EnvNode conventions during implementation, provided that the responsibility boundaries described here remain intact.

## Current Implementation Status

Analog-sensor support is implemented and tested in isolation, but not runtime-integrated.

`IAnalogInput`, `AverageAnalogSampler`, two-point calibration, and `AnalogPressureSensor` are implemented and covered by native tests. `AnalogPressureSensor` contains the domain logic for hydrostatic pressure, optional water level, electrical validity boundaries, and the `below_measurement_range` quality classification.

The sensor is not yet integrated into the running EnvNode firmware. No concrete `IAnalogInput` backend exists, the sensor is not registered in `SensorImplementationRegistry` or constructed by `SensorFactory`, and there is no persisted or web-based configuration for it. Consequently, no real analog pressure measurement is currently performed or published at runtime.

ADS1115 integration is intentionally deferred because the required hardware and electrical design are not yet available. ESP32 ADC integration is also deferred until the intended ADC pin, electrical input circuit, voltage range, and validation setup have been decided.

Tank-volume derivation remains future work.

## Motivation

An analog measurement consists of several conceptually different steps:

- A physical sensor produces an electrical signal.
- An ADC captures that signal.
- Individual readings are scheduled and filtered.
- The electrical signal is converted into a physical quantity.
- One or more publishable measurements are produced.
- Additional measurements may be derived from those measurements and further domain knowledge.

Combining all these responsibilities in a single class would unnecessarily couple sensor logic to a particular ADC, filter, tank, or publication schedule. An ADC should not know anything about cisterns, and a pressure sensor should not know the geometry of a tank.

The architecture therefore separates the following layers:

```text
Physical Sensor
      │ electrical signal
      ▼
IAnalogInput
      │ electrical quantity, preferably volts
      ▼
Sampling / Filtering
      │ stabilized electrical value
      ▼
AnalogSensor (V1: AnalogPressureSensor)
      │ physical measurement(s)
      ▼
Measurement
      │
      ▼
Derived Measurement(s)
```

This separation is a conceptual model. It does not necessarily require a separate runtime class for every arrow.

## Terms and Responsibilities

### Physical Sensor

The physical sensor is the actual probe, including its electrical characteristics—for example, a hydrostatic 4–20 mA pressure probe. It exists outside the software but determines the calibration and validity boundaries.

### `IAnalogInput`

`IAnalogInput` abstracts electrical acquisition. It encapsulates ADC-specific details such as the channel, attenuation or gain, reference, resolution, I²C address, and conversion of the raw ADC value where necessary.

Its output is preferably a voltage in volts. A common electrical unit keeps downstream components independent of the resolution and raw-value format of a particular ADC.

`IAnalogInput` explicitly has no sensor semantics. Concepts such as pressure, water level, cistern, or liters do not belong in this layer.

Planned backends include at least:

- `Esp32AnalogInput` for the ESP32 internal ADC
- `Ads1115AnalogInput` for an external ADS1115

### Sampling and Filtering

This layer determines when individual readings are taken and how they are combined into a stabilized value. Sampling must be time-controlled and therefore independent of the incidental execution speed of the main loop.

An arithmetic mean (`Average`) is sufficient for V1. Possible later additions are `Median` and `ExponentialMovingAverage` (`EMA`). The design should allow these additions without introducing a comprehensive filtering framework prematurely.

### `AnalogSensor`

An analog sensor interprets the stabilized electrical quantity in its physical context. V1 deliberately does not introduce a universal, overly generic `AnalogSensor` implementation. Instead, the first real sensor will be a small `AnalogPressureSensor`.

It applies validity checks and two-point calibration and produces:

- `pressure`
- optionally `water_level`, if the required conversion is configured

### `Measurement`

A `Measurement` is a named physical quantity with a value, unit, timestamp, and quality information. It is the result that EnvNode processes or publishes.

### Derived Measurement

A derived measurement is calculated from an existing measurement and additional domain knowledge. Tank volume is therefore not a responsibility of `AnalogPressureSensor`; it is derived from `water_level` and the tank geometry.

A geometric formula is sufficient for simple, symmetrical tanks. A `height -> volume` characteristic curve should be supported later for asymmetrical tanks.

## Data Flow

### General Flow

```text
┌──────────────────────┐
│ Physical Sensor      │
│ e.g. 4–20 mA         │
└──────────┬───────────┘
           │
           ▼
┌──────────────────────┐
│ Signal Conditioning  │
│ current → voltage    │
└──────────┬───────────┘
           │ voltage
           ▼
┌──────────────────────┐
│ IAnalogInput         │
│ ESP32 or ADS1115     │
└──────────┬───────────┘
           │ AnalogSample in volts
           ▼
┌──────────────────────┐
│ Sampling / Filtering │
│ V1: Average          │
└──────────┬───────────┘
           │ FilteredAnalogValue
           ▼
┌──────────────────────┐
│ AnalogPressureSensor │
│ validation +         │
│ calibration          │
└───────┬────────┬─────┘
        │        │
        ▼        ▼
   pressure   water_level (optional)
                    │
                    ▼
            ┌───────────────────┐
            │ TankVolumeDerived │
            │ Measurement       │
            └─────────┬─────────┘
                      ▼
                    volume
```

### Separate Time Intervals

Sampling, filter calculation, and publication are different operations and are configured independently:

```text
Time ─────────────────────────────────────────────────────────►

Sampling:       •  •  •  •  •  •  •  •  •  •  •  •
                   sampleInterval

Filter windows: [────────────][────────────][────────────]
                        filterWindow

Measurement /
Publish:        ▲                         ▲
                └──── measurementInterval ┘
```

- `sampleInterval` determines the frequency of individual ADC reads.
- `filterWindow` determines which samples are evaluated together.
- `measurementInterval` determines when a new domain-level measurement is produced.
- If EnvNode schedules measurement creation and transport separately, an additional `publishInterval` may determine transmission. It must not implicitly control sampling.

For example, the input may be read every 20 ms, averaged over one second, and used to produce or publish a measurement only every 60 seconds.

## Proposed Interfaces and Configuration

### Electrical Input

```cpp
struct AnalogSample {
    float voltage;              // volts
    Timestamp capturedAt;
    bool valid;                 // technical read succeeded
    AnalogInputError error;     // None, NotInitialized, BusError, ...
};

class IAnalogInput {
public:
    virtual ~IAnalogInput() = default;

    virtual bool begin() = 0;
    virtual AnalogSample read() = 0;
    virtual bool initialized() const = 0;
};
```

At this layer, `valid` only indicates whether a technically usable electrical value was read. The domain sensor decides whether that value represents a connected and plausibly operating probe by applying its input boundaries.

Possible backend configurations:

```cpp
struct Esp32AnalogInputConfiguration {
    int gpio;
    AdcAttenuation attenuation;
    AdcResolution resolution;
};

struct Ads1115AnalogInputConfiguration {
    I2cBusId bus;
    uint8_t address;
    Ads1115Channel channel;
    Ads1115Gain gain;
};
```

ADC-specific configuration remains with the respective backend and does not become part of the pressure-sensor configuration.

### Sampling and Filtering

```cpp
enum class AnalogFilterType {
    Average,
    // optional later additions:
    Median,
    ExponentialMovingAverage
};

struct AnalogSamplingConfiguration {
    Duration sampleInterval;
    Duration filterWindow;
    AnalogFilterType filter = AnalogFilterType::Average;
};

struct FilteredAnalogValue {
    float voltage;              // volts
    Timestamp windowStart;
    Timestamp windowEnd;
    size_t acceptedSamples;
    size_t rejectedSamples;
    bool valid;
};
```

For the V1 `Average` filter:

```text
filteredVoltage = sum(valid sample voltages) / numberOfValidSamples
```

The minimum number of technically valid samples and the maximum permitted age of the last filtered value remain to be defined.

### Two-Point Calibration

Calibration linearly maps two electrical reference points to two physical reference points:

```cpp
struct LinearTwoPointCalibration {
    float inputAtMin;           // e.g. volts at 0 bar
    float valueAtMin;           // e.g. 0 bar
    float inputAtMax;           // e.g. volts at 0.5 bar
    float valueAtMax;           // e.g. 0.5 bar
};
```

For an input `x`, the result is:

```text
value = valueAtMin
      + (x - inputAtMin)
      * (valueAtMax - valueAtMin)
      / (inputAtMax - inputAtMin)
```

Configuration must be rejected at startup if `inputAtMin == inputAtMax`. An inverted characteristic can be valid and should not be prohibited without a domain-specific reason.

### Pressure Sensor

```cpp
struct AnalogPressureSensorConfiguration {
    // Electrical boundaries outside which a plausibly connected
    // sensor can no longer be assumed.
    float validInputMinVoltage;
    float validInputMaxVoltage;

    // Electrical-to-physical mapping.
    LinearTwoPointCalibration pressureCalibration;

    // Lower boundary for a reliable physical result.
    float minimumReliablePressure;

    Duration measurementInterval;

    // Optional pressure-to-water-level conversion, e.g. using
    // density and gravitational acceleration.
    optional<HydrostaticLevelConfiguration> waterLevel;
};

class AnalogPressureSensor {
public:
    AnalogPressureSensor(
        IFilteredAnalogValueSource& input,
        AnalogPressureSensorConfiguration configuration);

    vector<Measurement> measure();
};
```

The concrete names for units and measurement metadata will be adapted to the existing EnvNode model during implementation.

### Derived Tank Volume

```cpp
class ITankVolumeModel {
public:
    virtual ~ITankVolumeModel() = default;
    virtual float volumeForHeight(float height) const = 0;
};

struct CylindricalTankGeometry {
    float diameter;
    float usableHeight;
};

struct HeightVolumePoint {
    float height;
    float volume;
};

struct HeightVolumeCurve {
    vector<HeightVolumePoint> points; // interpolation to be defined later
};

class TankVolumeDerivedMeasurement {
public:
    Measurement derive(
        const Measurement& waterLevel,
        const ITankVolumeModel& geometry);
};
```

The derived measurement inherits or degrades the quality of its input measurement. It must never produce a valid volume from an invalid water level.

## Boundaries: Validity, Calibration, and Measurement Range

Three kinds of boundaries must not be conflated.

### `validInputMin` and `validInputMax`

These boundaries apply to the actual electrical input signal. A value outside this range means that no credible sensor signal can be assumed—for example, because of a disconnected probe, broken wire, short circuit, or ADC failure.

Such a value is **invalid**. It must not be extrapolated into an apparently normal pressure value.

### `calibrationMin` and `calibrationMax`

These are the two reference points that map the electrical input to the physical quantity. They define the calibration line, not necessarily the technical validity of the input.

Conceptually, these terms correspond to `inputAtMin`/`valueAtMin` and `inputAtMax`/`valueAtMax` in `LinearTwoPointCalibration`.

An input may therefore lie outside the calibration reference points while remaining inside the technically valid input range. Whether such a value is extrapolated, clamped, or marked as outside the measurement range is a separate domain decision.

### `minimumReliableRange`

This boundary describes the range above which the sensor produces a sufficiently reliable physical result. A connected sensor may produce a technically valid signal below this boundary even though the resulting quantity is below its specified measurement range.

For the pressure sensor, this is initially represented as `minimumReliablePressure`. A later generalization to `minimumReliableRange` must not conflate electrical and physical boundaries.

## Quality and Validity Semantics

Validity and quality express different facts:

- **Validity** answers: Is the measurement technically and logically usable?
- **Quality** answers: What limitation or classification applies to an otherwise usable value?

Proposed semantics:

| Situation | Validity | Quality | Value |
|---|---:|---|---|
| ADC or bus error, or no sample | invalid | `input_error` | no domain value |
| Input below `validInputMin` or above `validInputMax` | invalid | `invalid_input` | no extrapolated domain value |
| Probe connected, but value below its reliable range | valid | `below_measurement_range` | calibrated value or defined boundary value |
| Value within the reliable measurement range | valid | `good` | calibrated value |
| Derived measurement with an invalid source | invalid | `source_invalid` | no derived value |

For the reference use case, this specifically means:

```text
disconnected probe
    → electrical input outside validInputMin/Max
    → measurement invalid / quality invalid_input

connected probe, water level below the specified measurement range
    → electrical input valid
    → measurement valid / quality below_measurement_range
```

This distinction separates “no sensor value is available” from “the sensor reports a very small value that is not sufficiently accurate.”

It remains open whether `valid` should exist as a separate field or be derived entirely from an EnvNode-wide status model. The semantic distinction must be preserved either way.

## Reference Use Case: Hydrostatic Cistern Probe

The first concrete setup consists of:

```text
Water height
   ↓ hydrostatic pressure
4–20 mA pressure probe
   ↓ current
Current-to-voltage converter
   ↓ voltage
ESP32 ADC or ADS1115
   ↓ samples in volts
Average filter
   ↓ stabilized voltage
AnalogPressureSensor
   ├─ pressure
   └─ water_level (optional)
          ↓
TankVolumeDerivedMeasurement + tank geometry
          ↓
       volume
```

The current-to-voltage converter is initially considered part of the physical signal chain. Because `IAnalogInput` returns volts, the pressure calibration contains the voltage reference points actually observed by the ADC. V1 does not require a separate generic current-signal abstraction.

`AnalogPressureSensor` may produce `water_level` in addition to `pressure`, because the hydrostatic conversion is closely related to the interpretation of pressure. The necessary assumptions—such as liquid density and gravitational acceleration, or a simplified conversion factor—must be configured explicitly.

Tank volume remains separate. Two tanks may use the same pressure probe and report the same water level while containing different volumes because their geometries differ.

## Deliberate V1 Scope

V1 consists of small, replaceable components and one real use case:

- an `IAnalogInput`
- at least the ADC backend required first; the other backend follows using the same interface
- deterministic sampling
- an `Average` filter
- two-point calibration
- `AnalogPressureSensor`
- `pressure` and optional `water_level` measurements
- a tank-volume derived measurement separate from the pressure sensor
- explicit validity and quality handling

V1 does not include:

- a universal analog-sensor DSL
- arbitrary calibration curves for every sensor type
- a comprehensive interchangeable filtering framework
- automatic sensor detection
- a generic model for every type of electrical signal
- a characteristic curve for asymmetrical tanks, unless the first real tank immediately requires one

Only a second real analog sensor type should determine which parts truly need to be generalized.

## Open Design Questions

The first `AnalogPressureSensor` implementation resolves several V1 decisions:

- `AverageAnalogSampler` owns time-based acquisition windows and is serviced through the sensor's fast `service()` path.
- A completed window with too few valid samples produces invalid, degraded domain measurements but is still a completed sensor operation.
- Electrically valid inputs are linearly extrapolated outside the calibration reference points without clamping.
- Values below the reliable pressure boundary retain their calibrated value and use `below_measurement_range` quality.
- Each scheduled domain `sample()` publishes the latest completed window, allowing the measurement interval to remain slower than the filter interval.
- Optional water level is calculated directly by `AnalogPressureSensor`; tank volume remains a separate future derived measurement.

The remaining questions are deliberately outside this implementation:

1. **Value age:** Whether a maximum age should be imposed on the latest completed filter window.
2. **Derived measurements:** Which future dependency or transformation mechanism should own tank volume.
3. **Tank characteristic curve:** Which interpolation method and out-of-range behavior a future `height -> volume` curve should use.
4. **Diagnostic data:** Whether raw voltage, sample count, and rejected samples should be exposed as diagnostics.
5. **Configuration integration:** How configuration errors should be reported when this sensor is later added to persistence, factories, and the web UI.

## Remaining Implementation and Hardware Steps

The analog domain foundation, time-controlled average sampler, two-point calibration,
`AnalogPressureSensor`, pressure and optional water-level production, quality propagation, and
their native boundary tests are implemented. The remaining work is deliberately driven by the
real signal chain:

1. Select and implement the backend required first for the cistern setup (`Esp32AnalogInput` or
   `Ads1115AnalogInput`) and test it with known voltages.
2. Add the pressure sensor and backend to persisted configuration, the implementation registry,
   `SensorFactory`, runtime composition, hardware validation, and the Web UI.
3. Validate the complete chain on the real cistern setup and document observed raw voltages,
   disconnected-probe behavior, noise, suitable sample intervals, and filter windows.
4. Implement tank volume as a separate derived measurement, initially for the actual tank
   geometry, when the real installation requires it.
5. Implement the second ADC backend against the same `IAnalogInput` interface to confirm
   interchangeability in practice.
6. Only after adding another analog sensor type, evaluate which components should be generalized
   and whether Median, EMA, or a `height -> volume` characteristic curve is actually required.

## Architecture Decisions at a Glance

- The ADC provides an electrical quantity, preferably volts, and has no sensor semantics.
- ESP32 and ADS1115 are interchangeable backends behind `IAnalogInput`.
- Sampling, filtering, measurement, and publication intervals are independent.
- V1 uses `Average`; Median and EMA remain optional future additions.
- Physical interpretation uses two-point calibration.
- Electrical validity boundaries, calibration reference points, and the reliable measurement range are separate concepts.
- A disconnected probe is invalid; a connected sensor below its measurement range remains valid with quality `below_measurement_range`.
- The first concrete sensor is `AnalogPressureSensor`, not a universal analog-sensor architecture.
- The pressure sensor produces `pressure` and optionally `water_level`.
- Tank volume is a derived measurement based on `water_level` and tank geometry.
- Asymmetrical tanks may later be represented by a `height -> volume` characteristic curve.

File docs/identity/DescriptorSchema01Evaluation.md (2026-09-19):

# EnvNode Hardware Descriptor Schema 0.1 Evaluation

**Status:** Exploratory model; not an EEPROM format decision
**Scope:** EnvNode Mini 0.3, DuoRelay 0.3 and AnalogHydroPressure 0.3

## Artifacts

- [`descriptor-schema-0.1.json`](descriptor-schema-0.1.json) defines the common authoring model.
- [`envnode-mini-0.3.json`](examples/envnode-mini-0.3.json) describes the current two-slot board.
- [`duo-relay-0.3.json`](examples/duo-relay-0.3.json) describes two GPIO-controlled relays.
- [`analog-hydro-pressure-0.3.json`](examples/analog-hydro-pressure-0.3.json) describes the ADS1115-based 4–20 mA input.

The examples deliberately contain an `assessment` member. It records evidence, assumptions and
open questions next to each draft. It is authoring metadata and is excluded from the proposed
EEPROM payload. `$schema` is likewise excluded from the EEPROM payload because `schemaVersion`
identifies the payload schema.

## Schema 0.1 model

The common root separates:

1. manufacturer-controlled type and instance identity;
2. compatibility contracts;
3. human-readable description;
4. board-provided resources or module resource requirements and devices;
5. manufacturing data;
6. calibration records; and
7. authoring-only evidence and uncertainty annotations.

Unknown product type IDs are not rejected merely for being unknown. Compatibility is determined
from the platform and safety contracts, available drivers and capabilities, logical resource
resolution and later occupancy validation.

Module descriptors contain only logical connector resources such as `I2C0`, `AUX_GPIO1` and
`+5V`. Only a board descriptor contains platform bindings such as `gpio:4`. This establishes the
boundary required to resolve the same module against different compatible boards.

Contract and capability identifiers in schema 0.1 are namespaced strings. Their current names are
proposals, not an established registry. Manufacturer-controlled product `typeId` values do not
require central allocation; interoperability contracts still require stable public definitions.

## Size measurement

All sizes are byte counts using UTF-8. `Pretty JSON` is the checked-in authoring file including
`$schema` and `assessment`. `Compact payload JSON` removes those two authoring-only members and
uses JSON without insignificant whitespace. `Deterministic CBOR` encodes that same payload using
RFC 8949 deterministic map-key ordering, ordinary text keys and no application-specific string
dictionary or numeric field tags.

| Descriptor | Pretty JSON | Compact payload JSON | Deterministic CBOR | CBOR reduction from compact JSON |
| --- | ---: | ---: | ---: | ---: |
| EnvNode Mini 0.3 | 7,196 B | 4,415 B | 3,626 B | 17.9% |
| DuoRelay 0.3 | 3,419 B | 1,681 B | 1,415 B | 15.8% |
| AnalogHydroPressure 0.3 | 4,505 B | 1,895 B | 1,618 B | 14.6% |

The measurements describe the draft model, not final records. Envelope bytes, bank metadata,
alignment, manufacturing allocation and calibration growth are not included.

## Consequences for the 4 KiB EEPROM

A single CBOR copy of every example fits in 4 KiB, although the Mini leaves only 470 bytes before
adding an envelope or separately allocated records. Two complete copies do not fit for EnvNode
Mini: two current CBOR payloads alone require 7,252 bytes before envelopes. DuoRelay would require
2,830 bytes and AnalogHydroPressure 3,236 bytes before headers and reserved areas.

Therefore schema 0.1 does not justify adopting two equal full-descriptor banks yet. At least one
of the following must be evaluated first:

- a more compact schema-driven binary mapping using numeric field keys and enumerated common
  contracts;
- removal of derivable or repeated board resource data without losing self-description;
- asymmetric or variable-size banks;
- atomic records or sections rather than complete-image banks; or
- a larger EEPROM for boards whose complete self-description exceeds the dual-bank budget.

Compact JSON already exceeds 4 KiB for the current board example. Plain CBOR
is viable for one copy but its savings are modest because repeated field and contract names remain
text strings. A schema-driven compact CBOR profile should be measured before choosing a custom
binary format.

## Explicit assumptions and unresolved facts

All per-descriptor assumptions are recorded in each file. The most consequential common ones are:

- namespaced product, platform, safety, driver, capability and calibration IDs are proposed;
- the all-zero instance UUIDs are placeholders for manufacturing-provisioned values;
- firmware version `0.5.0` is the current version, not a verified minimum;
- documentation URLs using `example.invalid` are deliberate placeholders;
- no qualified board rail-current budgets are available;
- trust, signature and third-party descriptor approval policy remains open;
- manufacturing values and actual calibration coefficients are unavailable.

For AnalogHydroPressure specifically, address `0x48` and ADS1115 channel 0 are example assumptions.
The board provides address jumpers for `0x48` through `0x4B`, but the assembled jumper selection
has not been established. ADS1115 gain, data rate, input topology, probe range and real calibration
remain open.

For EnvNode Mini, the descriptor intentionally models resources needed to demonstrate discovery
and module binding. It is not yet an agreed exhaustive description of every externally available
ESP32 pin. GPIO capability claims must ultimately be bounded by an approved platform safety
profile.

## Decisions still required

Schema 0.1 is sufficient to compare representations, but not yet to freeze an EEPROM format. The
next decisions are:

1. canonical vocabulary and versioning for platform, safety, driver and capability contracts;
2. whether the board descriptor must enumerate every physical binding or may reference a signed,
   firmware-known platform safety profile for invariant details;
3. compact CBOR key mapping and forward-compatible unknown-field handling;
4. allocation and atomicity for descriptor, manufacturing and calibration data;
5. authenticity and user-approval policy; and
6. representation of hardware assembly options such as the ADS1115 address jumper.

## Follow-up compact-profile measurement

[`CompactCborProfile01.md`](CompactCborProfile01.md) evaluates a schema-driven deterministic CBOR
mapping with numeric field keys, compact known vocabulary and binary UUIDs. With a 32-byte
envelope, the complete examples measure 1742 bytes for EnvNode Mini, 598 bytes for DuoRelay and
911 bytes for AnalogHydroPressure. This makes two complete 2048-byte banks viable in the 4 KiB
EEPROM and is currently preferred over separately banked static and mutable records.

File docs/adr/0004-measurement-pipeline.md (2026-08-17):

# ADR-0004

# Measurement Pipeline

- Status: Accepted
- Date: 2026-08-07

---

## Context

WeatherStation acquires Measurements from physical and simulated Sensors.

Those Measurements are eventually published via MQTT.

Without a clearly defined pipeline, Sensor implementations would become tightly coupled to communication protocols.

This would reduce modularity and make simulation significantly more difficult.

---

## Decision

WeatherStation defines one common Measurement pipeline.

    Sensor
        |
        v
    Measurement
        |
        v
    SensorManager
        |
        v
    MeasurementPublisher
        |
        v
    MqttService
        |
        v
    MQTT Broker

All Measurements follow this pipeline.

Simulation uses exactly the same pipeline.

The acceptance boundary is refined as follows:

    Sensor
        |
        | emits Measurement content
        v
    SensorManager
        |
        | validates structural type/value compatibility
        | assigns source SensorId
        | assigns synchronized Unix Epoch timestamp
        | assigns Sensor provenance
        v
    Completed Measurement
        |
        v
    MeasurementPublisher
        |
        v
    MqttService

Sensors provide physical content, validity and quality.

SensorManager completes Measurements without modifying their physical meaning.

For each Sensor operation, SensorManager establishes a synchronous acceptance context containing the active Sensor and one shared timestamp. It always assigns source from `sensor.id()` and provenance from `sensor.provenance()`.

If system time is not synchronized, emitted content is discarded without forwarding or historical buffering.

It validates only structural consistency, such as:

- MeasurementType ↔ value representation
- valid SensorId
- synchronized timestamp availability

It never performs hardware-specific conversion, calibration or weather interpretation.
Sensor identity belongs to the Sensor. SensorManager copies that identity into the accepted Measurement.

SensorManager does not own hardware-specific conversion, range validation or physical plausibility rules.

Those remain Sensor responsibilities.

---

## Rationale

The pipeline separates domain concepts from communication.

Responsibilities become clearly defined.

Sensor

- hardware interaction
Measurement

- normalized domain representation
- independent of concrete hardware

SensorManager

- sensor orchestration
- periodic scheduling
- event handling
- structural validation
- source, timestamp and provenance assignment

MeasurementPublisher

- serialization
- topic generation

MqttService

- broker connectivity
- transport

One coherent Sensor acquisition may produce multiple Measurements.

Periodic and event-driven Sensors emit through the same output boundary.

Emission through that boundary is synchronous. The receiver consumes or copies each Measurement during the call and never retains the passed reference.

Sensor operation results have explicit emission semantics:

- Completed indicates no hardware or acquisition failure; `sample()` should normally have emitted at least one Measurement.
- NoData indicates normal completion with zero emitted Measurements.
- HardwareFailure indicates an operational failure and permits zero or more Measurements to have been emitted successfully first.

Successfully emitted Measurements are not rolled back. Partial output from a multi-output acquisition is allowed, and one Sensor operation is intentionally not transactional.

Event Measurements such as a rain gauge tip have no value.

Artificial numeric event values are not permitted.

Sensor failure, sensor recovery and hardware communication failure are Diagnostics rather than Measurement Types.

---

## Consequences

Sensor implementations never publish MQTT directly.

MeasurementPublisher becomes the single translation point between domain objects and MQTT.

Changing MQTT payloads or topic structures does not affect Sensor implementations.

Replacing a simulated Sensor with a physical implementation requires no architectural changes.

Sensor acquisition and local operation may continue before time synchronization.

Measurements are not forwarded into the publication pipeline with fake epoch timestamps. Pre-synchronization Measurements may be dropped rather than queued indefinitely.

---

## Alternatives Considered

### Sensors publish MQTT directly

Rejected.

This couples hardware drivers to communication protocols.

Simulation and testing become unnecessarily difficult.

---

### MQTT client inside every Sensor

Rejected.

This duplicates communication logic and violates separation of responsibilities.

---

## Design Rule

Sensors produce Measurements.

Measurements describe physical reality.

Diagnostics describe operational health.

SensorManager validates and completes Measurements without interpreting them.

MeasurementPublisher prepares communication.

MqttService performs communication.

## Implementation evolution (2026-08-17)

The accepted-Measurement boundary now fans out synchronously to both `MeasurementPublisher` and bounded `MeasurementSnapshotCache`. The cache stores only the latest copied snapshot per `SensorId + MeasurementType`, including monotonic acceptance time and revision identity. `IMeasurementResolver` exposes those copies to Measurement-driven Controllers without changing MQTT's role or introducing history storage or an event bus.

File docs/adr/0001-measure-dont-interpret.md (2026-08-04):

# ADR-0001: Measure, Don't Interpret

## Status

Accepted

## Context

Traditional weather stations often combine sensor acquisition, aggregation, statistics and interpretation inside the device firmware.

This creates several problems:

- algorithms are difficult to inspect or replace
- firmware becomes increasingly complex
- calculation errors can invalidate otherwise correct measurements
- historical interpretation cannot easily be recalculated
- the device becomes tightly coupled to one use case

WeatherStation is intended to serve multiple automation and analysis systems.

Therefore the boundary between measurement and interpretation must be explicit.

## Decision

WeatherStation firmware shall primarily publish raw or hardware-near physical measurements.

Higher-level interpretation and aggregation shall be performed outside the device.

Examples of values that belong inside the firmware:

- temperature
- relative humidity
- station pressure
- solar irradiance
- rain detector state
- rain detector raw measurement
- rain gauge tip events
- sensor temperature
- hardware heater output

Examples of values that belong outside the firmware:

- rainfall today
- rainfall yesterday
- rainfall per hour
- sunshine duration
- pressure trend
- daily solar energy
- evapotranspiration
- irrigation decisions

Hardware-related conversion and compensation remain part of the firmware when required to obtain a meaningful physical measurement.

## Consequences

### Positive

- simpler firmware
- easier testing
- easier sensor replacement
- transparent algorithms
- historical values can be recalculated
- fewer dependencies between measurement and application logic
- easier reuse outside Home Assistant

### Negative

- an external system is required for aggregation and interpretation
- some values commonly provided by weather stations are not directly available from the device
- downstream software must implement its own persistence and statistics

These consequences are accepted because they preserve reliable raw measurements and keep the embedded device maintainable.

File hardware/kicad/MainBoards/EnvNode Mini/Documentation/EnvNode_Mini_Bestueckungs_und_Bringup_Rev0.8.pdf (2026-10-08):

ENVNODE · ENVNODE MINI REV. 0.8

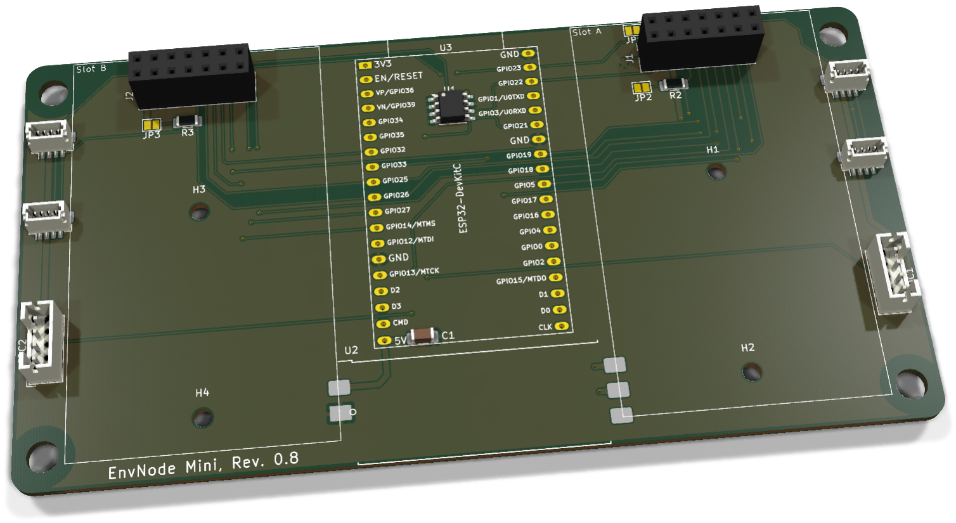
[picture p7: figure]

Bestückungs- und Bring-up-Anleitung · Entwicklungsstand | 1

# ENVNODE MINI

# Bestückungs- und Bring-up-Anleitung

## PLATINE Revision 0.8 DOKUMENTSTAND 29. September 2026 STATUS Entwicklungsstand - Produktionsfreigabe ausstehend

Geltungsbereich: Bestückung, Sichtprüfung und Erstinbetriebnahme des EnvNode Mini Revision 0.8.

Wesentliche Änderungen: Revision 0.7 korrigierte die I2C0-Pinfolge der Modulslots. Revision 0.8 ergänzt zwei vierpolige JST-PH-Anschlüsse für GPIO34/ADC1_CH6 und GPIO35/ADC1_CH7.

# 1. Baugruppen und Teile

## 1.1 Elektronische Bestückung

Ref. | Anz. | Wert / Funktion | Footprint / Hinweis
C1 | 1 | 100 nF, X7R | 1206, Abblockung der +5V-Schiene
R1-R4 | 4 | 4,7 kΩ, 1 % | 1206, I2C-Pull-ups
JP1-JP4 | 4 | Lötjumper, normal offen | I2C-Pull-up-Auswahl
U1 | 1 | 24LC32, Board Identity | SOIC-8, I2C0-Adresse 0x50
U2 | 1 | ORing Power Modul | 39 x 15 mm, castellated Carrier
U3 | 1 | ESP32-DevKitC | 38-polige Ausführung prüfen
J1, J2 | 2 | Modulsockel 2 x 7 | 2,54-mm-Buchsenleiste
J4-J7 | 4 | JST-SH, 4-polig, top-entry | BM04B-SRSS-TB, 1,00 mm
ADC1, ADC2 | 2 | JST-PH, 4-polig, vertikal | B4B-PH-K, 2,00 mm
NT1, NT2 | 2 | Net-Tie | PCB-Struktur; kein Kaufteil

Nicht auf dem Mainboard: Eingangsschutz, 5-V-Eingang, USB und 3,3-V-ORing gehören zum separat dokumentierten ORing-Power-Modul.

## 1.2 Mechanik

Teil | Anz. | Hinweis
EnvNode Mini PCB Rev. 0.8 | 1 | Titelblock und Silkscreen müssen Rev. 0.8 zeigen
H1-H4 | 4 | M2,5-Stützpunkte für Tochterplatinen
H5-H8 | 4 | 4,5-mm-NPTH für BOX4U-Gehäuse

# 2. Bestückungsübersicht

Bereich | Bauteile | Prüfschwerpunkt
Mitte | U3, U1, C1 | DevKit-Ausrichtung, EEPROM Pin 1, Antennenfreiraum
Slot A rechts | J1, R1/R2, JP1/JP2, NT1 | Slot-Adresse, Steckerorientierung
Slot B links | J2, R3/R4, JP3/JP4, NT2 | Slot-Adresse, Steckerorientierung
Außenkanten | J4-J7 | JST-SH MP-Laschen und 1-mm-Pins
Unterkante außen | ADC1, ADC2 | JST-PH, Pin 1 und Kabelbelegung
Unterkante Mitte | U2 | Castellations, Fluchtung und Lötbrücken

Die Referenzen ADC1 und ADC2 bezeichnen die beiden Steckverbinder. Beide Signale gehören intern zum ADC1-Peripherieblock des ESP32: GPIO34 = ADC1_CH6 und GPIO35 = ADC1_CH7.

# 3. Orientierung und Lötreihenfolge

## 3.1 Kritische Orientierung

□ U1: Pin 1 anhand Punkt/Kerbe und PCB-Markierung ausrichten.

□ U3: 38-poliges ESP32-DevKitC ohne Reihenversatz einsetzen; USB-Ende und Antennenseite prüfen.

□ J4-J7: Stecköffnung nach oben; mechanische Pads plan auflegen und vollständig benetzen.

□ ADC1/ADC2: Pin 1 ist GND. Stecköffnung und Kabelbelegung vor dem Verlöten prüfen.

□ U2: Pinfolge und Außenkontur des ORing-Power-Moduls mit dem Carrier-Aufdruck abgleichen.

□ J1/J2: Pin 1, Bestückungsseite und rechtwinklige Ausrichtung kontrollieren.

## 3.2 Empfohlene Reihenfolge

Schritt | Gruppe | Vorgehen
1 | R1-R4, JP1-JP4, NT1/NT2, C1 | Kleine SMD-Teile zuerst; Net-Ties unter Vergrößerung prüfen.
2 | U1 | SOIC-8 ausrichten, einen Pin fixieren, Lage prüfen, fertig löten.
3 | J4-J7 | MP-Pads zuerst fixieren; danach vier Signalpins löten.
4 | ADC1/ADC2 | Plan und rechtwinklig ausrichten; THT-Pins löten.
5 | J1/J2 | Buchsenleisten gerade ausrichten und THT-Pins löten.
6 | U2 | Geprüftes ORing-Power-Modul ausrichten und Castellations verlöten.
7 | U3 | Erst nach passiver und elektrischer Prüfung einsetzen.

# 4. Anschluss- und Adressbelegung

## 4.1 I2C / Qwiic

Stecker | Bus | Pin 1 | Pin 2 | Pin 3 | Pin 4
J4, J5 | I2C0 | GND | +3V3_SYS | SDA | SCL
J6, J7 | I2C1 | GND | +3V3_SYS | SDA | SCL
JP1-JP4 sind ab Werk offen. Für einen Bus beide zugehörigen Jumper nur schließen, wenn das Mainboard die Pull-up-Verantwortung übernehmen soll.

## 4.2 ADC/GPIO-Anschlüsse

Stecker | Pin 1 | Pin 2 | Pin 3 | Pin 4 | ESP32-Signal
ADC1 | GND | +5V | ADC1 | +3V3_SYS | GPIO34 / ADC1_CH6
ADC2 | GND | +5V | ADC2 | +3V3_SYS | GPIO35 / ADC1_CH7

GPIO34 und GPIO35 sind reine Eingänge. Sie können nicht als Digitalausgänge oder PWM-Ausgänge verwendet werden und besitzen keine internen Pull-up-/Pull-down-Widerstände.

Der Signaleingang ist nicht 5-V-tolerant. Pin 2 liefert +5 V ausschließlich zur Sensorversorgung; der
Sensor-Ausgang an Pin 3 muss im zulässigen 3,3-V-Eingangsbereich bleiben. Pin 4 stellt alternativ +3V3_SYS bereit. +5 V und +3V3_SYS dürfen nicht miteinander verbunden werden.

## 4.3 Identität und Modulslots

Funktion | Bus / Adresse | Festlegung
Mainboard U1 | I2C0 / 0x50 | A0=A1=A2=0, WP=GND
Slot A Modul-EEPROM | I2C0 / 0x52 | Pin 3 über NT1 an GND
Slot B Modul-EEPROM | I2C0 / 0x53 | Pin 3 über NT2 an +3V3_SYS
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

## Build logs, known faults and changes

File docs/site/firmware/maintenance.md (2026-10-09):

# Updates und Diagnose

## Web-OTA

1. Ein passendes `firmware.bin` für das ESP32-Ziel bauen.
2. In der Weboberfläche **Firmware** öffnen und das Anwendungsimage hochladen.
3. Upload-Ergebnis prüfen. Ein erfolgreicher Upload stellt das Image bereit,
   startet das Gerät aber noch nicht neu.
4. **Restart Now** wählen oder später gezielt neu starten.
5. Danach Build-Identität, Sensoren, Aktoren und Kommunikation prüfen.

Web-OTA nimmt Anwendungsimages entgegen. Wenn die laufende Firmware keine
funktionierende Aktualisierung ermöglicht, bleibt USB-Flash der Wiederherstellungsweg.

## Diagnose

| Bereich | Kontrolle |
| --- | --- |
| Status | Netzwerk, Laufzeit und Gerätezustand |
| Diagnostics | Boardprofil, Identity, I²C-Scan und Hardware-Ressourcen |
| Measurements | Vorhandene Messgrößen und Sensorzustand |
| Actuators / Controllers | Schaltzustände und lokale Steuerentscheidungen |
| Logs | Ereignisse und Fehlerursachen |
| Firmware | Version, Build-Identität, Git-Stand und bereitgestelltes Update |

Ein I²C-Scan prüft Erreichbarkeit, nicht die richtige Sensorimplementierung.
Fehlende Werte zunächst lokal untersuchen, bevor Broker oder Home Assistant
als Ursache angenommen werden.

## Factory Reset

**Factory reset** löscht alle gespeicherten Konfigurationen und startet in den
Einrichtungsmodus. Vorher Netzwerk-, MQTT- und Hardwareeinstellungen dokumentieren.
Ein normaler Neustart ist der passende erste Schritt, wenn die Konfiguration
beibehalten werden soll.

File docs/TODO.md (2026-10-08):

# TODO

- [x] Controller-Zielauswahl: konfigurierten Aktor-Slot und automatisch erkanntes Modulrelais bei identischer Hardware als einen Eintrag mit Benutzername und Modulzuordnung anzeigen. Auch die exklusive Zielbelegung muss beide Referenzarten als dasselbe Ziel erkennen. Bestehende gespeicherte Referenzen kompatibel halten.

- [ ] In einem separaten Thread eine Benutzerdokumentation der Web-Oberfläche erstellen: Seiten und Felder, Speichern/Anwenden/Neustart, Values und Neustartverhalten, Hysterese/Selector sowie Display-Quellen und Übersetzungen. RainControl als durchgängiges Konfigurationsbeispiel verwenden.

- [ ] Values-Seite: MQTT-Befehlstopic und Beispiel-Payload pro Value anzeigen; Befehl und Statusrückmeldung klar unterscheiden.

- [ ] Display-Geometrien und Grenzfälle später prüfen: unterschiedliche verfügbare Zeilenzahlen, Font-/Zeilenhöhe und Verhalten bei zu langen oder zu vielen Zeilen. Aktuell bleiben beide Displays bei 128×64 mit sechs Zeilen; vorerst keine Erweiterung.

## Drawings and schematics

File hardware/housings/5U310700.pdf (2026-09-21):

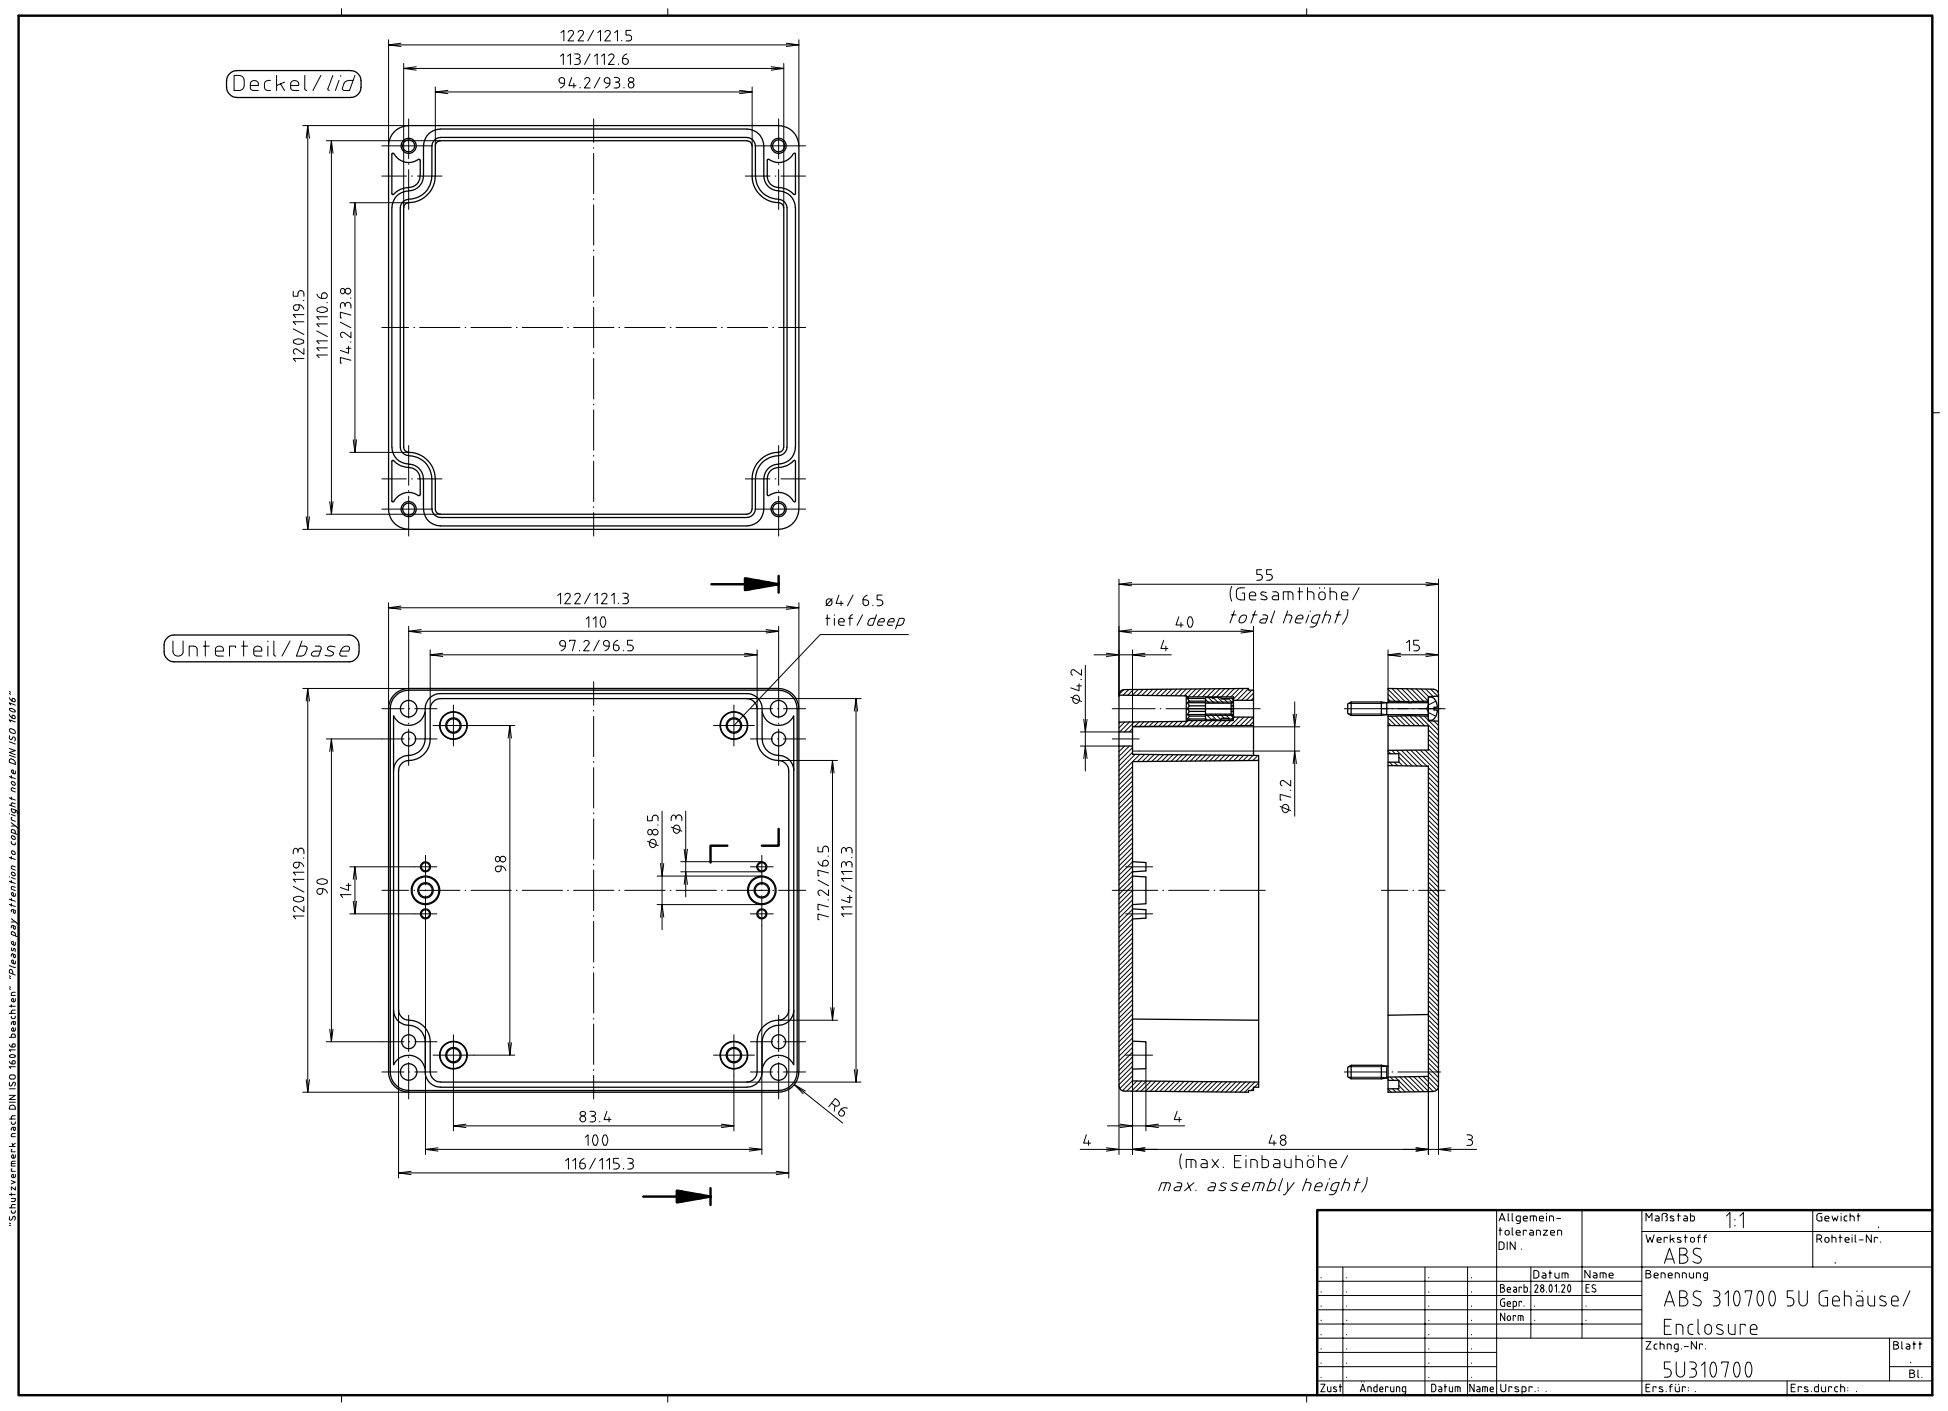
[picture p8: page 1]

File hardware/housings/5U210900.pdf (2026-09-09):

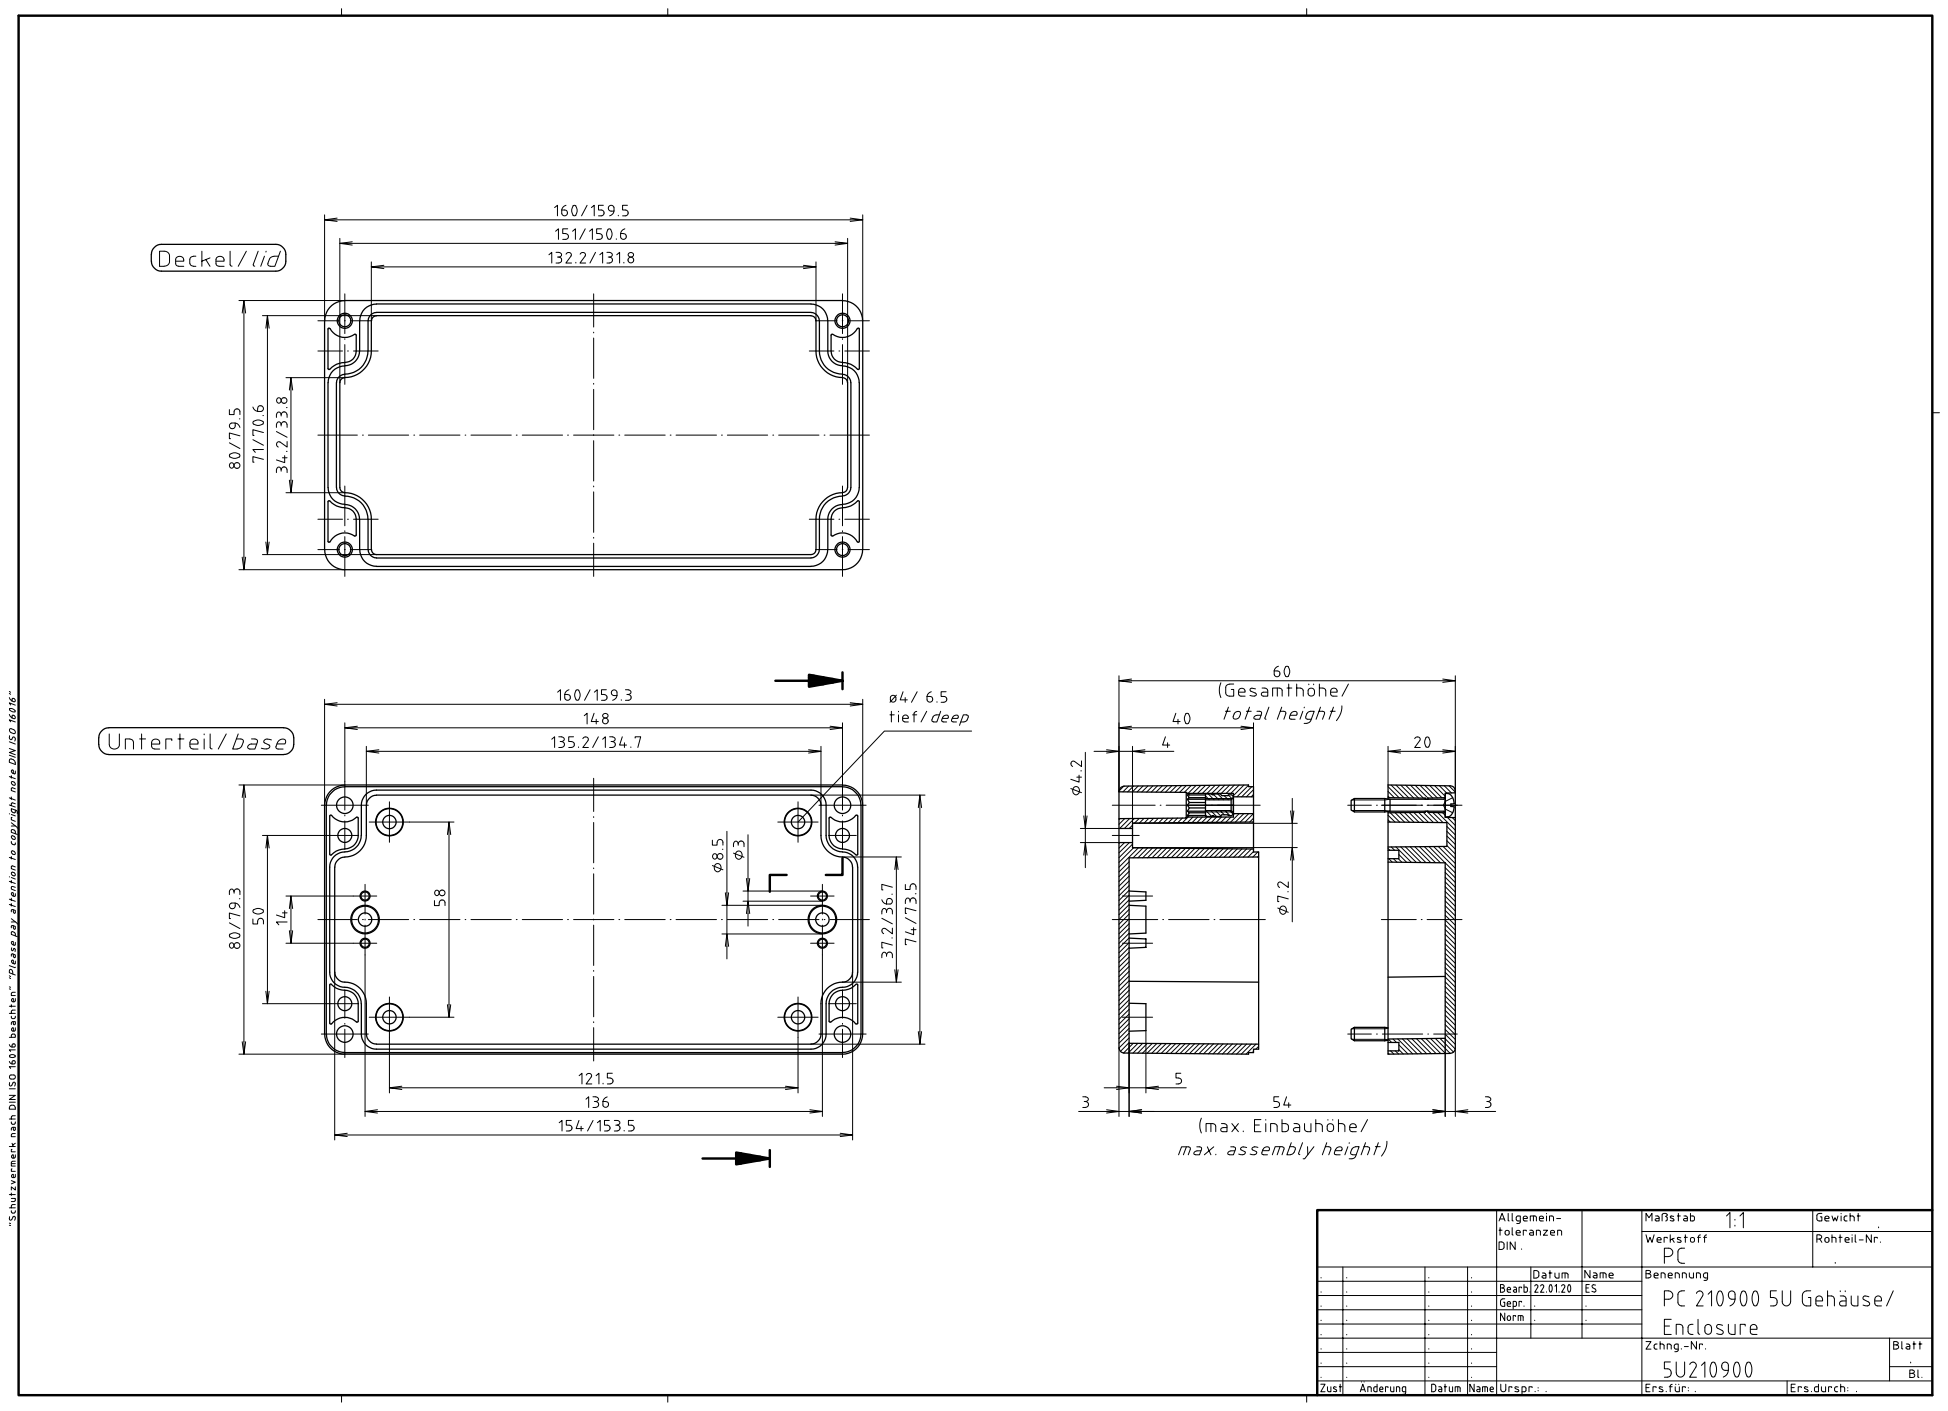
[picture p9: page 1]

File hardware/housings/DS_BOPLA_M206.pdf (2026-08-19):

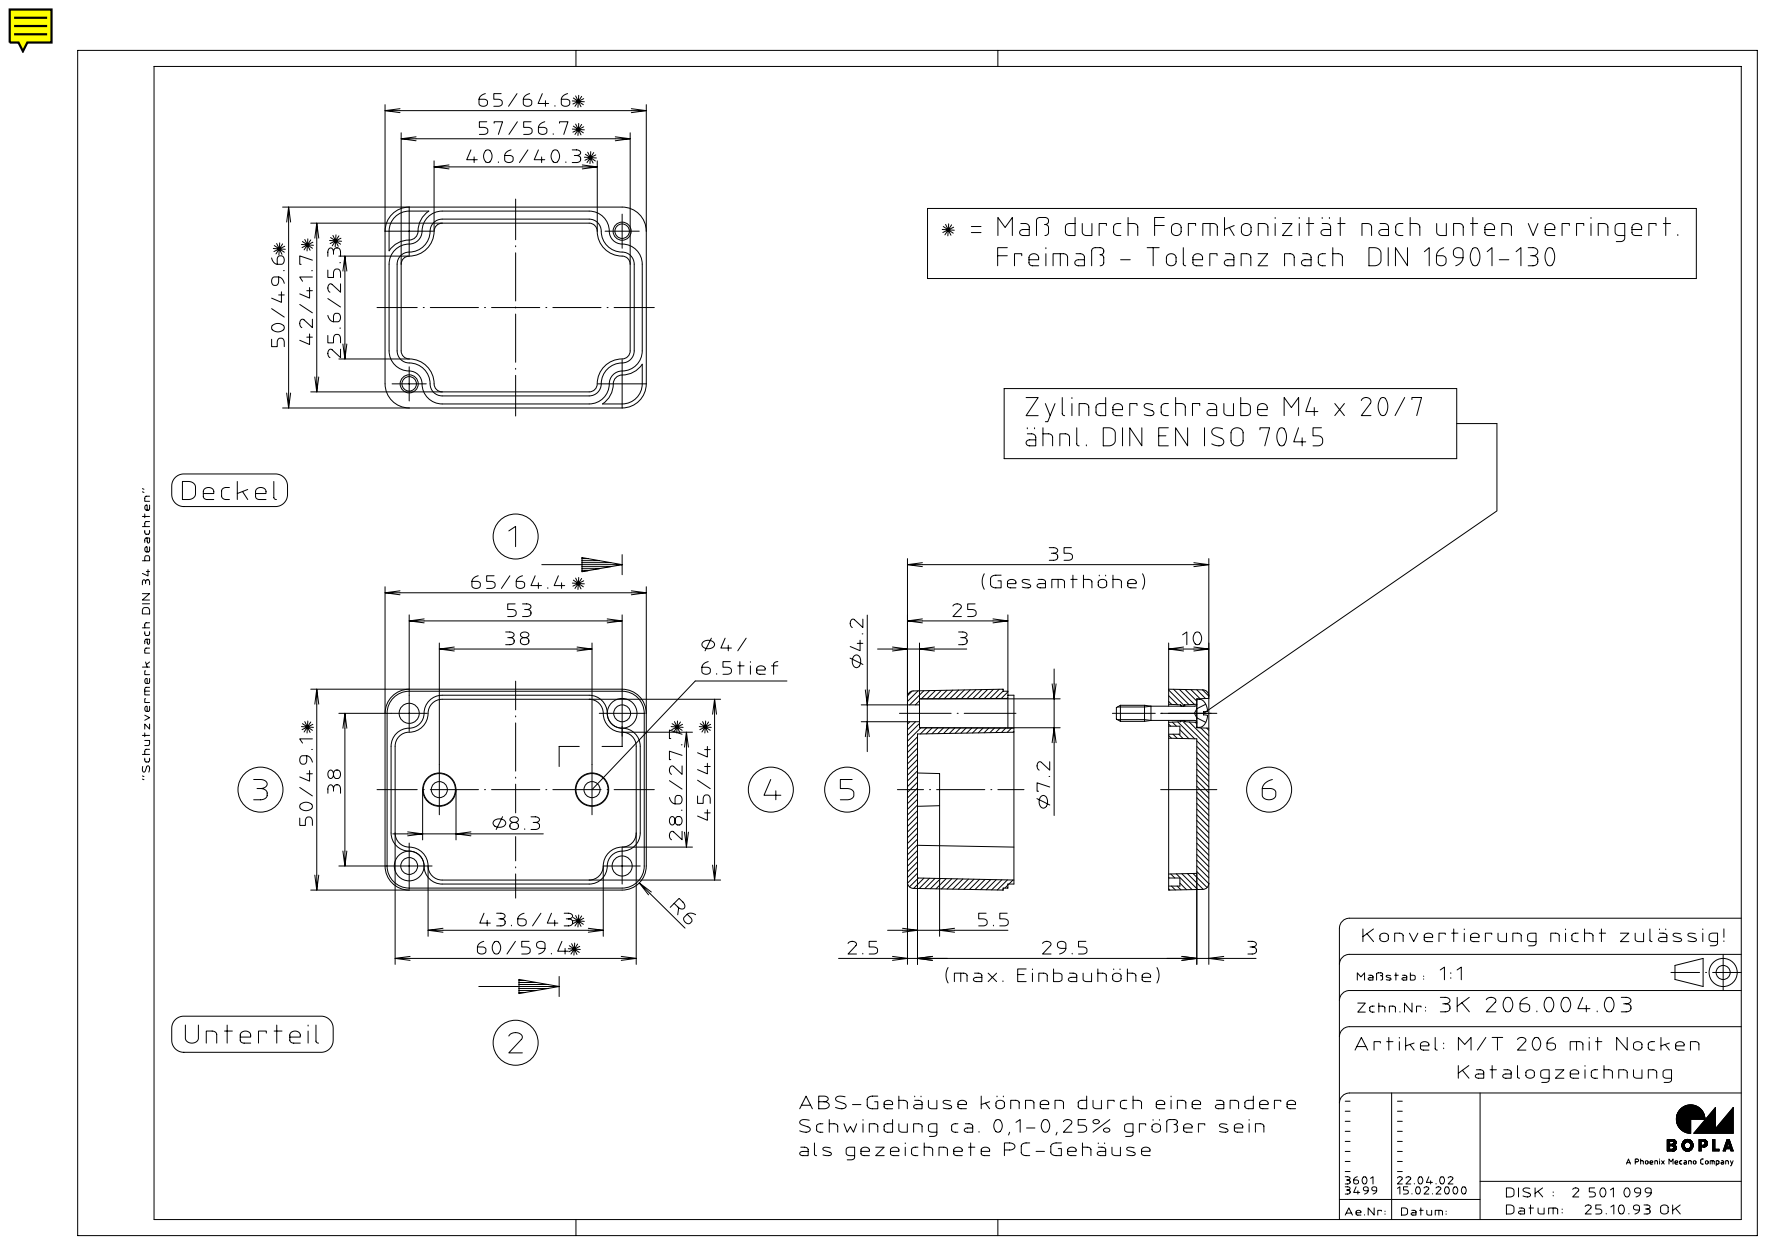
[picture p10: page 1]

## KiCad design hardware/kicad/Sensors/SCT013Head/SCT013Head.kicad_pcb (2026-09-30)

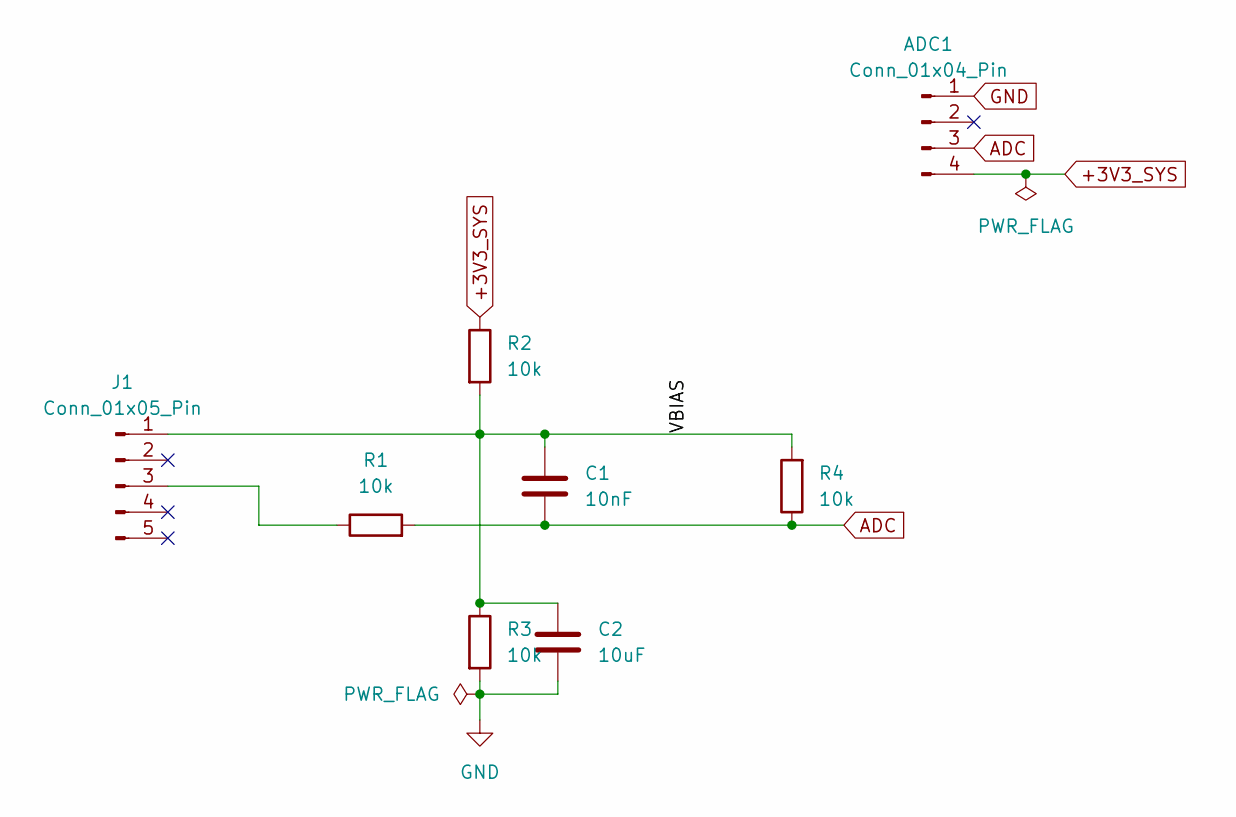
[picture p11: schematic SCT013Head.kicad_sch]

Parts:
ADC1: Conn_01x04_Pin; PinHeader_1x04_P2.54mm_Vertical
C1: 10nF; C_1206_3216Metric_Pad1.33x1.80mm_HandSolder
C2: 10uF; C_1206_3216Metric_Pad1.33x1.80mm_HandSolder
J1: Conn_01x05_Pin; Jack_3.5mm_Lumberg_1503_09_Horizontal
R1, R2, R3, R4: 10k; R_1206_3216Metric_Pad1.30x1.75mm_HandSolder

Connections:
+3V3_SYS: ADC1.4, R2.1
/VBIAS: C1.1, C2.1, J1.1, R2.2, R3.1, R4.2
ADC: ADC1.3, C1.2, R1.2, R4.1
GND: ADC1.1, C2.2, R3.2
unnamed: J1.3, R1.1

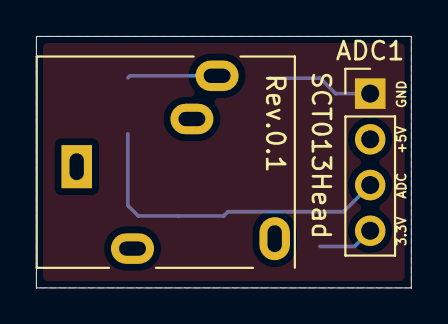
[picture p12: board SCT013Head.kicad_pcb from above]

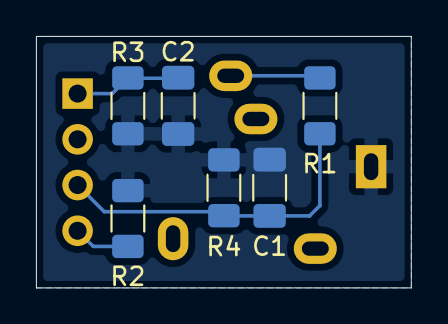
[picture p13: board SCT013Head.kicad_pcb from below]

Board: 2 copper layers, 20.8 x 14.0 mm, 8 parts (6 on the bottom side), 5 nets.

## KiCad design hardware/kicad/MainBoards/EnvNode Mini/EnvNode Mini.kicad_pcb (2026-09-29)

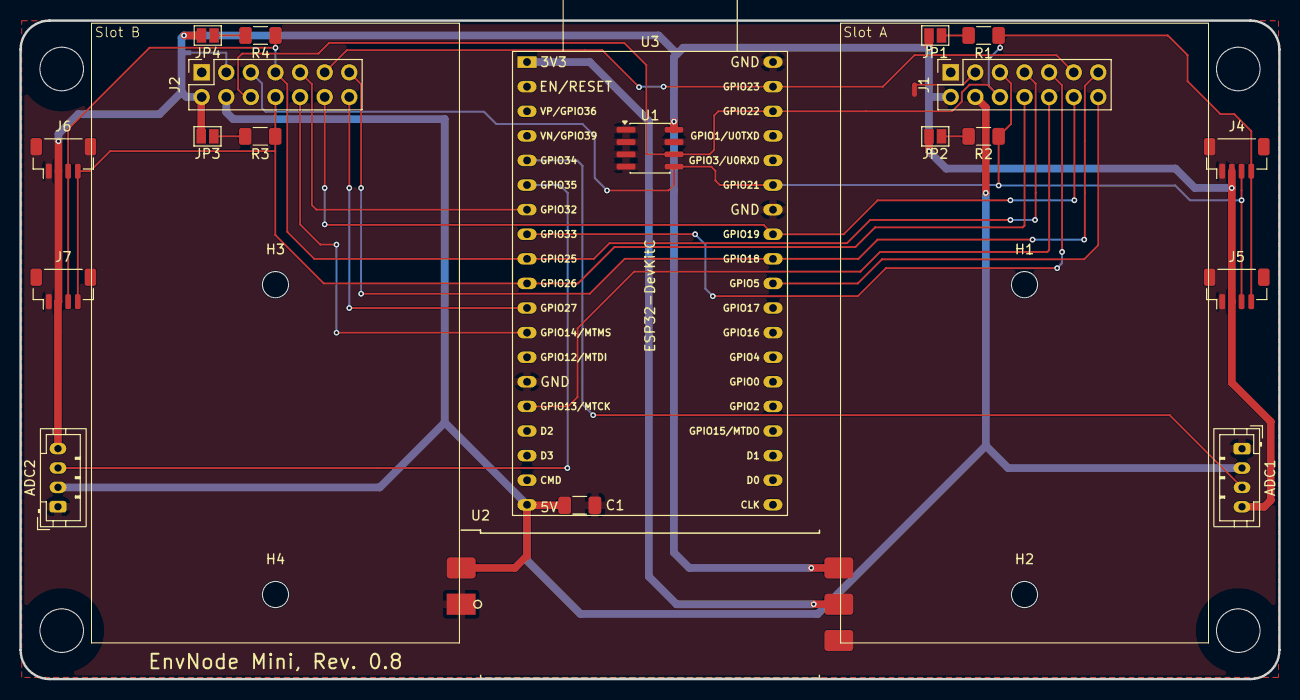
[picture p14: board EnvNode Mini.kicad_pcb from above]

Board: 2 copper layers, 130.0 x 68.0 mm, 30 parts (1 on the bottom side), 25 nets.

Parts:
ADC1, ADC2: Conn_01x04_Pin; JST_PH_B4B-PH-K_1x04_P2.00mm_Vertical
C1: 100nF; C_1206_3216Metric_Pad1.33x1.80mm_HandSolder
H1, H2, H3, H4: MountingHole; MountingHole_2.7mm_M2.5
H5, H6, H7, H8: MountingHole; MountingHole_4.5mm_SelfTapping_4mm
J1, J2: Conn_02x07_Odd_Even; PinSocket_2x07_P2.54mm_Vertical
J4, J5, J6, J7: Conn_01x04_Pin; JST_SH_BM04B-SRSS-TB_1x04-1MP_P1.00mm_Vertical
JP1, JP2, JP3, JP4: Open; SolderJumper-2_P1.3mm_Open_Pad1.0x1.5mm
NT1, NT2: NetTie_2; NetTie-2_SMD_Pad0.5mm
R1, R2, R3, R4: 4,7 kOhm; R_1206_3216Metric_Pad1.30x1.75mm_HandSolder
U1: 24LC32; SOIC-8_3.9x4.9mm_P1.27mm
U2: ORingPower_Module; ORingPower_Carrier
U3: ESP32-DevKitC

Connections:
+3V3_DEVKIT: U2.4 (+3V3_DEVKIT), U3.1 (3V3)
+3V3_SYS: ADC1.4, ADC2.4, J1.2, J2.2, J4.2, J5.2, J6.2, J7.2, JP1.2 (B), JP2.2 (B), JP3.2 (B), JP4.2 (B), NT2.1, U1.8 (VCC), U2.5 (+3V3_SYS)
+5V: ADC1.2, ADC2.2, C1.1, J1.4, J2.4, U2.2 (+5V), U3.19 (5V)
/ADC/ADC1: ADC1.3, U3.5 (VDET_1/GPIO34/ADC1_CH6)
/ADC/ADC2: ADC2.3, U3.6 (VDET_2/GPIO35/ADC1_CH7)
/ESP32Core/CS: J1.14, U3.29 (GPIO5)
/ESP32Core/GPIO13: J1.10, U3.15 (MTCK/GPIO13/ADC2_CH4)
/ESP32Core/GPIO14: J2.10, U3.12 (MTMS/GPIO14/ADC2_CH6)
/ESP32Core/GPIO27: J2.14, U3.11 (ADC2_CH7/GPIO27)
/ESP32Core/GPIO32: J2.9, U3.7 (32K_XP/GPIO32/ADC1_CH4)
/ESP32Core/GPIO33: J1.9, U3.8 (32K_XN/GPIO33/ADC1_CH5)
/ESP32Core/MISO: J1.12, J2.12, U3.31 (GPIO19)
/ESP32Core/MOSI: J1.11, J2.11, U3.37 (GPIO23)
/ESP32Core/SCK: J1.13, J2.13, U3.30 (GPIO18)
EEPROM_A0_A: J1.3, NT1.1
EEPROM_A0_B: J2.3, NT2.2
GND: ADC1.1, ADC2.1, C1.2, J1.1, J2.1, J4.1, J5.1, J6.1, J7.1, NT1.2, U1.1 (A0), U1.2 (A1), U1.3 (A2), U1.4 (GND), U1.7 (WP), U2.1 (GND), U3.14 (GND), U3.32 (GND), U3.38 (GND)
I2C0_SCL: J1.6, J2.6, J4.4, J5.4, R1.1, U1.6 (SCL), U3.36 (GPIO22)
I2C0_SDA: J1.5, J2.5, J4.3, J5.3, R2.1, U1.5 (SDA), U3.33 (GPIO21)
I2C1_SCL: J1.8, J2.8, J6.4, J7.4, R3.1, U3.10 (DAC_2/ADC2_CH9/GPIO26)
I2C1_SDA: J1.7, J2.7, J6.3, J7.3, R4.1, U3.9 (DAC_1/ADC2_CH8/GPIO25)
unnamed: JP1.1 (A), R1.2
unnamed: JP2.1 (A), R2.2
unnamed: JP3.1 (A), R3.2
unnamed: JP4.1 (A), R4.2

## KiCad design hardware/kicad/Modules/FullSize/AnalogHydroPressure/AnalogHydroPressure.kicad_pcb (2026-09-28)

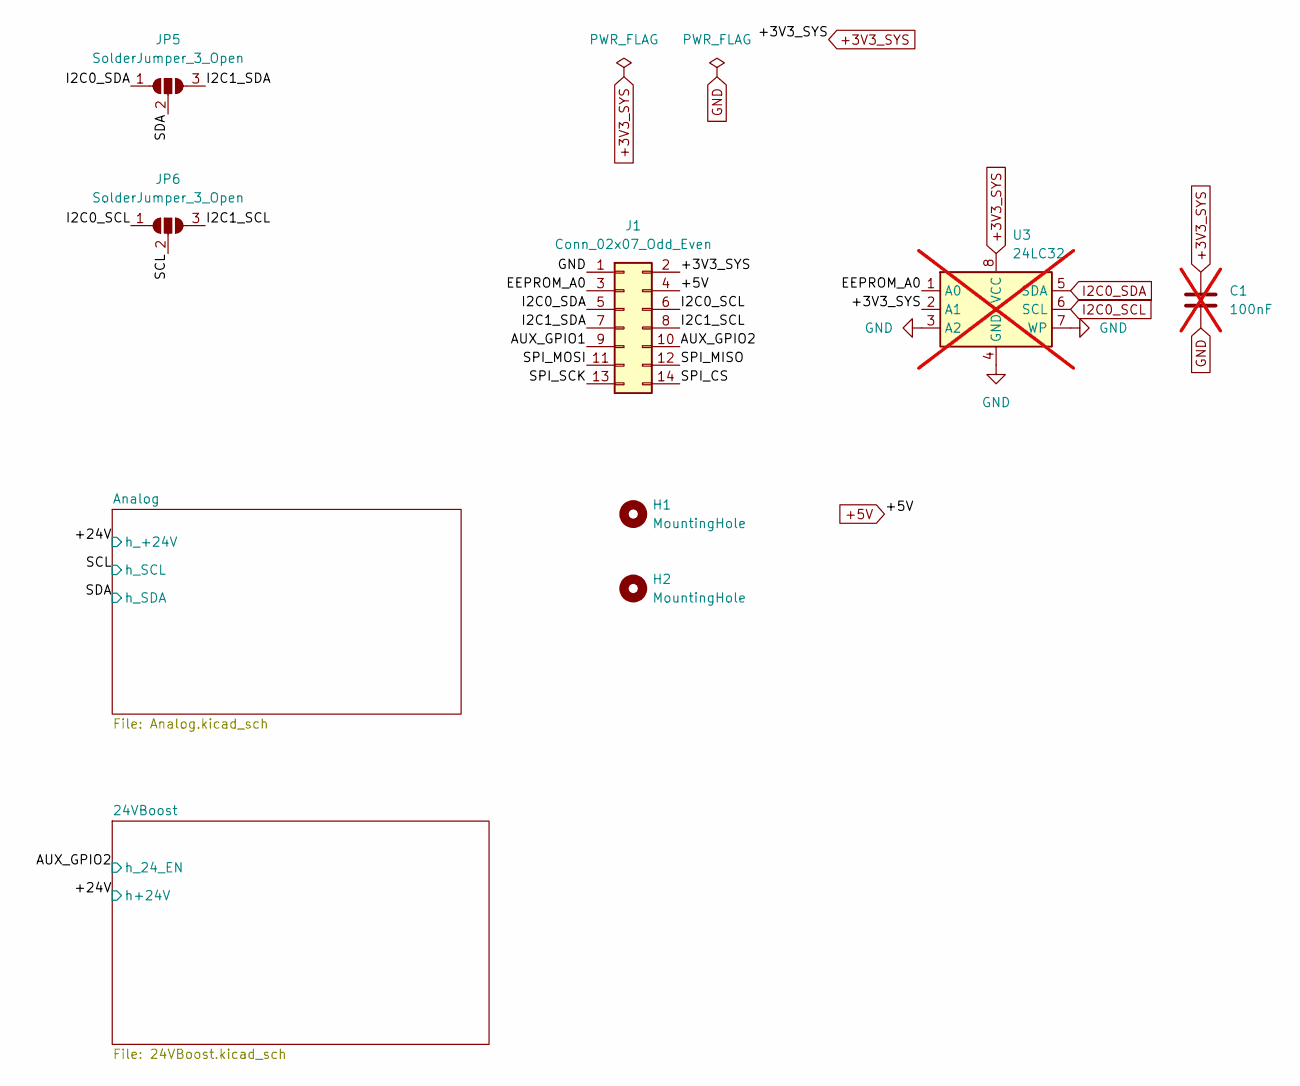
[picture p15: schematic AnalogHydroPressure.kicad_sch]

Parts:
C1: 100nF; C_1206_3216Metric_Pad1.33x1.80mm_HandSolder; not fitted
H1, H2: MountingHole; MountingHole_2.7mm_M2.5_DIN965
J1: Conn_02x07_Odd_Even; PinHeader_2x07_P2.54mm_Vertical_Bottom
JP5, JP6: SolderJumper_3_Open; SolderJumper-3_P1.3mm_Open_RoundedPad1.0x1.5mm_NumberLabels
U3: 24LC32; SOIC-8_3.9x4.9mm_P1.27mm; not fitted

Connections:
+3V3_SYS: C1.1, J1.2, U3.2 (A1), U3.8 (VCC); also elsewhere on the board
+5V: J1.4; also elsewhere on the board
/AUX_GPIO1: J1.9
/AUX_GPIO2: J1.10; also elsewhere on the board
/EEPROM_A0: J1.3, U3.1 (A0)
/I2C1_SCL: J1.8, JP6.3 (B)
/I2C1_SDA: J1.7, JP5.3 (B)
/SCL: JP6.2 (C); also elsewhere on the board
/SDA: JP5.2 (C); also elsewhere on the board
/SPI_CS: J1.14
/SPI_MISO: J1.12
/SPI_MOSI: J1.11
/SPI_SCK: J1.13
GND: C1.2, J1.1, U3.3 (A2), U3.4 (GND), U3.7 (WP); also elsewhere on the board
I2C0_SCL: J1.6, JP6.1 (A), U3.6 (SCL)
I2C0_SDA: J1.5, JP5.1 (A), U3.5 (SDA)

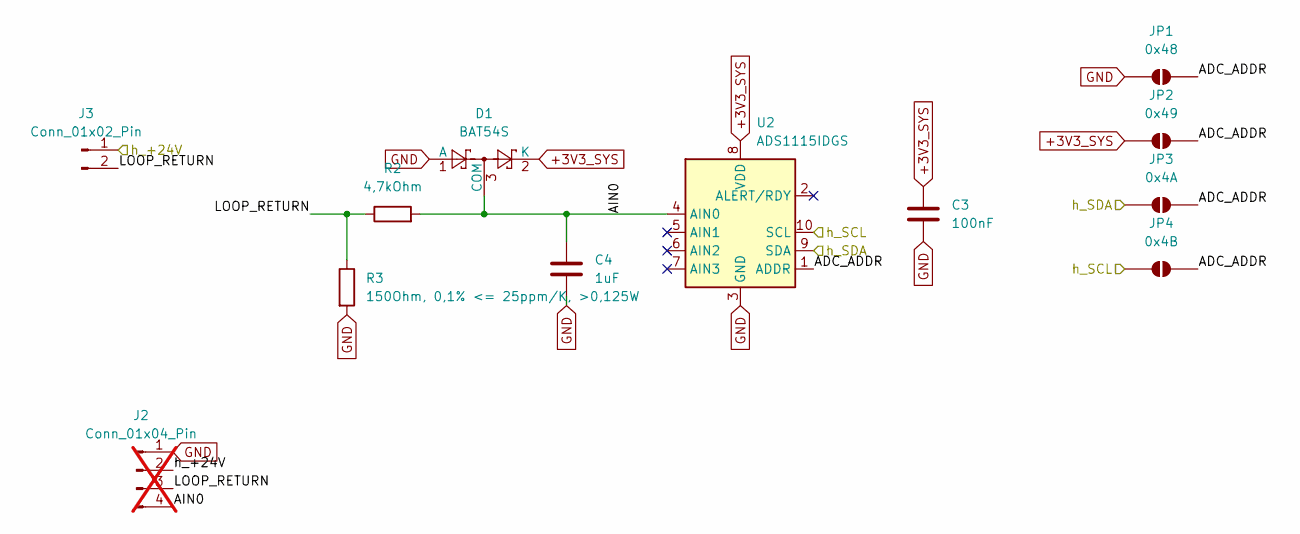
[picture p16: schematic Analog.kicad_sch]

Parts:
C3: 100nF; C_1206_3216Metric_Pad1.33x1.80mm_HandSolder
C4: 1uF; C_1206_3216Metric_Pad1.33x1.80mm_HandSolder
D1: BAT54S; SOT-23
J2: Conn_01x04_Pin; PinHeader_1x04_P2.54mm_Vertical; not fitted
J3: Conn_01x02_Pin; JST_PH_B2B-PH-K_1x02_P2.00mm_Vertical
JP1: 0x48; SolderJumper-2_P1.3mm_Open_Pad1.0x1.5mm
JP2: 0x49; SolderJumper-2_P1.3mm_Open_Pad1.0x1.5mm
JP3: 0x4A; SolderJumper-2_P1.3mm_Open_Pad1.0x1.5mm
JP4: 0x4B; SolderJumper-2_P1.3mm_Open_Pad1.0x1.5mm
R2: 4,7kOhm; R_1206_3216Metric_Pad1.30x1.75mm_HandSolder
R3: 150Ohm, 0,1% <= 25ppm/K, >0,125W; R_Axial_DIN0207_L6.3mm_D2.5mm_P7.62mm_Horizontal
U2: ADS1115IDGS; TSSOP-10_3x3mm_P0.5mm

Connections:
+3V3_SYS: C3.1, D1.2 (K), JP2.1 (A), U2.8 (VDD); also elsewhere on the board
/+24V: J2.2, J3.1; also elsewhere on the board
/Analog/ADC_ADDR: JP1.2 (B), JP2.2 (B), JP3.2 (B), JP4.2 (B), U2.1 (ADDR)
/Analog/AIN0: C4.1, D1.3 (COM), J2.4, R2.2, U2.4 (AIN0)
/Analog/LOOP_RETURN: J2.3, J3.2, R2.1, R3.1
/SCL: JP4.1 (A), U2.10 (SCL); also elsewhere on the board
/SDA: JP3.1 (A), U2.9 (SDA); also elsewhere on the board
GND: C3.2, C4.2, D1.1 (A), J2.1, JP1.1 (A), R3.2, U2.3 (GND); also elsewhere on the board

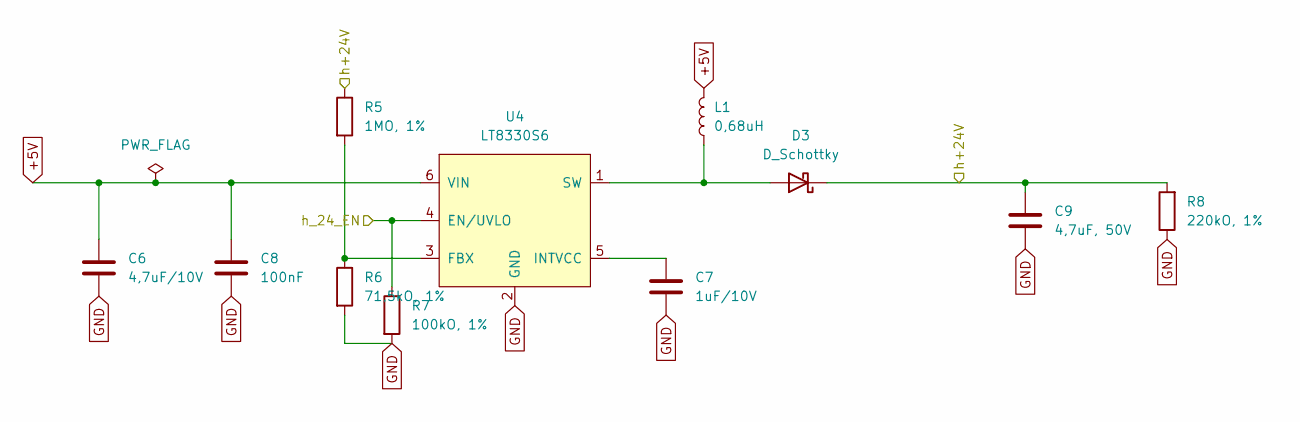
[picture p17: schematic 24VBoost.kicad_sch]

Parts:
C6: 4,7uF/10V; C_1206_3216Metric_Pad1.33x1.80mm_HandSolder
C7: 1uF/10V; C_1206_3216Metric_Pad1.33x1.80mm_HandSolder
C8: 100nF; C_1206_3216Metric_Pad1.33x1.80mm_HandSolder
C9: 4,7uF, 50V; C_1210_3225Metric_Pad1.33x2.70mm_HandSolder
D3: D_Schottky; D_SOD-123F
L1: 0,68uH; L_Wuerth_MAPI-3012
R5: 1MO, 1%; R_1206_3216Metric_Pad1.30x1.75mm_HandSolder
R6: 71,5kO, 1%; R_1206_3216Metric_Pad1.30x1.75mm_HandSolder
R7: 100kO, 1%; R_1206_3216Metric_Pad1.30x1.75mm_HandSolder
R8: 220kO, 1%; R_1206_3216Metric_Pad1.30x1.75mm_HandSolder
U4: LT8330S6; SOT-23-6

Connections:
+5V: C6.1, C8.1, L1.2, U4.6 (VIN); also elsewhere on the board
/+24V: C9.1, D3.1 (K), R5.1, R8.2; also elsewhere on the board
/AUX_GPIO2: R7.1, U4.4 (EN/UVLO); also elsewhere on the board
GND: C6.2, C7.2, C8.2, C9.2, R6.2, R7.2, R8.1, U4.2 (GND); also elsewhere on the board
unnamed: D3.2 (A), L1.1, U4.1 (SW)
unnamed: R5.2, R6.1, U4.3 (FBX)
unnamed: C7.1, U4.5 (INTVCC)

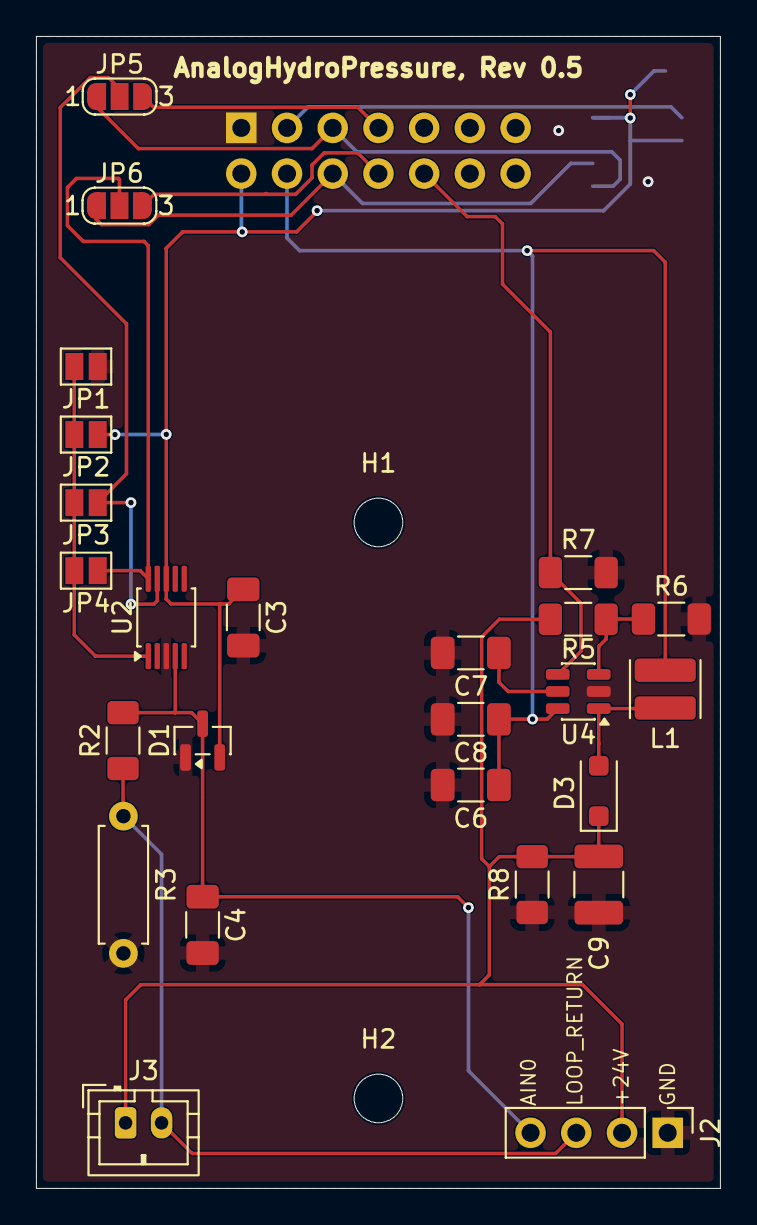
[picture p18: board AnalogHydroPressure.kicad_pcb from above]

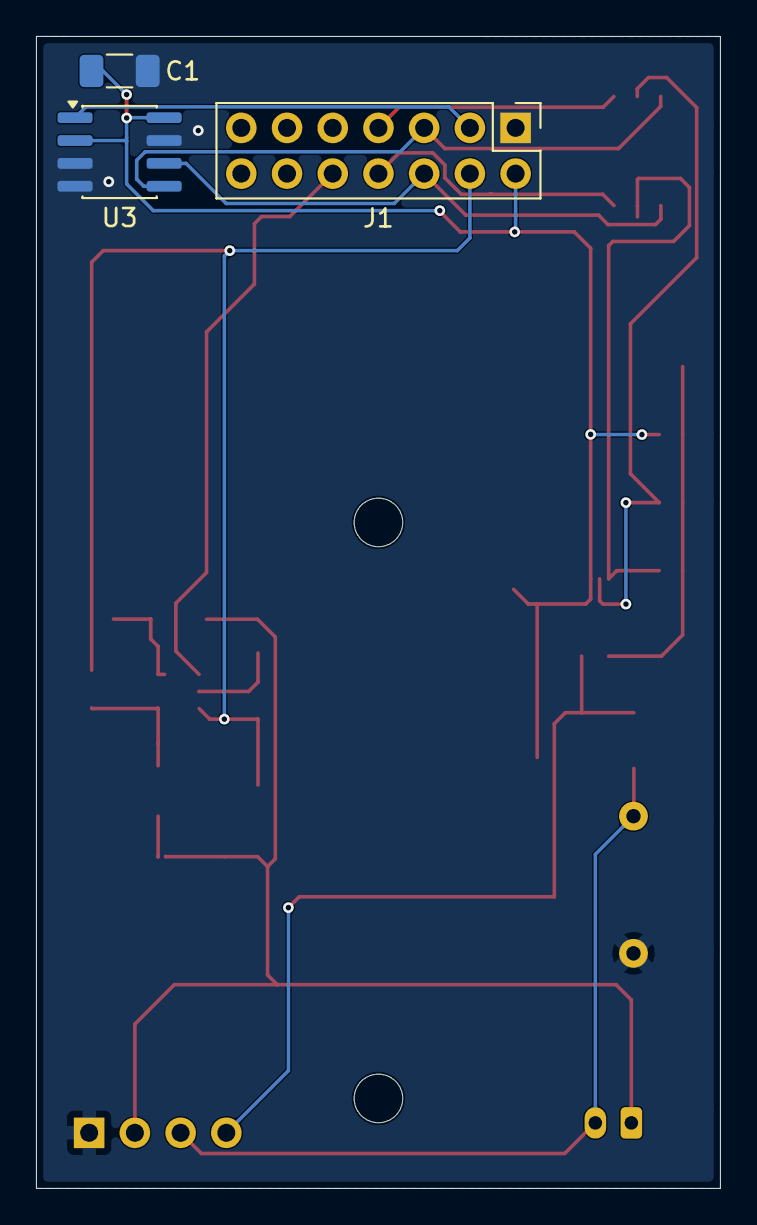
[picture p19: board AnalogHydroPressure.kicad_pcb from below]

Board: 2 copper layers, 38.0 x 64.0 mm, 30 parts (3 on the bottom side), 18 nets.

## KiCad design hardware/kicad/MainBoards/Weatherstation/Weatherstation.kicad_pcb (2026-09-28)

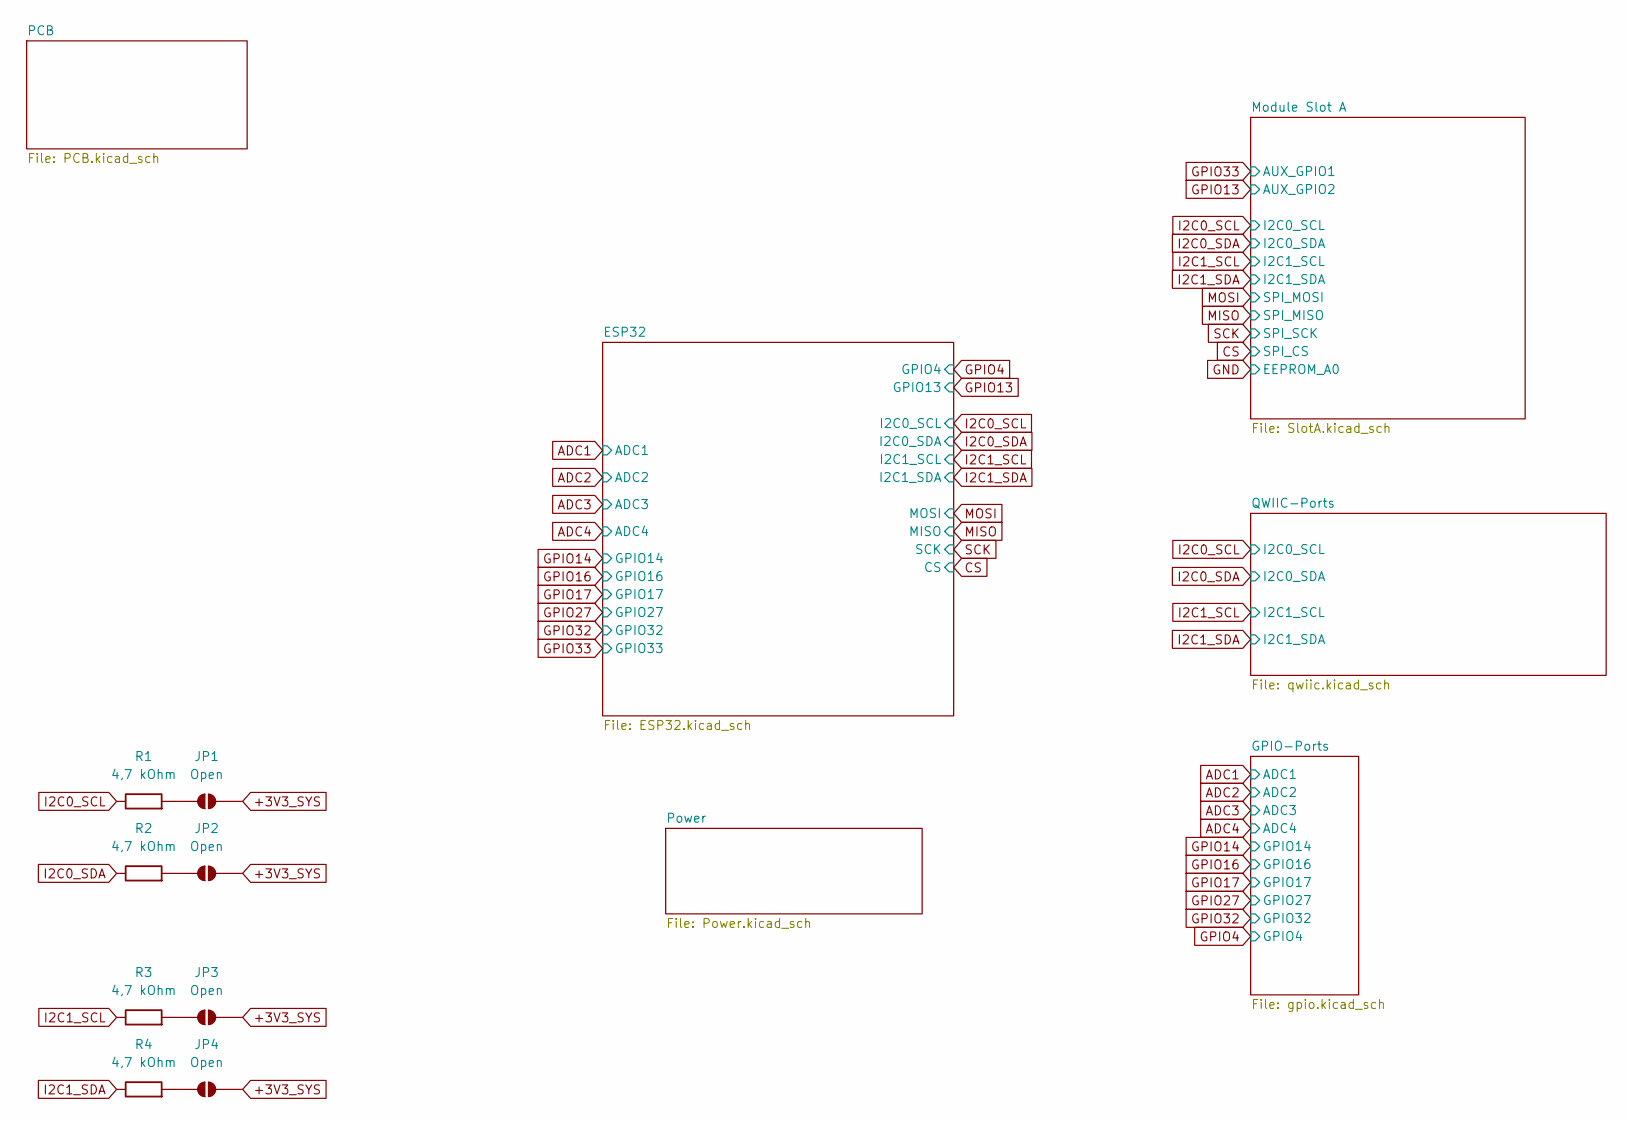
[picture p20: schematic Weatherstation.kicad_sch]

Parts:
JP1, JP2, JP3, JP4: Open; SolderJumper-2_P1.3mm_Open_Pad1.0x1.5mm
R1, R2, R3, R4: 4,7 kOhm; R_1206_3216Metric_Pad1.30x1.75mm_HandSolder

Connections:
+3V3_SYS: JP1.2 (B), JP2.2 (B), JP3.2 (B), JP4.2 (B); also elsewhere on the board
I2C0_SCL: R1.1; also elsewhere on the board
I2C0_SDA: R2.1; also elsewhere on the board
I2C1_SCL: R3.1; also elsewhere on the board
I2C1_SDA: R4.1; also elsewhere on the board
unnamed: JP1.1 (A), R1.2
unnamed: JP2.1 (A), R2.2
unnamed: JP3.1 (A), R3.2
unnamed: JP4.1 (A), R4.2

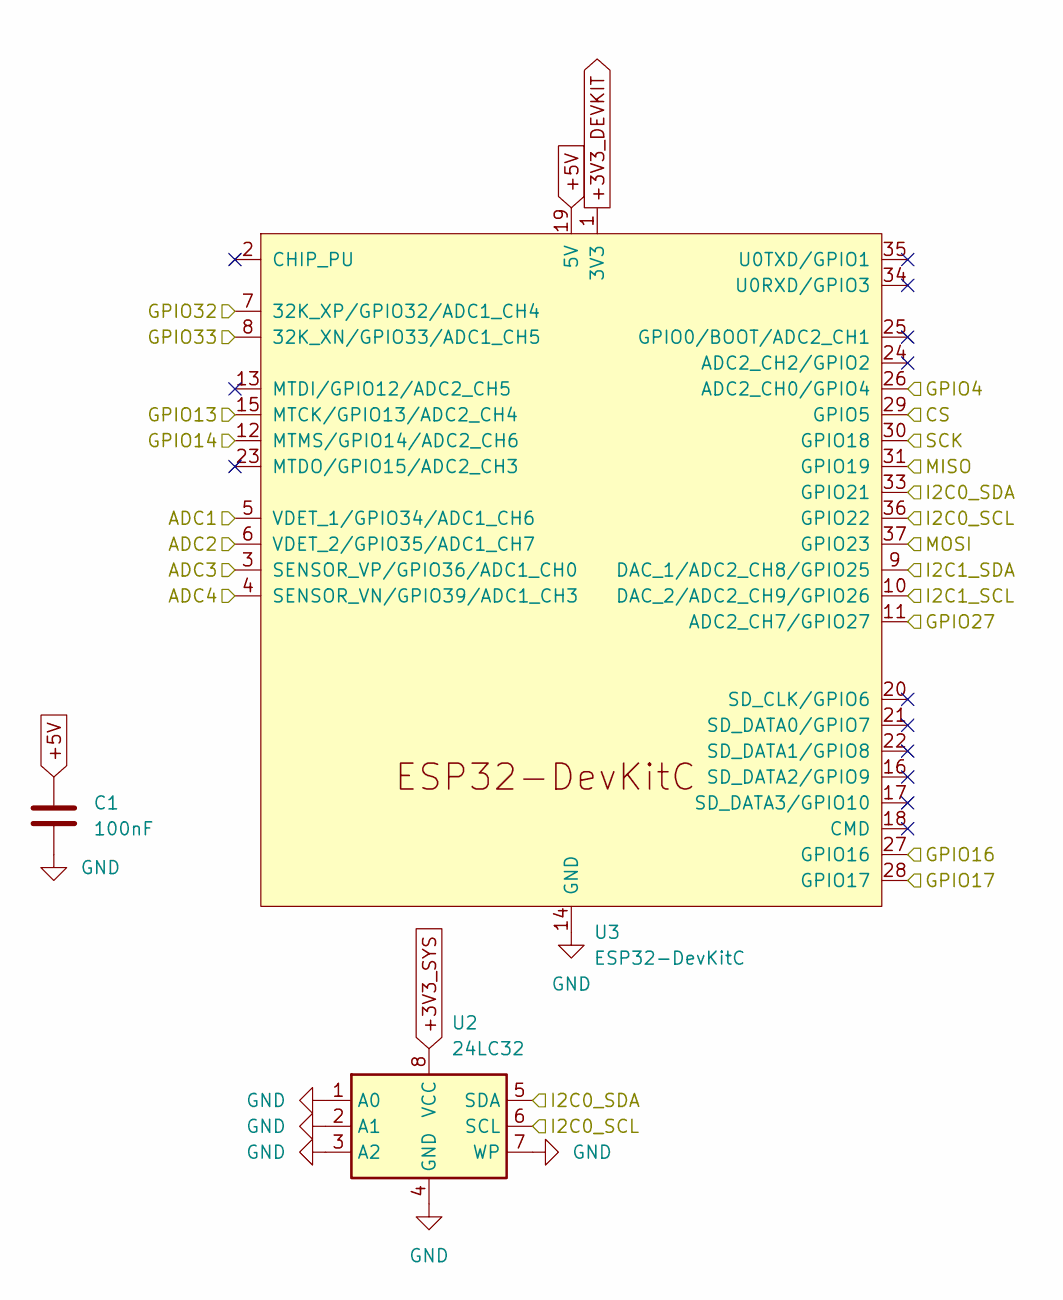
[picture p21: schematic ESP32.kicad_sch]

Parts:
C1: 100nF; C_1206_3216Metric_Pad1.33x1.80mm_HandSolder
U2: 24LC32; SOIC-8_3.9x4.9mm_P1.27mm
U3: ESP32-DevKitC

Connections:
+3V3_DEVKIT: U3.1 (3V3); also elsewhere on the board
+3V3_SYS: U2.8 (VCC); also elsewhere on the board
+5V: C1.1, U3.19 (5V); also elsewhere on the board
ADC1: U3.5 (VDET_1/GPIO34/ADC1_CH6); also elsewhere on the board
ADC2: U3.6 (VDET_2/GPIO35/ADC1_CH7); also elsewhere on the board
ADC3: U3.3 (SENSOR_VP/GPIO36/ADC1_CH0); also elsewhere on the board
ADC4: U3.4 (SENSOR_VN/GPIO39/ADC1_CH3); also elsewhere on the board
CS: U3.29 (GPIO5); also elsewhere on the board
GND: C1.2, U2.1 (A0), U2.2 (A1), U2.3 (A2), U2.4 (GND), U2.7 (WP), U3.14 (GND), U3.32 (GND), U3.38 (GND); also elsewhere on the board
GPIO4: U3.26 (ADC2_CH0/GPIO4); also elsewhere on the board
GPIO13: U3.15 (MTCK/GPIO13/ADC2_CH4); also elsewhere on the board
GPIO14: U3.12 (MTMS/GPIO14/ADC2_CH6); also elsewhere on the board
GPIO16: U3.27 (GPIO16); also elsewhere on the board
GPIO17: U3.28 (GPIO17); also elsewhere on the board
GPIO27: U3.11 (ADC2_CH7/GPIO27); also elsewhere on the board
GPIO32: U3.7 (32K_XP/GPIO32/ADC1_CH4); also elsewhere on the board
GPIO33: U3.8 (32K_XN/GPIO33/ADC1_CH5); also elsewhere on the board
I2C0_SCL: U2.6 (SCL), U3.36 (GPIO22); also elsewhere on the board
I2C0_SDA: U2.5 (SDA), U3.33 (GPIO21); also elsewhere on the board
I2C1_SCL: U3.10 (DAC_2/ADC2_CH9/GPIO26); also elsewhere on the board
I2C1_SDA: U3.9 (DAC_1/ADC2_CH8/GPIO25); also elsewhere on the board
MISO: U3.31 (GPIO19); also elsewhere on the board
MOSI: U3.37 (GPIO23); also elsewhere on the board
SCK: U3.30 (GPIO18); also elsewhere on the board

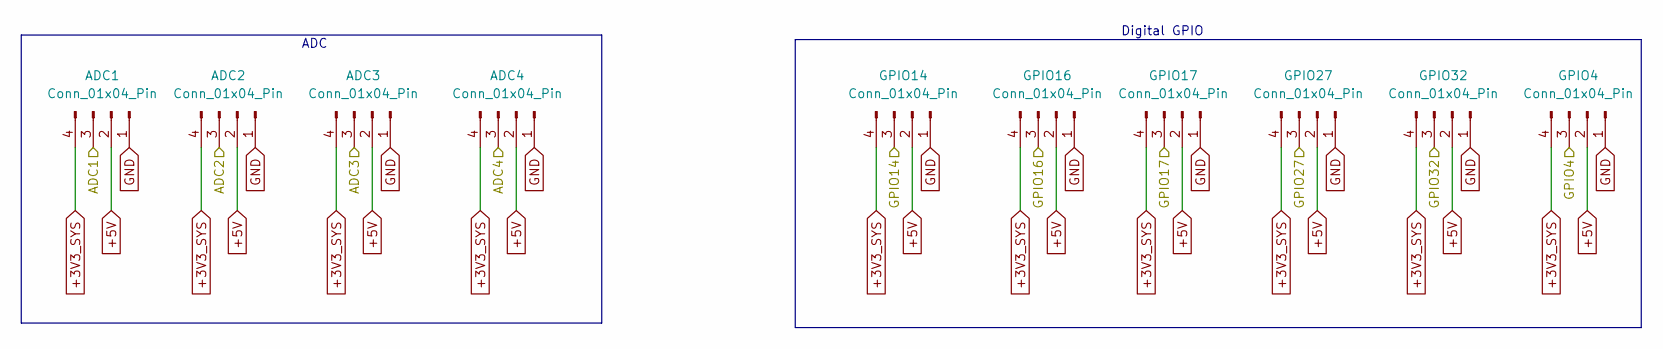
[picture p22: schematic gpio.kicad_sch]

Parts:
ADC1, ADC2, ADC3, ADC4: Conn_01x04_Pin; JST_PH_B4B-PH-K_1x04_P2.00mm_Vertical
GPIO4, GPIO14, GPIO16, GPIO17, GPIO27, GPIO32: Conn_01x04_Pin; JST_PH_B4B-PH-K_1x04_P2.00mm_Vertical

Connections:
+3V3_SYS: ADC1.4, ADC2.4, ADC3.4, ADC4.4, GPIO4.4, GPIO14.4, GPIO16.4, GPIO17.4, GPIO27.4, GPIO32.4; also elsewhere on the board
+5V: ADC1.2, ADC2.2, ADC3.2, ADC4.2, GPIO4.2, GPIO14.2, GPIO16.2, GPIO17.2, GPIO27.2, GPIO32.2; also elsewhere on the board
ADC1: ADC1.3; also elsewhere on the board
ADC2: ADC2.3; also elsewhere on the board
ADC3: ADC3.3; also elsewhere on the board
ADC4: ADC4.3; also elsewhere on the board
GND: ADC1.1, ADC2.1, ADC3.1, ADC4.1, GPIO4.1, GPIO14.1, GPIO16.1, GPIO17.1, GPIO27.1, GPIO32.1; also elsewhere on the board
GPIO4: GPIO4.3; also elsewhere on the board
GPIO14: GPIO14.3; also elsewhere on the board
GPIO16: GPIO16.3; also elsewhere on the board
GPIO17: GPIO17.3; also elsewhere on the board
GPIO27: GPIO27.3; also elsewhere on the board
GPIO32: GPIO32.3; also elsewhere on the board

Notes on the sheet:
Digital GPIO
ADC


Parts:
U1: ORingPower_Module; ORingPower_Carrier

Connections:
+3V3_DEVKIT: U1.4 (+3V3_DEVKIT); also elsewhere on the board
+3V3_SYS: U1.5 (+3V3_SYS); also elsewhere on the board
+5V: U1.2 (+5V); also elsewhere on the board
GND: U1.1 (GND); also elsewhere on the board


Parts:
H1, H2: MountingHole; MountingHole_2.7mm_M2.5
J1: Conn_02x07_Odd_Even; PinSocket_2x07_P2.54mm_Vertical

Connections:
+3V3_SYS: J1.2; also elsewhere on the board
+5V: J1.4; also elsewhere on the board
CS: J1.14; also elsewhere on the board
GND: J1.1, J1.3; also elsewhere on the board
GPIO13: J1.10; also elsewhere on the board
GPIO33: J1.9; also elsewhere on the board
I2C0_SCL: J1.6; also elsewhere on the board
I2C0_SDA: J1.5; also elsewhere on the board
I2C1_SCL: J1.8; also elsewhere on the board
I2C1_SDA: J1.7; also elsewhere on the board
MISO: J1.12; also elsewhere on the board
MOSI: J1.11; also elsewhere on the board
SCK: J1.13; also elsewhere on the board


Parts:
I2C0_1, I2C0_2, I2C0_3, I2C0_4, I2C1_1, I2C1_2, I2C1_3, I2C1_4: Conn_01x04_Pin; JST_SH_BM04B-SRSS-TB_1x04-1MP_P1.00mm_Vertical

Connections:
+3V3_SYS: I2C0_1.2, I2C0_2.2, I2C0_3.2, I2C0_4.2, I2C1_1.2, I2C1_2.2, I2C1_3.2, I2C1_4.2; also elsewhere on the board
GND: I2C0_1.1, I2C0_2.1, I2C0_3.1, I2C0_4.1, I2C1_1.1, I2C1_2.1, I2C1_3.1, I2C1_4.1; also elsewhere on the board
I2C0_SCL: I2C0_1.4, I2C0_2.4, I2C0_3.4, I2C0_4.4; also elsewhere on the board
I2C0_SDA: I2C0_1.3, I2C0_2.3, I2C0_3.3, I2C0_4.3; also elsewhere on the board
I2C1_SCL: I2C1_1.4, I2C1_2.4, I2C1_3.4, I2C1_4.4; also elsewhere on the board
I2C1_SDA: I2C1_1.3, I2C1_2.3, I2C1_3.3, I2C1_4.3; also elsewhere on the board

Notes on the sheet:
I2C - 1
I2C - 0


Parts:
H3, H4, H5, H6: MountingHole; MountingHole_4.5mm_SelfTapping_4mm


Board: 2 copper layers, 113.0 x 93.0 mm, 37 parts (0 on the bottom side), 28 nets.

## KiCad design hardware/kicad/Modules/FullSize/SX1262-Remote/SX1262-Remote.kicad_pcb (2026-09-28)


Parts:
C1, C2, C3: 100nF; C_1206_3216Metric_Pad1.33x1.80mm_HandSolder
C4: 22uF; C_1206_3216Metric_Pad1.33x1.80mm_HandSolder
H1, H2: MountingHole; MountingHole_2.7mm_M2.5_DIN965
J1: Conn_02x07_Odd_Even; PinHeader_2x07_P2.54mm_Vertical_Bottom
Q1: BC817; SOT-23
R1, R3, R4: 10kOhm; R_1206_3216Metric_Pad1.30x1.75mm_HandSolder
R2: 1kOhm; R_1206_3216Metric_Pad1.30x1.75mm_HandSolder
U1: EBYTE_E22-900M22S
U2: 24LC32; SOIC-8_3.9x4.9mm_P1.27mm
U3: PCA9536D; SOIC-8_3.9x4.9mm_P1.27mm

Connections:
/+3V3_SYS: C1.1, C2.1, C3.1, C4.1, J1.2, R1.2, R3.2, R4.2, U1.9 (VCC), U2.2 (A1), U2.8 (VCC), U3.8 (VDD)
/+5V: J1.4
/AUX_GPIO1: J1.9, U1.13 (DIO1)
/AUX_GPIO2: J1.10, U1.14 (BUSY)
/DIO2_TXEN: R2.1, U1.7 (TXEN), U1.8 (DIO2)
/EEPROM_A0: J1.3, U2.1 (A0)
/I2C0_SCL: J1.6, U2.6 (SCL), U3.6 (SCL)
/I2C0_SDA: J1.5, U2.5 (SDA), U3.7 (SDA)
/I2C1_SCL: J1.8
/I2C1_SDA: J1.7
/NRST: R4.1, U1.15 (~NRST), U3.1 (IO0)
/RXEN: Q1.3 (C), R3.1, U1.6 (RXEN)
/SPI_CS: J1.14, R1.1, U1.19 (NSS)
/SPI_MISO: J1.12, U1.16 (MISO)
/SPI_MOSI: J1.11, U1.17 (MOSI)
/SPI_SCK: J1.13, U1.18 (SCK)
GND: C1.2, C2.2, C3.2, C4.2, J1.1, Q1.2 (E), U1.1 (GND), U1.2 (GND), U1.3 (GND), U1.4 (GND), U1.5 (GND), U1.10 (GND), U1.11 (GND), U1.12 (GND), U1.20 (GND), U1.22 (GND), U2.3 (A2), U2.4 (GND), U2.7 (WP), U3.4 (VSS)
unnamed: Q1.1 (B), R2.2

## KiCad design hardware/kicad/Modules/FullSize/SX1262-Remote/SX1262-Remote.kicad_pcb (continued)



Board: 2 copper layers, 38.0 x 64.0 mm, 15 parts (3 on the bottom side), 15 nets.

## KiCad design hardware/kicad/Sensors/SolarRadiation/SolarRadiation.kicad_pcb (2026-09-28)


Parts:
C1: 10nF; C_1206_3216Metric_Pad1.33x1.80mm_HandSolder
C2: 100nF; C_1206_3216Metric_Pad1.33x1.80mm_HandSolder
I2C1: JST-SH; JST_SH_SM04B-SRSS-TB_1x04-1MP_P1.00mm_Horizontal
JP1: 0x48; SolderJumper-2_P1.3mm_Open_Pad1.0x1.5mm
JP2: 0x49; SolderJumper-2_P1.3mm_Open_Pad1.0x1.5mm
JP3: 0x4A; SolderJumper-2_P1.3mm_Open_Pad1.0x1.5mm
JP4: 0x4B; SolderJumper-2_P1.3mm_Open_Pad1.0x1.5mm
JP5, JP6: SolderJumper_3_Open; SolderJumper-3_P1.3mm_Open_RoundedPad1.0x1.5mm_NumberLabels
R1: 2 Ohm; R_Axial_DIN0207_L6.3mm_D2.5mm_P7.62mm_Horizontal
R2: 100 Ohm; R_1206_3216Metric_Pad1.30x1.75mm_HandSolder
SC1: KXOB25-14X1F-TB; KXOB25-14X1F
U1: ADS1115IDGS; TSSOP-10_3x3mm_P0.5mm
U2: TMP100; SOT-23-6

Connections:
+3V3: C2.1, I2C1.2, JP2.1 (A), JP5.1 (A), JP6.1 (A), U1.8 (VDD), U2.4 (V+)
ADC_ADDR: JP1.2 (B), JP2.2 (B), JP3.2 (B), JP4.2 (B), U1.1 (ADDR)
ADD0: JP5.2 (C), U2.5 (ADD0)
ADD1: JP6.2 (C), U2.3 (ADD1)
GND: C1.2, C2.2, I2C1.1, JP1.1 (A), JP5.3 (B), JP6.3 (B), R1.1, SC1.2 (-), U1.3 (GND), U1.5 (AIN1), U2.2 (GND)
unnamed: R1.2, R2.1, SC1.1 (+)
unnamed: C1.1, R2.2, U1.4 (AIN0)
SCL: I2C1.4, JP4.1 (A), U1.10 (SCL), U2.1 (SCL)
SDA: I2C1.3, JP3.1 (A), U1.9 (SDA), U2.6 (SDA)



Board: 2 copper layers, 43.0 x 27.0 mm, 14 parts (4 on the bottom side), 9 nets.

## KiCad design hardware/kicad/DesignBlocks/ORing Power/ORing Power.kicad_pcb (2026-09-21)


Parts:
C1, C5: 100nF; C_1206_3216Metric_Pad1.33x1.80mm_HandSolder
C2: 10uF; CP_Elec_5x5.4
C3: 10uF; C_1206_3216Metric_Pad1.33x1.80mm_HandSolder
C4: 47uF; CP_EIA-3528-21_Kemet-B
D1, D2: SS14; D_SMA
J1: Conn_01x02_Pin; JST_PH_B2B-PH-SM4-TB_1x02-1MP_P2.00mm_Vertical
J3: USB_C_Receptacle_PowerOnly_6P; USB_C_Receptacle_GCT_USB4125-xx-x-0190_6P_TopMnt_Horizontal
R1, R2: 5,1kOhm; R_1206_3216Metric_Pad1.30x1.75mm_HandSolder
U1: LM3940IMP-3.3/NOPB; SOT-223-3_TabPin2
U2: ORingPower_Module; ORingPower_Module_Castellated

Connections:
+3V3_DEVKIT: D2.2 (A), U2.4 (+3V3_DEVKIT)
+3V3_EXT: C4.1, C5.2, D1.2 (A), U1.3 (OUT), U2.3 (+3V3_EXT)
+3V3_SYS: C1.1, C2.1, D1.1 (K), D2.1 (K), U2.5 (+3V3_SYS)
+5V: C3.1, J1.2, J3.A9 (VBUS), J3.B9 (VBUS), U1.1 (IN), U2.2 (+5V)
GND: C1.2, C2.2, C3.2, C4.2, C5.1, J1.1, J3.A12 (GND), J3.B12 (GND), J3.SH (SHIELD), R1.2, R2.2, U1.2 (GND), U2.1 (GND)
unnamed: J3.A5 (CC1), R2.1
unnamed: J3.B5 (CC2), R1.1


Board: 2 copper layers, 39.0 x 15.0 mm, 13 parts (0 on the bottom side), 7 nets.

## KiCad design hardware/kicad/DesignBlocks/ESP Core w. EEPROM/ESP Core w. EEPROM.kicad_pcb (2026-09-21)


Board: 2 copper layers, 3 parts (0 on the bottom side), 4 nets.

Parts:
C1: 100nF; C_1206_3216Metric_Pad1.33x1.80mm_HandSolder
U1: ESP32-DevKitC
U2: 24LC32; SOIC-8_3.9x4.9mm_P1.27mm

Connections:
+5V: C1.1, U1.19 (5V)
GND: C1.2, U1.14 (GND), U1.32 (GND), U1.38 (GND), U2.1 (A0), U2.2 (A1), U2.3 (A2), U2.4 (GND), U2.7 (WP)
I2C0_SCL: U1.36 (GPIO22), U2.6 (SCL)
I2C0_SDA: U1.33 (GPIO21), U2.5 (SDA)

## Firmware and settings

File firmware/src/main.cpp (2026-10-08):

#include "FirmwareBuildInfo.h"
#include "Application.h"
#include "DisplayService.h"
#include "U8g2TextDisplay.h"
#include "PropertyResolver.h"
#include "SystemPropertyReader.h"
#include "ValuePropertyReader.h"
#include "ConfigurationService.h"
#include "SerialLogger.h"
#include "WiFiService.h"
#include "WebService.h"
#include "MqttService.h"
#include "TimeService.h"
#include "ArduinoMonotonicClock.h"
#include "MeasurementPublisher.h"
#include "SensorManager.h"
#include "SimulatedTemperatureSensor.h"
#include "SimulatedHumiditySensor.h"
#include "SimulatedPressureSensor.h"
#include "AM2302Sensor.h"
#include "LocaleFormatter.h"
#include "RuntimeManager.h"
#include "OTAService.h"
#include "HardwareResources.h"
#include "SensorImplementationRegistry.h"
#include "SensorSlotConfiguration.h"
#include "SensorFactory.h"
#include "SensorRuntime.h"
#include "HomeAssistantDiscoveryPublisher.h"
#include "MeasurementSnapshotCache.h"
#include "I2CBusManager.h"
#include "ActuatorFactory.h"
#include "ActuatorRuntime.h"
#include "ActuatorMqttAdapter.h"
#include "ActuatorStatePublisher.h"
#include "ControllerFactory.h"
#include "ControllerRuntime.h"
#include "ControllerMqttAdapter.h"
#include "ControllerStatePublisher.h"
#include "MqttMessageRouter.h"
#include "MqttDescriptionPublisher.h"
#include "StructuredLogger.h"
#include "RecentLogStore.h"
#include "SystemLogTimeProvider.h"
#include "IdentityEeprom24LC32.h"
#include "BoardIdentityResolver.h"
#include "ModuleDiscoveryService.h"
#include "HardwareDescriptorStore.h"
#include "ModuleDescriptorProvisioningService.h"
#include "ModuleActuatorComposer.h"

using namespace EnvNode;

static ArduinoMonotonicClock monotonicClock;
static SystemLogTimeProvider logTimeProvider(monotonicClock);
static RecentLogStore recentLogStore;
static SerialLogger serialLogSink;
static StructuredLogger logger(recentLogStore, logTimeProvider, serialLogSink);
static ActuatorFactory actuatorFactory(logger);
static ActuatorRuntime actuatorRuntime(actuatorFactory, logger);
static I2CBusManager i2cBusManager(logger);
static IdentityEeprom24LC32 boardIdentityEeprom(i2cBusManager, 0x50);
static BoardIdentityStore boardIdentityStore(boardIdentityEeprom);
static BoardIdentityResolver boardIdentityResolver(
    boardIdentityStore, buildFallbackBoardProfileId());
static BoardProvisioningService boardProvisioningService(boardIdentityStore);
static IdentityEeprom24LC32 slotAModuleEeprom(
    i2cBusManager, ModuleDiscoveryService::SlotAEepromAddress);
static IdentityEeprom24LC32 slotBModuleEeprom(
    i2cBusManager, ModuleDiscoveryService::SlotBEepromAddress);
static HardwareDescriptorStore slotAHardwareDescriptorStore(slotAModuleEeprom);
static HardwareDescriptorStore slotBHardwareDescriptorStore(slotBModuleEeprom);
static ModuleDiscoveryService moduleDiscoveryService(
    slotAHardwareDescriptorStore, slotBHardwareDescriptorStore);
static ModuleDescriptorProvisioningService moduleDescriptorProvisioningService(
    slotAHardwareDescriptorStore, slotBHardwareDescriptorStore,
    moduleDiscoveryService);
static ModuleActuatorComposer moduleActuatorComposer;
static ConfigurationService configurationService;
static ValueRuntime valueRuntime(configurationService);
static WiFiService wifiService(logger, configurationService);
static TimeService timeService(logger, configurationService, wifiService);
static MqttService mqttService(logger, configurationService, wifiService);
static ActuatorMqttAdapter actuatorMqttAdapter(
    logger, configurationService, mqttService, actuatorRuntime);
static ActuatorStatePublisher actuatorStatePublisher(
    logger, configurationService, mqttService, actuatorRuntime);
static MeasurementSnapshotCache measurementSnapshotCache;
static ControllerFactory controllerFactory(
    measurementSnapshotCache, actuatorRuntime, monotonicClock, logger, &valueRuntime);
static ControllerRuntime controllerRuntime(controllerFactory, logger);
static MeasurementPublisher measurementPublisher(configurationService, timeService, mqttService);
static SensorManager sensorManager(
    timeService,
    monotonicClock,
    measurementPublisher,
    measurementSnapshotCache);
static SensorFactory firstSensorFactory(monotonicClock, i2cBusManager, logger);
static SensorFactory secondSensorFactory(monotonicClock, i2cBusManager, logger);
static SensorRuntime sensorRuntime(
    configurationService,
    firstSensorFactory,
    secondSensorFactory,
    sensorManager);
static LocaleFormatter localeFormatter(configurationService);
static RuntimeManager runtimeManager(
    logger, &sensorRuntime, &actuatorRuntime, &controllerRuntime);
static ControllerMqttAdapter controllerMqttAdapter(
    logger, configurationService, mqttService, controllerRuntime, runtimeManager);
static ValueMqttAdapter valueMqttAdapter(logger, configurationService, mqttService, valueRuntime);
static ValueStatePublisher valueStatePublisher(logger, configurationService, mqttService, valueRuntime);
static MqttMessageRouter mqttMessageRouter(
    mqttService, actuatorMqttAdapter, controllerMqttAdapter, &valueMqttAdapter);
static ControllerStatePublisher controllerStatePublisher(
    logger, configurationService, mqttService, controllerRuntime);
static MqttDescriptionPublisher mqttDescriptionPublisher(
    logger, configurationService, mqttService, monotonicClock);
static HomeAssistantDiscoveryPublisher homeAssistantDiscoveryPublisher(
    logger,
    configurationService,
    mqttService,
    sensorManager,
    actuatorRuntime);
static SystemPropertyReader timeProperties(timeService, localeFormatter, FirmwareBuildInfo::SemanticVersion, FirmwareBuildInfo::BuildNumber, FirmwareBuildInfo::GitCommit, FirmwareBuildInfo::CompactIdentity);
static ValuePropertyReader valueProperties(valueRuntime);
static PropertyResolver displayProperties(sensorManager, measurementSnapshotCache, actuatorRuntime, controllerRuntime, &timeProperties, &valueProperties);
static U8g2TextDisplay oled(i2cBusManager, logger);
static U8g2TextDisplay secondOled(i2cBusManager, logger);
static DisplayService displayService(configurationService.getConfiguration().display,
    displayProperties, oled, monotonicClock, logger, &secondOled);
static OTAService otaService(logger, runtimeManager);
static WebService webService(logger, configurationService, valueRuntime, wifiService, mqttService, timeService, localeFormatter, sensorManager, actuatorRuntime, controllerRuntime, measurementSnapshotCache, recentLogStore, homeAssistantDiscoveryPublisher, runtimeManager, otaService, i2cBusManager, boardIdentityResolver.resolution(), boardProvisioningService, moduleDiscoveryService, moduleDescriptorProvisioningService);
static Application app(logger, configurationService, wifiService, webService, mqttService, timeService, sensorManager, actuatorRuntime, controllerRuntime, runtimeManager, homeAssistantDiscoveryPublisher, mqttMessageRouter, actuatorMqttAdapter, actuatorStatePublisher, controllerMqttAdapter, controllerStatePublisher, mqttDescriptionPublisher, displayService, valueMqttAdapter, valueStatePublisher);
static bool normalRuntimeStarted = false;

void setup() {
    configurationService.setActuatorResolver(&actuatorRuntime);
    logger.begin(115200);
    delay(500);
    i2cBusManager.beginIdentityBus();
    const BoardIdentityResolution& identityResolution = boardIdentityResolver.resolve();
    logger.infof(
        "Board identity source=%s status=%s profile=%u revision=%u.%u serial=%lu",
        boardIdentitySourceName(identityResolution.source),
        boardIdentityStatusName(identityResolution.recordStatus),
        static_cast<unsigned int>(identityResolution.identity.profileId),
        identityResolution.identity.revision.major,
        identityResolution.identity.revision.minor,
        static_cast<unsigned long>(identityResolution.identity.serialNumber));
    if (!identityResolution.normalRuntimeAllowed
        || !selectCurrentBoardProfile(identityResolution.identity.profileId)) {
        logger.error("Board identity unsupported; normal runtime initialization stopped");
        return;
    }

    i2cBusManager.begin();
    moduleDiscoveryService.scan();
    i2cBusManager.scanAll();
    for (size_t index = 0; index < ModuleDiscoveryService::SlotCount; ++index) {
        const ModuleSlot slot = static_cast<ModuleSlot>(index);
        const ModuleDiscoveryResult* module = moduleDiscoveryService.result(slot);
        if (module == nullptr) {
            logger.errorf("Module discovery returned no result for slot=%s",
                moduleSlotName(slot));
            continue;
        }
        if (module->source == ModuleDiscoverySource::Descriptor) {
            logger.infof(
                "Module slot=%s address=0x%02X source=%s store=%s descriptor=%s type=%.*s name=%.*s compatibility=%s",
                moduleSlotName(slot), module->eepromAddress,
                moduleDiscoverySourceName(module->source),
                hardwareDescriptorStoreStatusName(module->descriptorStoreStatus),
                hardwareDescriptorDecodeStatusName(module->descriptorStatus),
                static_cast<int>(module->descriptorTypeId.size),
                module->descriptorTypeId.data == nullptr ? "" : module->descriptorTypeId.data,
                static_cast<int>(module->descriptorName.size),
                module->descriptorName.data == nullptr ? "" : module->descriptorName.data,
                hardwareDescriptorCompatibilityStatusName(module->descriptorCompatibility));
        } else {
            logger.infof(
                "Module slot=%s address=0x%02X source=%s store=%s",
                moduleSlotName(slot), module->eepromAddress,
                moduleDiscoverySourceName(module->source),
                hardwareDescriptorStoreStatusName(module->descriptorStoreStatus));
        }
    }
    configurationService.loadConfiguration();
    valueRuntime.begin();
    const Configuration& configuration = configurationService.getConfiguration();
    moduleActuatorComposer.compose(
        moduleDiscoveryService, currentBoardProfile(), configuration.sensorSlots);
    if (!actuatorRuntime.configureAutomaticActuators(
            moduleActuatorComposer.definitions(), moduleActuatorComposer.count())) {
        logger.error("Automatic module actuator configuration failed");
    }
    size_t activeSensorCount = 0;
    const char* sensorFailureReason = nullptr;
    const bool sensorsInitialized = sensorRuntime.initialize(
        activeSensorCount, sensorFailureReason);
    app.setup(true);
    if (!sensorsInitialized) {
        logger.errorf("Sensor runtime initialization failed: %s",
            sensorFailureReason == nullptr ? "unknown failure" : sensorFailureReason);
    }
    normalRuntimeStarted = true;
}

void loop() {
    if (normalRuntimeStarted) {
        app.loop();
    }
}

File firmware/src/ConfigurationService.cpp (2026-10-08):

#include "ControllerTargetIdentity.h"
#include "ConfigurationService.h"
#include <Arduino.h>
#include <Preferences.h>
#include <IPAddress.h>
#include "SensorImplementationRegistry.h"
#include "ActuatorImplementationRegistry.h"
#include "ControllerImplementationRegistry.h"
#include "HardwareResources.h"
#include <cmath>
#include <cstring>

namespace EnvNode {

namespace {
constexpr const char* PreferencesNamespace = "weather";
constexpr const char* KeyDeviceName = "deviceName";
constexpr const char* KeyWifiSSID = "wifiSSID";
constexpr const char* KeyWifiPassword = "wifiPassword";
constexpr const char* KeyHostname = "hostname";
constexpr const char* KeyAddressMode = "addressMode";
constexpr const char* KeyIpv4Address = "ipv4Address";
constexpr const char* KeySubnetMask = "subnetMask";
constexpr const char* KeyGateway = "gateway";
constexpr const char* KeyDns1 = "dns1";
constexpr const char* KeyDns2 = "dns2";
constexpr const char* KeyMqttServer = "mqttServer";
constexpr const char* KeyMqttPort = "mqttPort";
constexpr const char* KeyMqttUsername = "mqttUsername";
constexpr const char* KeyMqttPassword = "mqttPassword";
constexpr const char* KeyTimezone = "timezone";
constexpr const char* KeyNtpServer1 = "ntpServer1";
constexpr const char* KeyNtpServer2 = "ntpServer2";
constexpr const char* KeyLocale = "locale";
constexpr const char* KeyTemperatureUnit = "unitTemp";
constexpr const char* KeyPressureUnit = "unitPressure";
constexpr const char* KeySolarCellTemperatureUnit = "unitSolarTemp";
constexpr const char* KeyRainDetectorLevelUnit = "unitRainLevel";
constexpr uint16_t DefaultMqttPort = 1883;
constexpr const char* DefaultTimezone = "CET-1CEST,M3.5.0/2,M10.5.0/3";
constexpr const char* DefaultNtpServer1 = "pool.ntp.org";
constexpr const char* DefaultNtpServer2 = "time.cloudflare.com";
constexpr size_t MaxDeviceNameLength = 32;
constexpr size_t MaxWifiSSIDLength = 32;
constexpr size_t MaxWifiPasswordLength = 64;
constexpr size_t MaxMqttServerLength = 64;
constexpr size_t MaxMqttUsernameLength = 32;
constexpr size_t MaxMqttPasswordLength = 64;
constexpr size_t MaxTimezoneLength = 128;
constexpr size_t MaxNtpServerLength = 64;
constexpr size_t MaxHostnameLength = 63;

String sensorKey(SensorId slotId, const char* field) {
    return "s" + String(slotId) + "_" + field;
}

String actuatorKey(ActuatorId slotId, const char* field) {
    return "a" + String(slotId) + "_" + field;
}

String controllerKey(ControllerId slotId, const char* field) {
    return "c" + String(slotId) + "_" + field;
}

String bytesHex(const uint8_t* value, size_t length) {
    static const char Hex[] = "0123456789abcdef";
    String result;
    result.reserve(length * 2);
    for (size_t index = 0; index < length; ++index) {
        result += Hex[value[index] >> 4];
        result += Hex[value[index] & 0x0f];
    }
    return result;
}

bool parseHex(const String& text, uint8_t* value, size_t length) {
    if (text.length() != length * 2) return false;
    for (size_t index = 0; index < length; ++index) {
        const char high = text[index * 2];
        const char low = text[index * 2 + 1];
        const auto digit = [](char c) -> int {
            if (c >= '0' && c <= '9') return c - '0';
            if (c >= 'a' && c <= 'f') return c - 'a' + 10;
            if (c >= 'A' && c <= 'F') return c - 'A' + 10;
            return -1;
        };
        const int h = digit(high);
        const int l = digit(low);
        if (h < 0 || l < 0) return false;
        value[index] = static_cast<uint8_t>((h << 4) | l);
    }
    return true;
}

void loadModuleTarget(
    Preferences& preferences, ControllerId id, const char* prefix,
    ModuleActuatorReference& target) {
    target = ModuleActuatorReference{};
    const String kindKey = controllerKey(id, (String(prefix) + "kind").c_str());
    if (preferences.getUInt(kindKey.c_str(), 0) != 1) return;
    const String uuid = preferences.getString(
        controllerKey(id, (String(prefix) + "uuid").c_str()).c_str(), "");
    const String deviceHash = preferences.getString(
        controllerKey(id, (String(prefix) + "dev").c_str()).c_str(), "");
    if (!parseHex(uuid, target.moduleInstanceFingerprint,
            sizeof(target.moduleInstanceFingerprint))
        || !parseHex(deviceHash, target.deviceIdHash,
            sizeof(target.deviceIdHash))) return;
}
}

void ConfigurationService::ensurePreferencesStarted() {
    if (!preferencesInitialized_) {
        preferences_.begin(PreferencesNamespace, false);
        preferencesInitialized_ = true;
    }
}
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

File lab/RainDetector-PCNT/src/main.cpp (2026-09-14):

#include <Arduino.h>
#include <driver/pcnt.h>
#include <esp_timer.h>
#include <soc/pcnt_struct.h>

#include "LabConfig.h"

namespace {
constexpr pcnt_unit_t CounterUnit = PCNT_UNIT_0;
constexpr uint32_t CounterMask = 1U << CounterUnit;
constexpr int16_t CounterLimit = 32767;

void check(esp_err_t result, const char* operation) {
    if (result == ESP_OK) {
        return;
    }
    Serial.printf("# error,%s,%s\n", operation, esp_err_to_name(result));
    Serial.flush();
    // Do not publish plausible-looking measurements after a driver error.
    while (true) {
        delay(1000);
    }
}
}  // namespace

void setup() {
    Serial.begin(LabConfig::SerialBaud);
    pcnt_config_t config = {};
    config.pulse_gpio_num = LabConfig::RainFreqGpio;
    config.ctrl_gpio_num = PCNT_PIN_NOT_USED;
    config.unit = CounterUnit;
    config.channel = PCNT_CHANNEL_0;
    config.pos_mode = PCNT_COUNT_INC;
    config.neg_mode = PCNT_COUNT_DIS;
    config.lctrl_mode = PCNT_MODE_KEEP;
    config.hctrl_mode = PCNT_MODE_KEEP;
    config.counter_h_lim = CounterLimit;
    config.counter_l_lim = -1;
    check(pcnt_unit_config(&config), "configure");
    check(pcnt_counter_pause(CounterUnit), "pause");
    // The actively driven 3.3 V oscillator needs no internal pull resistors.
    check(gpio_set_pull_mode(static_cast<gpio_num_t>(LabConfig::RainFreqGpio),
                             GPIO_FLOATING), "pull_mode");
    check(pcnt_filter_disable(CounterUnit), "filter_disable");
    check(pcnt_intr_disable(CounterUnit), "interrupt_disable");
    check(pcnt_event_enable(CounterUnit, PCNT_EVT_H_LIM), "limit_event");
    Serial.println("timestamp_ms,pulse_count,frequency_hz");
    Serial.flush();
}

void loop() {
    check(pcnt_counter_clear(CounterUnit), "clear");
    // Only the high-limit event is enabled. Its raw interrupt bit latches
    // even with CPU interrupts disabled, detecting ANY wrap in this window.
    // These two register accesses are specific to the classic ESP32.
    PCNT.int_clr.val = CounterMask;
    const int64_t startUs = esp_timer_get_time();
    check(pcnt_counter_resume(CounterUnit), "resume");
    while (esp_timer_get_time() - startUs < LabConfig::MeasurementWindowUs) {
        delay(1);  // Yield; PCNT counts autonomously. No GPIO polling.
    }
    check(pcnt_counter_pause(CounterUnit), "pause");
    const int64_t endUs = esp_timer_get_time();
    int16_t pulseCount = 0;
    check(pcnt_get_counter_value(CounterUnit, &pulseCount), "read");
    const bool overflow = (PCNT.int_raw.val & CounterMask) != 0;
    if (overflow) {
        // The hardware resets at 32767; the residual count is not a total.
        Serial.printf("%llu,%d,nan\n",
                      static_cast<unsigned long long>(endUs / 1000), pulseCount);
    } else {
        const double frequencyHz = pulseCount * 1000000.0 / (endUs - startUs);
        Serial.printf("%llu,%d,%.3f\n",
                      static_cast<unsigned long long>(endUs / 1000),
                      pulseCount, frequencyHz);
    }
    Serial.flush();  // Complete output outside the next measurement window.
}

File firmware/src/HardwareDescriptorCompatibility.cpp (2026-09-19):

#include "HardwareDescriptorCompatibility.h"

#include <cstdlib>

#include "FirmwareVersion.h"

namespace EnvNode {
namespace {

bool versionLessThan(DescriptorSemanticVersion left, DescriptorSemanticVersion right) {
    if (left.major != right.major) return left.major < right.major;
    if (left.minor != right.minor) return left.minor < right.minor;
    return left.patch < right.patch;
}

bool matches(
    const DescriptorIdentifier& identifier,
    uint16_t code,
    const char* text) {
    return identifier.coded
        ? identifier.code == code
        : identifier.text.equals(text);
}

bool supportedDriver(const DescriptorContract& driver) {
    return driver.apiVersion == 1
        && matches(driver.id,
            static_cast<uint8_t>(HardwareDescriptorDriverCode::GpioOnOff),
            "org.envnode.driver.gpio-on-off");
}

bool supportedCapability(const DescriptorIdentifier& capability) {
    return matches(capability,
        static_cast<uint8_t>(HardwareDescriptorCapabilityCode::ActuatorOnOff),
        "actuator.on-off");
}

const BoardGpioCapability* gpioCapability(
    const BoardProfile& board,
    GpioResource resource) {
    for (size_t index = 0; index < board.gpioCount; ++index) {
        if (board.gpios[index].resource.number == resource.number) return &board.gpios[index];
    }
    return nullptr;
}

bool hasI2CBus(const BoardProfile& board, I2CBus bus) {
    for (size_t index = 0; index < board.i2cBusCount; ++index) {
        if (board.i2cBuses[index].bus == bus) return true;
    }
    return false;
}

GpioCapability requiredGpioCapabilities(const DescriptorCapabilitySet& capabilities) {
    GpioCapability result = GpioCapability::None;
    if (capabilities.contains(HardwareDescriptorCapabilityCode::DigitalInput)) {
        result = result | GpioCapability::DigitalInput;
    }
    if (capabilities.contains(HardwareDescriptorCapabilityCode::DigitalOutput)) {
        result = result | GpioCapability::DigitalOutput;
    }
    if (capabilities.contains(HardwareDescriptorCapabilityCode::AnalogInput)) {
        result = result | GpioCapability::AnalogInput;
    }
    return result;
}

} // namespace

DescriptorSemanticVersion currentFirmwareDescriptorVersion() {
    DescriptorSemanticVersion version;
    const char* cursor = FirmwareVersion;
    char* end = nullptr;
    version.major = static_cast<uint16_t>(std::strtoul(cursor, &end, 10));
    if (end == cursor || *end != '.') return {};
    cursor = end + 1;
    version.minor = static_cast<uint16_t>(std::strtoul(cursor, &end, 10));
    if (end == cursor || *end != '.') return {};
    cursor = end + 1;
    version.patch = static_cast<uint16_t>(std::strtoul(cursor, &end, 10));
    return end == cursor ? DescriptorSemanticVersion() : version;
}

HardwareDescriptorCompatibilityResult evaluateModuleDescriptorCompatibility(
    const HardwareDescriptor& descriptor,
    DescriptorSemanticVersion firmwareVersion,
    const BoardProfile& board,
    ModuleSlot slotId) {
    HardwareDescriptorCompatibilityResult result;
    if (versionLessThan(firmwareVersion, descriptor.compatibility.minimumFirmwareVersion)) {
        result.status = HardwareDescriptorCompatibilityStatus::FirmwareTooOld;
        return result;
    }
    if (descriptor.compatibility.platform.apiVersion != 1
        || !matches(descriptor.compatibility.platform.id,
            static_cast<uint8_t>(HardwareDescriptorPlatformCode::Any),
            "org.envnode.platform.any")) {
        result.status = HardwareDescriptorCompatibilityStatus::UnsupportedPlatform;
        return result;
    }
    if (descriptor.compatibility.safetyProfile.apiVersion != 1
        || !matches(descriptor.compatibility.safetyProfile.id,
            static_cast<uint8_t>(HardwareDescriptorSafetyProfileCode::ModuleInterface),
            "org.envnode.safety.module-interface")) {
        result.status = HardwareDescriptorCompatibilityStatus::UnsupportedSafetyProfile;
        return result;
    }
    if (!matches(descriptor.interfaceId,
            static_cast<uint8_t>(HardwareDescriptorInterfaceCode::Module2x7),
            "org.envnode.interface.module-2x7")) {
        result.status = HardwareDescriptorCompatibilityStatus::UnsupportedInterface;
        return result;
    }
    for (size_t index = 0; index < descriptor.compatibility.driverCount; ++index) {
        if (!supportedDriver(descriptor.compatibility.drivers[index])) {
            result.status = HardwareDescriptorCompatibilityStatus::MissingDriver;
            result.failedIndex = index;
            return result;
        }
    }
    for (size_t index = 0; index < descriptor.compatibility.capabilityCount; ++index) {
        if (!supportedCapability(descriptor.compatibility.capabilities[index])) {
            result.status = HardwareDescriptorCompatibilityStatus::MissingCapability;
            result.failedIndex = index;
            return result;
        }
    }

    const BoardModuleSlotCapability* slot = boardModuleSlot(board, slotId);
    if (slot == nullptr) {
        result.status = HardwareDescriptorCompatibilityStatus::SlotUnavailable;
        return result;
    }
    for (size_t index = 0; index < descriptor.requirementCount; ++index) {
        result.failedIndex = index;
        const DescriptorRequirement& requirement = descriptor.requirements[index];
        if (requirement.capabilities.hasUnknown) {
            result.status = HardwareDescriptorCompatibilityStatus::ResourceCapabilityMismatch;
            return result;
        }
        if (requirement.resource.equals("I2C0") || requirement.resource.equals("I2C1")) {
            if (requirement.kind != HardwareDescriptorResourceKind::I2C) {
                result.status = HardwareDescriptorCompatibilityStatus::ResourceKindMismatch;
                return result;
            }
            const I2CBus bus = requirement.resource.equals("I2C0")
                ? I2CBus::I2C0 : I2CBus::I2C1;
            if (!hasI2CBus(board, bus)) {
                result.status = HardwareDescriptorCompatibilityStatus::ResourceUnavailable;
                return result;
            }
            continue;
        }
        if (requirement.resource.equals("+5V")) {
            if (requirement.kind != HardwareDescriptorResourceKind::Power) {
                result.status = HardwareDescriptorCompatibilityStatus::ResourceKindMismatch;
                return result;
            }
            if (!slot->fiveVoltSupplyAvailable) {
                result.status = HardwareDescriptorCompatibilityStatus::ResourceUnavailable;
                return result;
            }
            continue;
        }
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

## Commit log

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2026-08-06 firmware: implement WiFi provisioning Implement initial network provisioning workflow.
    - add embedded WebService
    - provide setup access point configuration page
    - persist WiFi configuration using ConfigurationService
    - restart device after successful provisioning
    - automatically connect to configured WiFi after reboot
    - keep ConfigurationService as the single owner of persistent configuration
    - preserve dependency injection across all services
    Verified on ESP32 hardware.
    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
    [main.cpp]
2026-08-06 - add MQTT configuration for broker, port and credentials - persist MQTT settings through ConfigurationService - extend WebService configuration page - add MQTT service with WiFi-aware reconnect beha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
    [Configuration.h, ConfigurationService.h]
2026-08-06 firmware: implement complete device provisioning and MQTT connectivity Implement the complete WeatherStation connectivity and provisioning infrastructure.
    - add persistent configuration service using ESP32 Preferences
    - add WiFi service with station mode, setup access point and reconnect handling
    - implement embedded provisioning web interface
    - support browser-based configuration of:
    - device name
    - WiFi settings
    - MQTT server
    - MQTT credentials
    - add configuration reset-to-defaults
    - implement MQTT connectivity with authenticated broker access
    - preserve dependency injection and service boundaries
    - keep ConfigurationService as the single persistence owner
    Runtime
    - a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
    [ConfigurationService.h]
2026-08-07 firmware: implement complete connectivity and time infrastructure Implement the complete WeatherStation runtime infrastructure.
    Connectivity
    - implement browser-based configuration interface
    - add factory reset to defaults
    - support device, WiFi, MQTT and time configuration
    WiFi
    - implement station mode with automatic reconnect
    - implement setup access point for initial provisioning
    - support hostname configuration
    Time
    - add dedicated TimeService
    - synchronize system clock using SNTP
    - support configurable timezone
    - provide UTC and local ISO-8601 timestamps
    - automatic daylight saving time handling
    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
    [Configuration.h, ConfigurationService.h]
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2026-08-07 firmware: fix SNTP initialization using thread-safe ESP-IDF API - replace Arduino configTzTime path with thread-safe esp_sntp initialization - preserve configurable NTP servers and POSIX timezone han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
2026-08-07 firmware: implement sensor manager scheduling and measurement acceptance - add fixed-capacity SensorManager - support periodic and event-only sensor scheduling - use wrap-safe monotonic deadlines - l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
2026-08-07 feat: add structured web administration interface - replace the single configuration form with functional administration pages - add shared responsive navigation and styling - add status, sensors, ne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
    [Configuration.h, ConfigurationService.h]
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2026-08-07 feat(ota): add staged firmware update workflow - add OTA firmware upload service - implement staged firmware update lifecycle - integrate OTA with RuntimeManager restart handling - add firmware uploa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
    [main.cpp]
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2026-08-08 feat(sensor): add physical AM2302 temperature and humidity sensor - add AM2302 / DHT22 physical sensor implementation - integrate GPIO-based sensor through existing ISensor contract - emit canonical 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
    [main.cpp]
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2026-08-08 feat(mqtt): implement sensor identity and external measurement addressing Implement ADR-0010 "Sensor Identity and External Measurement Addressing".
    - publish Measurements using Device/SensorId/MeasurementType topics
    - eliminate MQTT collisions for identical MeasurementTypes
    - expose Sensor metadata (Slot, Name, Type, Provenance, State)
    - extend runtime sensor overview with implementation metadata
    - preserve canonical Measurement pipeline and Presentation Units
    - support simultaneous physical and simulated sensors
    - prepare runtime model for future Sensor Slot configuration
    [main.cpp]
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2026-08-08 feat(sensor): implement configurable runtime sensor composition
    Implement the complete runtime composition model introduced by
    ADR-0011.
    The WeatherStation is no longer built from statically instantiated
    Sensors in the composition root. Runtime composition is now driven by
    persistent Sensor Slot configuration and constructed through the
    SensorFactory.
    Implemented:
    - persistent Sensor Slot configuration
    - SensorFactory-based runtime construction
    - implementation selection
    - enable/disable semantics
    - implementation-specific configuration
    - GPIO resource assignment for AM2302
    - runtime Sensor rebuild without Device reboot
    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
    [Configuration.h, ConfigurationRuntimeEffect.h, ConfigurationService.h]
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2026-08-08 feat(web): filter occupied GPIO resources in sensor configuration
    Make Sensor Slot configuration resource-aware.
    - derive GPIO choices from BoardCapabilities
    - exclude GPIOs consumed by other enabled Sensor Slots
    - preserve the currently edited Slot's own resource assignment
    - release resources belonging to disabled or unassigned Slots
    - retain server-side conflict validation as the authoritative guard
    - avoid duplicating GPIO capability lists inside WebService
    This prevents invalid resource assignments before they reach validation
    while preserving the generic Sensor hardware-resource model.
    [main.cpp]
2026-08-08 feat(ha): add manual discovery republish action
    Add an explicit diagnostics action for Home Assistant MQTT Discovery.
    - reuse the existing DiscoveryPublisher
    - publish the current retained Device Discovery document on demand
    - preserve stable Device and Entity identities
    - reflect current Sensor composition and Presentation Units
    - expose success/failure through the existing Web interface
    - leave normal Measurement publishing unchanged and non-retained
    This provides a simple recovery and diagnostics tool without introducing
    a broader maintenance subsystem.
    [main.cpp]
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2026-08-10 feat(sensor): add SHT4x environmental sensor
    Add support for Sensirion SHT4x temperature and humidity sensors.
    The implementation integrates entirely through the existing EnvNode
    Sensor platform and reuses the completed dual I²C resource architecture
    without requiring any infrastructure changes.
    The SHT4x publishes:
    using the existing Measurement pipeline, MQTT publisher and Home
    Assistant Discovery.
    Features
    - typed I²C resource configuration
    - I2C0 / I2C1 support
    - runtime rebuild support
    - persistent configuration
    - Enable / Disable
    - automatic Home Assistant Discovery
    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
    [ConfigurationService.cpp]
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2026-08-10 fix(resources): restore RainGauge GPIO compatibility
    Restore GPIO selection for the RainGauge after the BoardCapabilities
    capability-model refactoring.
    The previous hardware capability cleanup unintentionally prevented the
    RainGauge from finding compatible GPIO resources during configuration.
    The compatibility logic has been corrected while preserving the new typed
    GPIO capability model.
    Verification:
    - RainGauge GPIO selection restored
    - occupied GPIOs remain filtered
    - reserved I²C pins remain unavailable
    - AM2302 configuration unaffected
    - Runtime rebuild verified
    - Home Assistant Discovery unchanged
    This completes the migration to the finalized EnvNode GPIO capability
    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
2026-08-17 feat: add actuator slot configuration and unified hardware occupancy
    - add ActuatorId and fixed actuator slot configuration
    - add actuator implementation and capability registry
    - register reusable gpio_on_off implementation
    - persist actuator slots using stable implementation IDs
    - validate actuator hardware assignments against board capabilities
    - unify exclusive hardware occupancy checks across sensors and actuators
    - reject sensor/actuator and actuator/actuator resource conflicts
    - preserve shared I2C bus semantics for different device addresses
    - add native coverage for actuator registry and occupancy validation
    [Configuration.h, ConfigurationService.h]
2026-08-17 feat: add actuator runtime composition and capability lookup
    - add ActuatorFactory for deterministic actuator construction
    - add ActuatorRuntime for configured actuator lifecycle and lookup
    - construct gpio_on_off instances from enabled actuator slots
    - initialize runtime actuators from persisted hardware assignments
    - expose OnOff capability lookup by ActuatorId
    - retain runtime metadata and initialization status for diagnostics
    - isolate initialization failures between actuator slots
    - integrate ActuatorRuntime into application startup
    - remove the temporary hard-coded GPIO16 LED actuator
    - remove temporary actuator resource-conflict handling from main
    - keep actuator configuration changes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
    [main.cpp]
2026-08-17 feat: add configurable actuator Web UI and live runtime rebuild
    - add actuator slot overview and configuration pages
    - expose registry-driven hardware selection for actuator slots
    - control OnOff actuators through ActuatorId runtime lookup
    - add POST/Redirect/GET handling for actuator state changes
    - rebuild actuator runtime without restarting the device
    - safely shut down old GPIO actuators before replacement
    - activate updated actuator assignments at runtime
    - integrate actuator rebuild with RuntimeManager
    - remove redundant rebuild success logging
    - keep sensor and actuator hardware occupancy validation unified
    [ConfigurationRuntimeEffect.h]
2026-08-17 fix: make SerialLogger println byte-safe
    - replace null-terminated Serial.println output with explicit-length writes
    - emit CRLF explicitly for println messages
    - preserve runtime rebuild log messages byte-exactly
    - add regression coverage for println serial output
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2026-08-17 feat: add controller slot configuration and persistence
    - add ControllerId and fixed controller slot configuration
    - add Blink controller configuration with actuator target and timing parameters
    - add ControllerImplementationRegistry with stable implementation IDs
    - persist controller slots and Blink parameters in NVS
    - validate controller references against actuator capabilities
    - protect referenced actuators from incompatible configuration changes
    - allow multiple controllers to target the same compatible actuator
    - load controllers after actuators for reference validation
    - add native coverage for controller configuration and persistence
    [Configuration.h, ConfigurationService.h]
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2026-08-17 feat: add measurement source resolution infrastructure
    - add MeasurementSourceReference for SensorId and MeasurementType identity
    - add IMeasurementResolver as a read-only measurement lookup boundary
    - let MeasurementSnapshotCache provide latest snapshots through the resolver
    - add revision tracking independent of measurement age
    - preserve monotonic acceptance time for future freshness checks
    - invalidate snapshots cleanly across sensor runtime rebuilds
    - keep measurement validity, quality and interpretation policies controller-specific
    - add native coverage for source lookup, revisions, cache clear and snapshot isolation
2026-08-17 feat: add threshold controller configuration and references
    - add Threshold controller implementation metadata
    - add typed ThresholdControllerConfiguration
    - persist MeasurementSourceReference using stable measurement type IDs
    - validate numeric state measurement sources through metadata
    - validate OnOff actuator targets by capability
    - validate finite ordered threshold values and measurement freshness limits
    - protect referenced sensors from incompatible configuration changes
    - extend actuator/controller reference integrity to Threshold controllers
    - preserve disabled controller independence
    - keep Threshold runtime explicitly unsupported until runtime implementation
    - add native coverage f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
    [ConfigurationService.h]
2026-08-17 feat: add threshold controller runtime
    - add measurement-driven ThresholdController
    - implement non-blocking threshold and hysteresis evaluation
    - preserve Unknown state for initial values inside the hysteresis band
    - evaluate measurement freshness using monotonic snapshot age
    - process measurement revisions exactly once
    - retry pending actuator decisions without requiring new measurements
    - preserve last-command-wins semantics for external actuator commands
    - resolve actuator capabilities dynamically to avoid stale runtime pointers
    - support Threshold controllers in ControllerFactory and ControllerRuntime
    - preserve safe controller stop and live rebuild behavior
    - add native coverage for th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
    [main.cpp]
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2026-08-17 ui: improve dense table layouts
    - stabilize Measurement table columns for empty states
    - add consistent Sensor, Actuator and Controller summaries
    - improve Actuator control and action alignment
    - restructure Controller table presentation
    - prevent badge and button text from collapsing vertically
    - add horizontal table scrolling for narrow viewports
    - allow dense Actuator and Controller pages to use wider desktop layouts
    - preserve constrained widths for normal forms and detail pages
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2026-08-17 feat: publish retained actuator and controller descriptions
    - add retained MQTT description topics for actuators and controllers
    - publish schema v1 self-descriptions from persisted configuration
    - reconcile all description slots on MQTT connect and reconnect
    - republish descriptions after relevant configuration changes
    - clear stale retained descriptions for None slots
    - preserve descriptions for disabled configured slots
    - retry failed description publications cooperatively
    - keep runtime state separate from static self-description
    - document MQTT self-description lifecycle and current root limitation
    - add coverage for publication, reconciliation and retained cleanup
    [main.cpp]
2026-08-17 feat: add structured logging core
    - add structured log levels and owned log entries
    - add monotonic and optional wall-clock timestamps
    - add sequence numbers for log correlation
    - add bounded fixed-size recent log ring buffer
    - copy and normalize log messages into owned storage
    - preserve legacy println and printf compatibility
    - store canonical log entries before serial output
    - add deterministic filtering and truncation behavior
    - add native coverage for logging, timestamps and ring-buffer behavior
    [main.cpp]
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2026-08-17 Perform a focused logging-severity and diagnostic-quality cleanup for EnvNode.
    Structured logging is already implemented and physically verified:
    - DEBUG / INFO / WARN / ERROR
    - canonical LogEntry
    - sequence numbers
    - monotonic timestamps before time synchronization
    - wall-clock timestamps afterwards
    - RecentLogStore
    - Serial rendering
    - read-only Web log viewer at /logs
    Do not redesign the logging architecture.
    The goal of this commit is:
    1. classify existing operational log messages by meaningful severity
    2. improve the diagnostic usefulness of ThresholdController logging
    3. keep normal INFO logging concise
    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
    [GpioOnOffActuator.cpp, main.cpp]
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2026-08-21 Fixed BOM for EnvNode and updated PCB (no breaking Changes)
    [BOM_Mainboard.xlsx]
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2026-08-21 Update `docs/AnalogMeasurements.md` to record the current implementation status before pausing analog-sensor development.
    Add a short, clearly visible section such as `## Current Implementation Status`.
    It must state:
    - `IAnalogInput`, `AverageAnalogSampler`, two-point calibration, and `AnalogPressureSensor` are implemented and covered by native tests.
    - `AnalogPressureSensor` contains the domain logic for hydrostatic pressure, optional water level, electrical validity boundaries, and `below_measurement_range`.
    - The sensor is not yet integrated into the running EnvNode firmware.
    - No concrete `IAnalogInput` backend exists yet.
    - The sensor is not registered in `SensorImplementationRegistr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
2026-08-23 Fixed Title, Revision
    [AnalogInput.kicad_pcb, AnalogInput.kicad_sch]
2026-08-23 docs(architecture): define board identity and provisioning
    Document the architecture for EEPROM-backed EnvNode board identity and
    future hardware provisioning.
    - distinguish physical BoardIdentity from firmware-defined BoardProfile
    - define EEPROM identity as the preferred long-term board identity source
    - retain build-time BoardProfile selection as an explicit development fallback
    - resolve board identity before board-dependent hardware initialization
    - keep BoardProfile immutable for the duration of a boot
    - define provisioning as a reusable, isolated capability
    - prepare reuse by a future dedicated provisioning firmware
    - define validation and handling of invalid or unsupported board ide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
2026-08-23 feat(identity): resolve board profile at boot
    [BoardProfile.cpp, main.cpp]
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2026-08-24 Fixed Footprint-Assignments, DesignBlocks
    [EnvNode.kicad_pcb, EnvNode.kicad_sch, SolarRadiation.kicad_sch]
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2026-08-25 feat(hardware): add EnvNode Mini rev 0.1
    - add EnvNode Mini mainboard based on the EnvNode design blocks
    - provide fullsize and halfsize daughterboard slots
    - expose 24 V, 5 V, 3.3 V, I2C and dedicated GPIO pairs
    - add two JST-SH connectors for I2C displays and peripherals
    - add optional onboard I2C pull-ups
    - generate 5 V and 3.3 V locally from the 24 V input
    - add fuse, reverse-polarity protection, TVS protection and input filtering
    - widen power routing and retain short connector fanouts
    - add ESP32-DevKitC core and board identification EEPROM
    - add module outlines, WLAN keep-out and slot labeling
    - pass PCB DRC with no violations or unconnected pads
    [EnvNodeMini.kicad_pcb, EnvNodeMini.kicad_sch, SlotA.kicad_sch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]
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2026-08-26 feat(hardware): update FullSize empty module template
    - update schematic and PCB from the daughterboard design block
    - preserve linked design block groups and connector references
    - correct connector alignment and power routing widths
    - remove duplicate same-net routing
    - validate pinout, geometry, ERC, and DRC
    [EmptyModule_FullSize.kicad_pcb, EmptyModule_FullSize.kicad_sch]
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2026-08-26 docs(hardware): document DuoRelay module
    - document interface pinout and relay driver circuits
    - define resistive and inductive load limits
    - record intentional mirrored terminal assignments
    - document 250 VAC routing and custom clearance rule
    - add mechanical safety and bring-up requirements
    - update the hardware index and interface specification
2026-08-26 feat(hardware): add DuoRelay FullSize module
    - add dual 5 V relay driver circuitry
    - provide safe GPIO default states and flyback protection
    - route 250 VAC contact nets on F.Cu without vias
    - enforce 8 mm clearance between contact and SELV copper
    - add mirrored and labeled NO-COM-NC terminals
    - validate schematic, PCB, ERC, and DRC
    [DuoRelay.kicad_pcb, DuoRelay.kicad_sch]
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2026-09-01 Fix EEPROM values and DuoRelay R5 footprint
    [AnalogHydroPressure.kicad_sch, DuoRelay.kicad_pcb, DuoRelay.kicad_sch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]
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2026-09-08 AnalogHydroPressure: update to Rev 0.4
    - replace I2C bus selection switch with solder jumpers
    - upgrade boost Schottky diode to B260S1F-7 (60 V, 2 A, SOD-123F)
    - add test points for GND, 24V, Loop_Return and AIN0
    - update PCB layout for revised components
    [24VBoost.kicad_sch, Analog.kicad_sch, AnalogHydroPressure.kicad_pcb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]
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2026-09-20 Add WiFi connection failure diagnostics
    [ConfigurationService.cpp]
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2026-09-21 fix(hardware): use SMD JST-PH on ORing power module
    [EnvNode_Parts.xlsx, ORing Power.kicad_pcb, ORing Power.kicad_sch]
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2026-09-28 fix(hardware): move SolarRadiation shunt to front and update jumpers
    [SolarRadiation.kicad_pcb, SolarRadiation.kicad_sch]
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2026-09-28 hardware(weather): swap slot GPIO4 with GPIO33 for analog input
    [Weatherstation.kicad_pcb, Weatherstation.kicad_sch, gpio.kicad_sch]
2026-09-28 hardware(mini): release revision 0.7 with corrected module I2C0 pinout
    [EnvNode Mini.kicad_pcb, EnvNode_Module_Connector_MainBoard.kicad_sch, SlotA.kicad_sch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]
2026-09-28 hardware(weather): finalize revision 0.2 with corrected module I2C0 pinout
    [SlotA.kicad_sch, Weatherstation.kicad_pcb]
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2026-09-29 hardware(sct013): correct tip connection and label ADC port
    [SCT013Head.kicad_pcb, SCT013Head.kicad_sch]
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2026-10-06 Fix module actuator configuration and cache boot I2C diagnostics
    [ConfigurationService.cpp, main.cpp]
2026-10-06 Add typed local properties and configurable text preview
    Expose Sensor values, On/Off Actuator states and stored Threshold evaluation
    reasons through a shared read-only PropertyResolver. Keep runtime bindings
    fresh across rebuilds and preserve optional metadata explicitly.
    Add Measurements diagnostics and a one-source text preview with bounded,
    type-checked printf-style formatting and escaped HTML. Preview selections
    remain in the URL; MQTT contracts and hardware configuration are unchanged.
    Validation: all 298 native tests pass; esp32dev firmware build succeeds.
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2026-10-27 Add configurable SD system logging and validated rotation diagnostics
    Include SD support in the default firmware, persist storage settings, and add buffered JSONL recording with rotation and bounded retention. Serialize storage access and move directory reads and rotation diagnostics to background tasks.
    Record successful hardware validation of rotation, cleanup, and automatic browser results. Keep intermittent FAT VFS mount failures and measured blocking HTTP latency explicitly open for follow-up. Default ESP32 build and affected native tests pass.
2026-10-28 Update Mini to 0.9.0 and Weatherstation to 0.3.0
    Add TP1 test reference connections isolated through D1/D2 from GND and +3V3_SYS. Replace I2C solder jumpers with removable pull-up jumpers and add C2 for local EEPROM supply decoupling.
    Update schematics, PCB layouts, revision markings and KiCad project settings to match the documented hardware revisions.
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2026-10-31 Correct Input Adapter pinheader mounting and pigtail assembly
    Mount the J4 test plug headers on the back of the adapter. Count only the 38 J4 contacts in the parts list and solder the TP1 pigtail wires directly to the pads without a 1x2 header.
    Update the PDF reference and validation record, and note the pending KiCad DNP change for TP1.
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2026-11-14 Integrate SCT013 current sensing with ADC DMA recovery
    Add calibrated RMS current acquisition, filtering and zero hysteresis to the regular firmware, with persistent configuration, MQTT/Home Assistant support and board ADC port labels. Share signal processing with the lab firmware and include the SCT013Head Rev. 0.2 jack correction.
    Recover from DMA failures through bounded reinitialization and discard incomplete windows. Keep firmware version 0.8.14. Sporadic DMA interruptions remain under observation in the hardware endurance test; recovery succeeds in observed runs.
    Validation: ESP32 build, 22 sensor/configuration tests and DMA fault-injection checks passed; staged whitespace check pass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
